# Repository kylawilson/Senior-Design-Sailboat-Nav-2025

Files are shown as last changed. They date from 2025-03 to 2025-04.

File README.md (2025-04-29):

# Senior-Design-Sailboat-Nav-2025

```
Senior-Design-Sailboat-Nav-2025
│   README.md  
│
└───Anemometer
│   │   AneTest.py
│   │   WindDirection1.py
│   │   WindSpeed.txt
│   
└───GPS
│   │   GPSDbusTest.py
│   │   gps_dbus_test
│
└───HARDWARE-REPORT
│   │   README_Hardware.md
│   └───DATASHEETS
│       │   Aluminum_pole.pdf
│       │   DS-15901-Weather_Meter.pdf
│       │   FlangeSpecs.pdf
│       │   GPS-Module-Datasheet.pdf
│       │   OAK-D-S2_Datasheet.pdf
│       │   PowerBank_Main.pdf
│       │   PowerBank_Secondary.pdf
│       │   RJ11_schematic.pdf
│       │   Rubber_ring_specs.pdf
│       │   StereoPiV2Schematic.jpg
│       │   StereoPi_07292021_STPI2_SLM_01-2499177.pdf
│       │   SwivelSafetyHaspSpecs.pdf
│       │   Tectite Electrical Plastic Adapter Connector Conduit Fittings.pdf
│       │   adafruit-4-channel-adc-breakouts.pdf
│       │   cm4-datasheet.pdf
│       │   coupler_datasheet.pdf
│
└───LAUNCHER-SCRIPTS
│   │   oakd_launcher.sh
│   │   ...
│
└───OAK-D
│   │   MRS_Video.py
│   │   Triton.py
│   │   Waterline.py
│   └───models
│       │  ... 
│  
└───PREVIOUS-REPORTS
│   │   Customer Installation Report.pdf
│   │   Final Testing Report.docx
│   │   Final Testing Slides.pptx
│   │   ...
│
└───RPI-BLUETOOTH
│   │   bluetooth.py
│   │   README_Bluetooth.md
│   │   BluetoothInterfaceChart.jpeg
│
└───SOFTWARE-REPORT
│   │   README_Software.md
│
└───STEREOPI-BLUETOOTH
│   │   bluetooth.py
│   │   README_StereopiBluetooth.md
│
└───Triton
│   │   README_Triton.md
│   └───Triton
│       │  All_camera_10_points.swift
│       │  BluetoothService.swift
│       │  ContentView.swift
│       │  DataStructs.swift
│       │  ImageConversion.swift
│       │  info_tabs.swift
│       │  Info.plist
│       │  ServiceDefinitions.swift
│       │  TritonApp.swift
│
└───stereopi
│   │   7_2d_mapPROTO.py
│   │   Triton.py
│   └───calibration_data
│   │   │  ...
│   └───pairs
│       │  ...
```

This repo contains all of the relevant information for the Triton: a portable, multi-sensor system that provides useful information to the sailor via a mobile iOS application, including object sensing and visualization, GPS data, wind speed and direction, and speed over ground. The Triton's primary function being to assist sailors when docking or maneuvering through crowded areas, such as a busy port. The Triton consists of three separate sensing modules attached to the bow, starboard, and port areas of the boat. Each of these modules communicates via Bluetooth Low Energy. The data from each of these modules is continuously offloaded to the connected iOS device in real time, giving the operator the most up-to-date information about the current conditions.

**STEREOPIS (PERIPHERAL MODULES)**\
OS: Raspberry Pi Debain Bullseye 32-Bit Full Legacy (Released 10/22/2024)\
StereoPi Version: StereoPi V2 Slim\
Raspberry Pi Device: Compute Module 4, 1GB, Wireless (SC0691)

**RASPBERRY PI (CENTRAL MODULES)**\
OS: Raspberry Pi Debian Bookworm 64-Bit (Released 11/19/2024)\
Raspberry Pi Device: Raspberry Pi 3B

**COMMANDS, TIPS & TRICKS THAT CAME IN HANDY**
To activate virtual environment:\
source ./bin/activate

To get bluetooth working on Raspberry Pis:\
sudo systemctl start bluetooth

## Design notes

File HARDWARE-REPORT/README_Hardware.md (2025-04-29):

insert readme contents here
" Also includes a document highlighting how to setup the project and connect to external systems, sensors, etc.

• Schematic / PCB / CAD diagrams of all components of your project: please include in PDF format
AND the actual CAD / CAM files (would you want to redraw them from scratch?)
• Vendor information and Bill of Materials (BOM).
• References to significant data sheets, application notes, design templates, etc.
• Power requirements (voltage, current, power supply model, etc.).
• Clear picture of system inside the enclosure – use multiple angles if necessary.
• Significant data sheets, application notes, design templates, web resources.
• Photographs documenting the assembled system 

"

**Hardware Installation and Setup:**

The Triton is composed of three individual sensor modules that contain stereo cameras and other sensors to relay data to the app. These modules are placed within semi-permanent mounts that the user must install at specific locations on their ship prior to first use. (see Figure 1)

*Initial Installation*
- Using a flathead screwdriver, attach and tighten the hose clamps of the central module to the railing at the bow of the boat, ensuring the camera is facing away from your ship.  (Position 1 in Figure 1)
- Wrap the velcro on the sides of the module around a portion of the railing so that it is taut and attach the remaining slack to the velcro attached to the module. For best security, wrap it around the pole at least two times.  
- Using the flathead screwdriver, attach and tighten the hose clamps of the side modules to lifelines(side railings) at or close to the widest part of your boat. (Left module Position 2 and Right module Position 3 in Figure 1)
- Make sure to push down on both side modules to ensure the suction cups on the bottom of the modules are attached.
- Tighten or loosen the attached velcro so that it is snug against the lifeline pole and attach the remaining slack to itself.

*Before Every Use* 
- Connect the battery pack to each of the modules to power on the devices.
- Place each module in their respective mounted frames, making sure the modules are fully sealed to the frames.
- Place the buckle on the module on the latch attached to the frame and turn the latch so that it is in a horizontal position.  
- For best readings, raise the telescoping pole attached to the anemometer, wind vane, and GPS antenna by twisting the metal adjuster to the left to loosen and raise the pole then twisting the adjuster to the right to tighten and lock the position of the pole in place.
- Launch the iOS application and connect to the modules

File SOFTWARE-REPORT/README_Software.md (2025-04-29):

insert readme contents here
"Source code and executables along with the
accompanying documentation on how to
setup/compile your project and transfer code to
a target platform.

An overview of each software module
• A flow chart indicating the dependencies between these functions. For instance, if you have a
main.py and LCD.py, you need to show that LCD.py is a module used by main.py.
• Dev/build tool information: Package name and version info. For example, OpenCV 4.0.3 with
Python 3.8.1, using CUDA Toolbox 10.0 and GCC 9.1 and CMake 3.14.2
• How to install the project software stack from scratch (a blank hard drive / cloud instance) Please
provide concise documentation on what installation software is needed, and how to build from
source to binary as applicable. 

"

```
Senior-Design-Sailboat-Nav-2025
│   README.md  
│
└───Anemometer
│   │   AneTest.py
│   │   WindDirection1.py
│   │   WindSpeed.txt
│   
└───GPS
│   │   GPSDbusTest.py
│   │   gps_dbus_test
│
└───HARDWARE-REPORT
│   │   README_Hardware.md
│   └───DATASHEETS
│       │   Aluminum_pole.pdf
│       │   DS-15901-Weather_Meter.pdf
│       │   FlangeSpecs.pdf
│       │   GPS-Module-Datasheet.pdf
│       │   OAK-D-S2_Datasheet.pdf
│       │   PowerBank_Main.pdf
│       │   PowerBank_Secondary.pdf
│       │   RJ11_schematic.pdf
│       │   Rubber_ring_specs.pdf
│       │   StereoPiV2Schematic.jpg
│       │   StereoPi_07292021_STPI2_SLM_01-2499177.pdf
│       │   SwivelSafetyHaspSpecs.pdf
│       │   Tectite Electrical Plastic Adapter Connector Conduit Fittings.pdf
│       │   adafruit-4-channel-adc-breakouts.pdf
│       │   cm4-datasheet.pdf
│       │   coupler_datasheet.pdf
│
└───LAUNCHER-SCRIPTS
│   │   oakd_launcher.sh
│   │   ...
│
└───OAK-D
│   │   MRS_Video.py
│   │   Triton.py
│   │   Waterline.py
│   └───models
│       │  ... 
│  
└───PREVIOUS-REPORTS
│   │   Customer Installation Report.pdf
│   │   Final Testing Report.docx
│   │   Final Testing Slides.pptx
│   │   ...
│
└───RPI-BLUETOOTH
│   │   bluetooth.py
│   │   README_Bluetooth.md
│   │   BluetoothInterfaceChart.jpeg
│
└───SOFTWARE-REPORT
│   │   README_Software.md
│
└───STEREOPI-BLUETOOTH
│   │   bluetooth.py
│   │   README_StereopiBluetooth.md
│
└───Triton
│   │   README_Triton.md
│   └───Triton
│       │  All_camera_10_points.swift
│       │  BluetoothService.swift
│       │  ContentView.swift
│       │  DataStructs.swift
│       │  ImageConversion.swift
│       │  info_tabs.swift
│       │  Info.plist
│       │  ServiceDefinitions.swift
│       │  TritonApp.swift
│
└───stereopi
│   │   7_2d_mapPROTO.py
│   │   Triton.py
│   └───calibration_data
│   │   │  ...
│   └───pairs
│       │  ...
```

**HOW TO SET UP SOFTWARE ON A NEW RASPBERRY PI**
1. Clone this repo (Senior-Design-Sailboat-Nav-2025) in the top level of your Raspberry Pi
2. Ensure that the paths used in LAUNCHER-SCRIPTS/oakd_launcher.sh match the layout of your device (it should as long as you clone the repo in the right place)
3. Edit the crontab (sudo crontab -e)
4. Add this line to the crontab: @reboot ~/Senior-Design-Sailboat-Nav-2025/LAUNCHER-SCRIPTS/oakd_launcher.sh
5. Reboot the pi (sudo reboot) 

**HOW TO SET UP SOFTWARE ON A STEREOPI/CM4**
1. Clone this repo (Senior-Design-Sailboat-Nav-2025) in the top level of your StereoPi/CM4
2. Ensure that the paths used in LAUNCHER-SCRIPTS/stereopi_launcher.sh match the layout of your device (it should as long as you clone the repo in the right place)
3. Edit the crontab (sudo crontab -e)
4. Add this line to the crontab: @reboot ~/Senior-Design-Sailboat-Nav-2025/LAUNCHER-SCRIPTS/launcher.sh
5. Reboot the pi (sudo reboot) 

**List of Dependencies**
- Python Version 3.11.2
- dbus-python Version 1.0
- PyGObject Version 3.0

**WHAT DOES EACH MODULE DO?**
Read the READMEs in each folder to find out!

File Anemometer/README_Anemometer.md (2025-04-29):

**DEPENDENCIES**
- dbus-python 1.3.2
- gobject 0.1.0
- adafruit_ads1x15
- adafruit_blinka 8.56.0
- RPi.GPIO 0.7.1

**DEVICE REQUIREMENTS**
- Raspberry Pi 3B with Raspberry Pi OS Debian Bookworm 64-Bit
    
**OVERVIEW OF EACH SOFTWARE MODULE**\
*AneTest.py* - This file reads wind speed data from a GPIO pin connected to the anemometer. It counts pulses from the anemometer to calculate the wind speed in meters per second, then converts it to knots. The result is written to a text file (WindSpeed.txt) once per second.\ 
*WindDirection1.py* - This file reads wind direction data using an ADC connected over I2C. It calculates resistance values from voltage readings to determine wind direction based on predefined resistance ranges. The result is made available over a DBus service, allowing other applications to query the current wind direction. The file initializes the ADC, sets up and runs a D-Bus service, and continuously samples and averages multiple readings from the anemometer to improve accuracy.

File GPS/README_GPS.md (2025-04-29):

**DEPENDENCIES**
- WiringPi (<wiringSerial.h>)
- <dbus/dbus.h>
- <sys/time.h>

**DEVICE REQUIREMENTS**
- Raspberry Pi 3B with Raspberry Pi OS Debian Bookworm 64-Bit
    
**OVERVIEW OF EACH SOFTWARE MODULE**\
*GPSDbusTest.cpp* - This file interfaces with the Adafruit Flora GPS module over a serial connection. It processes NMEA sentences (GGA, RMC, PGTOP) to extract GPS data such as latitude, longitude, speed, and course over ground. The data is then made available via DBus. The service listens for requests for GPS data and responds with the latest parsed information. The code  continuously reads from the GPS and updates the D-Bus service.\ 
*gps_dbus_test* - This is the executable version of GPSDbusTest.cpp

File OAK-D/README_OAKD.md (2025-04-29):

• An overview of each software module
• A flow chart indicating the dependencies between these functions. For instance, if you have a
main.py and LCD.py, you need to show that LCD.py is a module used by main.py.
• Dev/build tool information: Package name and version info. For example, OpenCV 4.0.3 with
Python 3.8.1, using CUDA Toolbox 10.0 and GCC 9.1 and CMake 3.14.2

Software Overview:
Triton.py: The OAK-D and Trition's object detection script that utilizes both the neural net object tracking as well as the grid system
to record and determine the relevant data of detected objects and prepare the data to be sent to the app. The detection system consists
of two parts, a 10x10 grid of region of interests which records the depth of each region through openCV. The minimum distance for each
ROI column is then recorded and stored in an array. The second system is a neural net that identifies and tracks boats and draws a dynamic
ROI around each object and records the distance of the object (if within range) and its position relative to the camera. The data from the
two systems in then stored and sent over DBUS and then sent via BLE to the app.

MRS_Video.py: Testing script for recording video of the multi ROI grid object dection system

OTV.py: Testing script for recording video of the neural network and object tracking system

Waterline.py: Testing script for unfinished feature to dynamically track the horizon so that the system can actively ignore depth readings
from the surface of the water. Based of the work done by Tim Huff to dynamically track the horizon for autonomous drones. Uses open CV to
track features on the horizon and draw an estimated horizon line.

**DEPENDENCIES**
- blobconverter             1.4.3
- depthai                   2.28.0.0
- opencv-python             4.10.0.84
- nbclient                  0.10.2
- nbconvert                 7.16.6
- nbformat                  5.10.4
- Python                    3.11
- dbus-python 1.3.2

**DEVICE REQUIREMENTS**
- OAK-D Stereo Camera
- Raspberry Pi 3B

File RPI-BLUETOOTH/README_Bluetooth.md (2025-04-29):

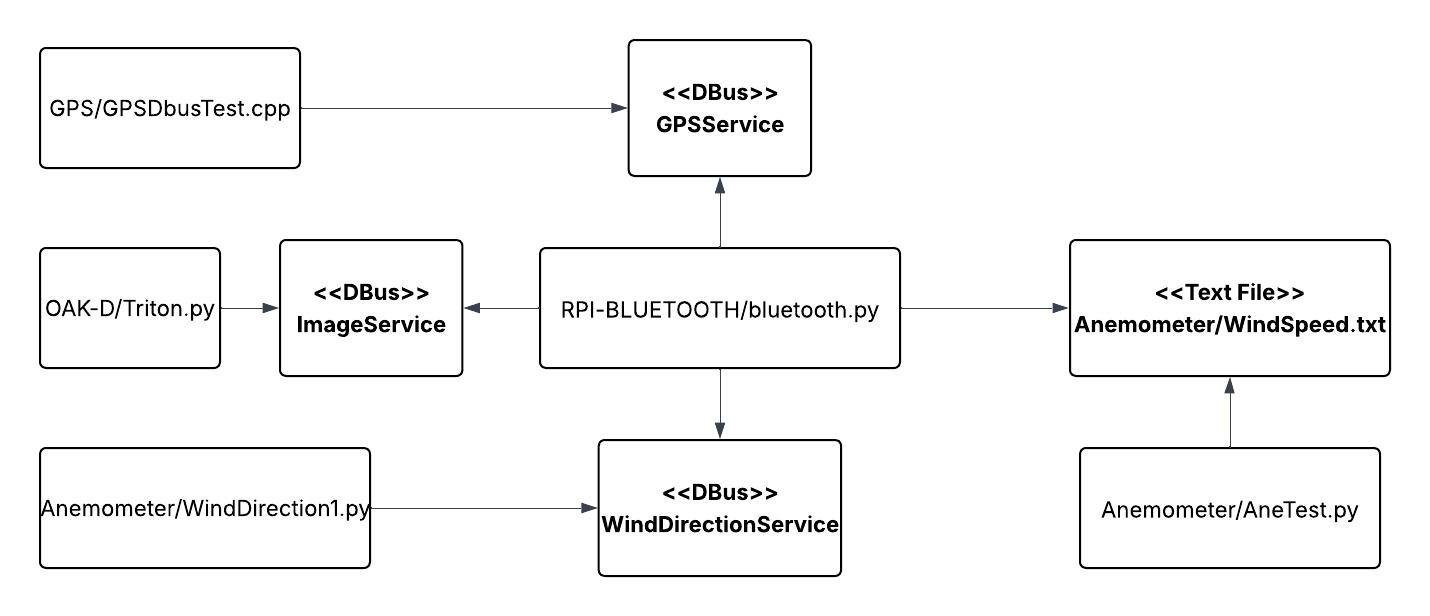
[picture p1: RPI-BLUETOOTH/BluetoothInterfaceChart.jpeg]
Flowchart Bluetooth Interface Chart


**DEPENDENCIES**
- dbus-python 1.3.2
- gobject 0.1.0
- pillow 11.10
- datetime 5.5
- Python 3.11
- ../OAK-D/Triton.py
- ../GPS/gps_dbus_test
- ../Anemometer/AneTest.py and ../Anemometer/WindDirection1.py

**DEVICE REQUIREMENTS**
- Raspberry Pi 3B with Raspberry Pi OS Debian Bookworm 64-Bit
- To Run Dependencies:
    - Oak-D Camera
    - Adafruit Flora GPS Module
    - Anemometer (Wind Direction and Speed)
    - 16-Bit ADC
    
**OVERVIEW OF EACH SOFTWARE MODULE**\
bluetooth.py - This file enables Bluetooth Low Energy communication with the iOS device (see the ../Triton folder). It registers the GATT server, advertisements, services, and characteristics. This file also collects information from the OAK-D camera via dbus, the GPS module via dbus, the Wind Direction module via dbus, and the Wind Speed module via a file.

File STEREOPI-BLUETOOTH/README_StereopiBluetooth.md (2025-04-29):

**DEPENDENCIES**
- dbus-python 1.3.2
- gobject 0.1.0
- ../stereopi/7_2d_map_PROTO.py

**DEVICE REQUIREMENTS**
- StereoPi V2 Slim with a Raspberry Pi Compute Module 4 running Raspberry Pi Debian Bookworm 64-Bit
- Two Raspberry Pi Cameras
    
**OVERVIEW OF EACH SOFTWARE MODULE**\
bluetooth.py - This file enables Bluetooth Low Energy communication with the iOS device (see the ../Triton folder). It registers the GATT server, advertisements, services, and characteristics. This file also collects information from the stereo cameras, reading from tempmax_log.txt in the ../stereopi folder to collect these values once every second.

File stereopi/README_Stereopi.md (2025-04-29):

**StereoPi Code**

Utilizied for StereoPi Sensors.

**Dependencies:**

Raspberry Pi Debain Bullseye 32-Bit Full Legacy

Python3.11

OpenCV 3.4.3

Picamera 1.13

These files enable functionality of the Stereopi cameras and allow them to track depth and to map distance.

**Overview of Modules:**

1_test_py - shows camera preview, ensures that cameras are functioning

2_chess_cycle.py - Takes a series of 50 pictures for stereo calibration. Pictures need to have a chessboard design.

3_pairs_cut.py -Takes the samples from 2_chess_cycle.py and arranges the left and right phots into pairs.

4_calibartion_fisheye.py - Takes the samples from 3_pair_cut.py to create the Calibration Data.

5_dm_tune.py - Adjuts the Disparity Map for precise needs.

6_dm_video.py - Builds the disparity map.

7_2d_map.py - Builds the depth map.

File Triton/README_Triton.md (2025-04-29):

<p align="center">
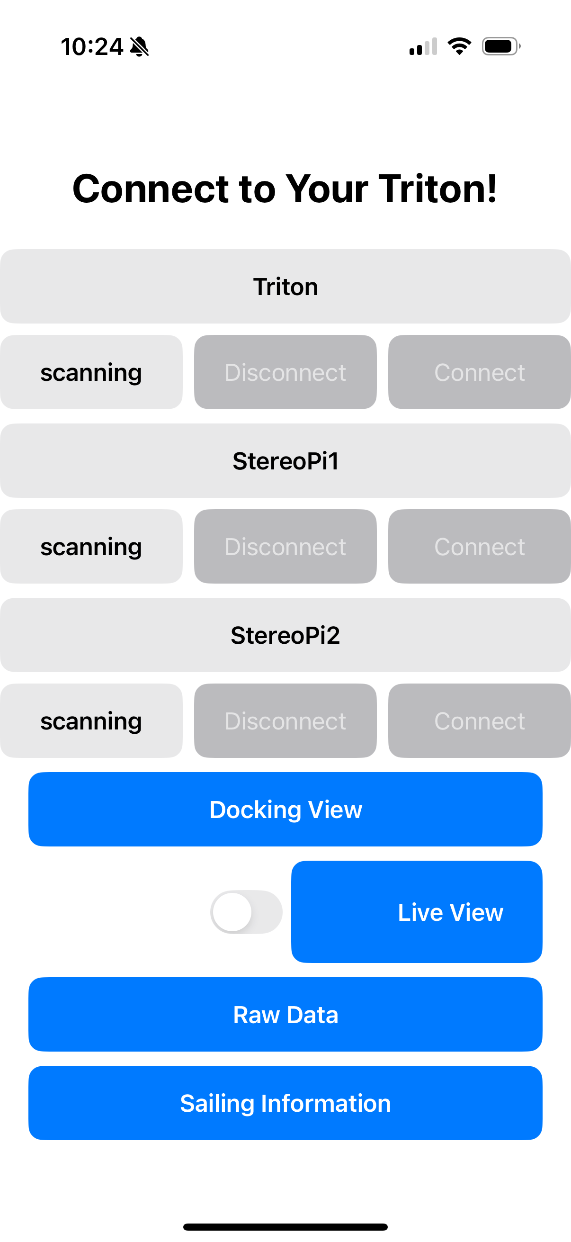
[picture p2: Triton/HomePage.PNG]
Home Page of App
  
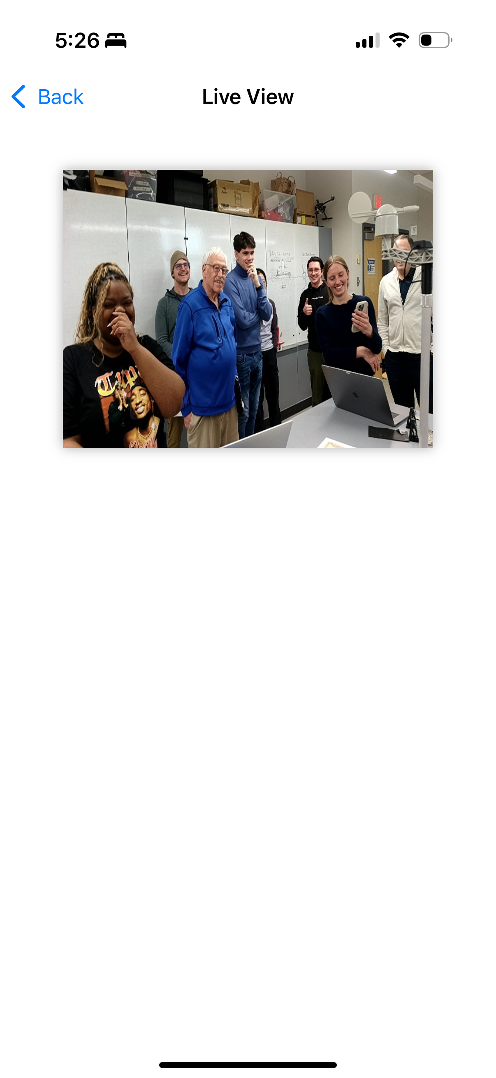
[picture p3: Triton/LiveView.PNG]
App's Live View
  
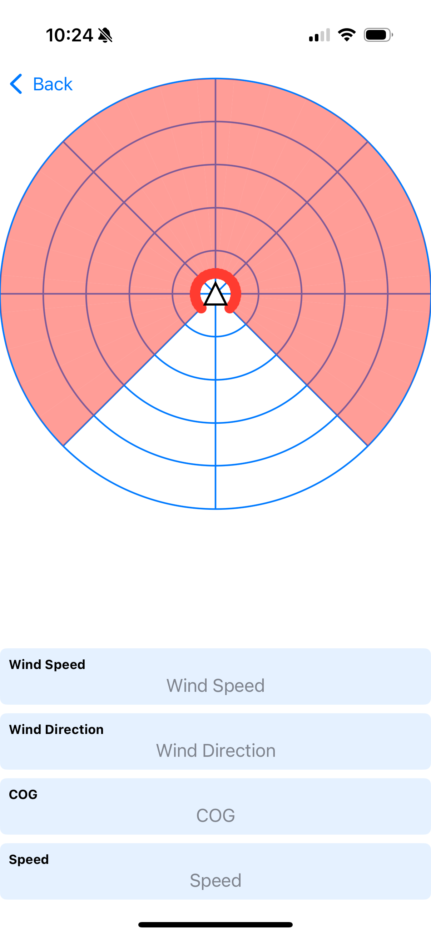
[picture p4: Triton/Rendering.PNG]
Rendering Default
  
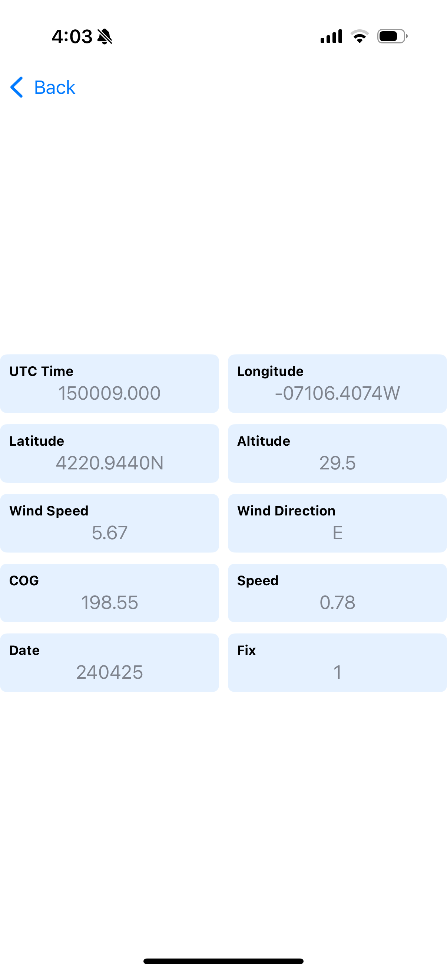
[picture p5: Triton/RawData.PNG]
Populated Raw Data Page
  
</p>

**DEPENDENCIES**
- CoreBluetooth
- SwiftUI
- XCode 16.3 or Higher

**DEVICE REQUIREMENTS**
- For Development: A Mac with XCode 16.3 or Higher
- For Running the App: An iPhone with iOS 18 or Higher

**DEVICES USED**
- For Development: MacBook Pro, 16-inch, 2019, macOS Sequoia 15.3.2
- For Testing: 
    - iPhone 11 Pro, iOS 18.1.1
    - iPhone 16 Pro, iOS 18.3.2
    
**OVERVIEW OF EACH SOFTWARE MODULE**\
*All_camera_10_points.swift* - This is the code that converts the depth and object recognition data provided by the OAK-D and StereoPi cameras. The cameras use a grid-like depth map and send the smallest distance for each column over Bluetooth. The rendering converts each distance value into a polar point on a map. As the depth values change, the polar points adjust their position accordingly. If the OAK-D detects a boat or person they will be represented as a colored triangle at their approximate location or on the edge of the map if they are farther than 15 meters away.\
*BluetoothService.swift* - This is the code that controls and manages the bluetooth connection between the iOS device and the Triton (main module) and StereoPis (peripheral modules). This includes connecting, disconnecting, discovering services, receiving and parsing data, and more.\
*ContentView.swift* - This is the top-level file that defines the application's UI and layout.\
*DataStructs.swift* - This file contains two of the data structs that we created to organize our data better: one for GPS data and one for Anemometer data. This allows us to have simpler data extraction for the UI once the data is parsed in BluetoothService.\
*ImageConversion.swift* - This file contains all of our functions related to converting the serial data of the OAK-D's live view to a viewable image within the application.\
*info_tabs.swift* - This is a section that delivers general information for how to safely approach and dock a ship as well as what the proper right of way rules are regarding open sailing.\
*Info.plist* - This is the information property list file, a file used by Apple that contains configuration information for the application. The most important use of this in our app is for Bluetooth permissions.\
*ServiceDefinitions.swift* - This file contains all of the Service Definitions for our app. It contains all of the UUIDs for the characteristics, services, and connection statuses.\
*TritonApp.swift* - This is the top level module that is our app. It instantiates ContentView to display our UI within Swift's app structure.\

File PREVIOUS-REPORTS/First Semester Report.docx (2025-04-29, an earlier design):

# Boston University

# Electrical & Computer Engineering

# EC463 Senior Design Project

# First Semester Report

Triton

Submitted to

Ryan Lagoy

1 Silber Way

Boston, MA 02215

(617)-877-2569

rlagoy@bu.edu

by

Team 25

Sail-Nav Technologies

Team Members

Leyandra Burke lburke@bu.edu

Kevin Connell kconn7@bu.edu

Diego D’Angelo-Cosme diegodc@bu.edu

Matthew Guacho mguacho@bu.edu

Kyla Wilson kylaw@bu.edu

Submitted: 12/08/2024

#### Table of Contents

Executive Summary (Diego D’Angelo-Cosme) 2

1.0 Introduction (Matthew Guacho) 1

2.0 Concept Development (Kyla Wilson) 2

3.0 System Description (Kevin Connell and Kyla Wilson and Leyandra Burke) 5

4.0 First Semester Progress (Diego D’Angelo-Cosme and Kevin Connell and Kyla Wilson and Leyandra Burke and Matthew Guacho) 7

5.0 Technical Plan (Leyandra Burke and Matthew Guacho) 11

6.0 Budget Estimate (Diego D’Angelo-Cosme) 14

7.0 Attachments (Diego D’Angelo-Cosme) 15

7.1 Appendix 1 – Engineering Requirements 15

7.2 Appendix 2 – Gantt Chart (Leyandra Burke) 16

7.3 Appendix 3 – Prototype Circuit Diagram (Diego D’Angelo-Cosme) and Pinout (Kyla Wilson) 18

7.4 Appendix 4 – Other Appendices 20

(right click on Table of Contents to update fields and page numbers automatically)

# Executive Summary (Diego D’Angelo-Cosme)

Sailboat Navigation and Docking Assist: The Triton

Team 25 – Sail-Nav Technologies

Maritime navigation and docking can be incredibly challenging, especially on a sailboat; there are many environmental factors and visual limitations that can prove challenging for both new and experienced sailors. Team 25 has proposed ‘The Triton’ to solve this issue. The Triton is a portable, multi-sensor system that will provide useful information to the sailor including object sensing and detection, GPS data, wind speed and direction, speed through water, and speed over ground. This will be done using an anemometer, a paddle wheel, a GPS module, and multiple stereo cameras mounted around the vessel. Many sailboats do not have sensors and rely on a sailor’s general knowledge and expertise, so this device will allow newer sailors to gain experience docking and navigating while also providing a reliable information system for those with more experience.

# 1.0 Introduction (Matthew Guacho)

Nautical voyages can be extremely dangerous: the margin of error is wide and the price to pay is massive. In fact, in 2023 alone, 564 people perished and 63 million dollars in damages were attributed to boating-related accidents. One of the most challenging parts of nautical activities is docking the vessel, with crowded ports and outside factors, such as wind or currents, potentially leading to accidents. Our client wishes to make a system that solves this problem: a system that aids the sailor, regardless if they are a novice or a master, in docking their vessel, as well as offering some assistance with marine voyages.

Team 25 aims to solve this problem with The Triton, a multi-sensor system designed for docking and nautical navigation. The Triton will implement multiple sensors that sense vital information during the boating experience, and send all relevant information to an iOS phone application via Bluetooth low energy (BLE). Using this information, the app will make recommendations to the user during the docking process. The system will be able to detect nearby objects, sense wind speed and direction, utilize GPS information to obtain speed over ground (the speed of a vessel over the Earth's surface), and to be able to measure the speed through water (speed of vessel in relation to the water). All of these attributes will give the sailor an in-depth understanding of the current sailing conditions, giving the sailor information that they would otherwise not have access to. Utilizing this information, the sailor can know how to react to certain situations given the current conditions, and even get recommendations as to what actions should be taken.

Team 25’s approach to creating the Triton is to make a system that is reliable, yet cost effective. There are other nautical assistance systems on the market, but they lack any real aid when it comes to docking by sail, and they can be exceedingly expensive, with some systems costing as much as 10 thousand dollars. Additionally, few systems are compatible with sailboats. The Triton will use essential sensors that can solve the docking problem in the most cost efficient way possible, as well as lasting as long as 12 hours, being able to withstand harsh weather conditions, and be used on a wide gamut of nautical vessels. Using the iOS app, the product can also expound what would be the wisest decision when it comes to docking, answering our client’s request to give sailors more knowledge to tackle marine situations. This will give the sailor a full understanding of their environment, thus giving them the information needed to effectively respond to any situation. With the ability to recommend actions as well, The Triton can help sailors of any skill level, whether they are just beginning or master voyagers.

Special features of The Triton include a full suite of sensors that read essential information, an app that can show such information and make recommendations to the user, and weigh at most 25 pounds. This ensures that anyone can use the system and that it can be easily installed, removed, and transported.

# 2.0 Concept Development (Kyla Wilson)

Understanding the Problem

To properly address our client’s problem, we first needed to understand the challenges faced by sailors out on the water. While no one in our group is a sailor, we all chose the project because of its unique challenges and the opportunity it gave each of us to develop our engineering skills. At the beginning of the semester, we met with our client Ryan Lagoy to understand more closely what he was hoping the result would be when he proposed this project. We walked away from that initial meeting with a handful of imperative items, and lots of information on potential creative ways to solve our problem. The most important points for us to hit after our initial meeting were:

- Wind speed and direction
- Collision avoidance and warning
- Dock vs boat detection
- Distance from dock
- Speed through water and speed over ground
- Waterproof, functional housing

From there, we were able to begin scouting parts for our prototype. We initially pulled a GPS module that would provide the date, UTC time, longitude and latitude, longitude and latitude indicators, altitude, course over ground, and speed; an anemometer that measures wind speed; a wind vane that measures wind direction; a stereo camera with object detection abilities; supplemental Bluetooth modules; and the microcontroller that would control our system. At this point, our group met and decided on our initial plan for developing our prototype. We wanted to choose a prototype concept that was feasible for our time frame but also allowed our client and professors to see the pipeline of data we were creating. We decided to focus on creating the base of our system for our prototype and to build upon the base modularly thereafter. Our “base,” we decided, would be the iPhone app communicating with the Raspberry Pi via Bluetooth low energy, and the first modules we would add for our prototype would be the Oak-D camera and the GPS module. From here, we decided to order the parts that we would use in our prototype. We ordered the GPS module, borrowed the Raspberry Pi 3b from our teammate Leyandra, and our client Ryan Lagoy kindly donated the Oak-D to us until our project is completed in the spring.

Our group was given the opportunity to go sailing on the Boston Harbor on October 30. Up until this point our group wanted to focus on sailing in open water, exiting and entering ports/harbors, and providing support for docking. However, after we went sailing, our team realized that in order to accomplish all of these tasks, we would need much more time and manpower. Because of this, we decided to rescope our project to focus on docking. To enable this change, we had to change our priorities and consequently our system design. We restructured our priorities to focus our time on these aspects, in this order:

1. Bluetooth/App
2. Housing
3. Battery
4. OAK-D camera
5. Side camera sensors
6. GPS
7. Speed through water
8. Wind speed/direction

Our first priority for our project was getting our Bluetooth communication working. This is an integral piece of our product, and without it, our sensors cannot communicate with the user. From there, our next highest priority is housing. Because this system will be mounted on a sailboat, we need to absolutely ensure that the system is secure and waterproof. Our client requested durability of IP 68 from our system, which we intend to meet. Without secure and waterproof housing, our system is at risk of failure in critical scenarios like docking. To tackle this challenge, we are using a clamp system to mount the Triton to a sailboat. The clamps will be easily adjustable and removable to allow for the portability of the system, which was another request from our client. After housing, we prioritized battery. Our client has requested 12 hours of use on a full battery charge, so we will consistently monitor our power consumption throughout our development process and add to it modularly as needed to be able to support that metric. Next, we have placed the Oak-D camera. The Oak-D camera is incredibly important for our application, allowing us to enable a live view of the front of the boat, which is often blocked during sailing by the front and main sails. It is also a stereo camera, giving us depth measurements to help avoid collisions, and supports object detection capabilities. Next, we have the side camera sensors. These will allow us to sense objects on the sides of the boat during docking and are incredibly important to support potential collision warnings and drive our main use case of docking assist. After those five, we have our additional sensors: GPS, Speed through water, and wind speed/direction. While these sensors are each very important in our context of sailing, because we rescoped our project to focus on docking we are prioritizing the components of our system that will be able to add value early on for our client, and we believe that the Oak-D stereo cameras will be the greatest sensor value-adds to our system. We also believe that these sensors can be easily added down the road.

System Design

Once we properly understood the problem we were trying to solve and identified our priorities, we moved forward with designing our solution. In our solution, we prioritized having as many components consolidated as possible. This was due to the request for easy mount and easy removal, as well as portability by our client. Similarly, our team liked the idea of having as many sensors wired as possible for lower latency, more straightforward communication protocols, and less power consumption. We built our system around the Raspberry Pi 3b, the computer we selected for the Triton. We chose this single-board computer because it has onboard memory, built-in Bluetooth, and can support the Oak-D camera. We considered an Arduino Uno microcontroller but thought that the flexibility to run different operating systems and multiple programs at once on the Raspberry Pi was worth it. From there, we will attach the GPS module, the Oak-D camera, the anemometer, and the wind vane directly to the Raspberry Pi with wires. This “central module” or “central processing unit” as we call it, will house the bulk of our system and sensors. In addition to the central module, we will have two stereo cameras mounted on the port and starboard sides of the boat. We intend to have the user mount the stereo cameras on the widest point of the vessel on either side and mount the cameras facing outward. These stereo cameras will each be made from two Raspberry Pi cameras, a Stereo Pi board, and a Raspberry Pi CM4. We considered using a Raspberry Pi 3/3B with an Arducam stereo vision hat and two Raspberry Pi cameras, but our team had trouble sourcing the hat alone, and the sets were too expensive for our budget. This will enable the Triton to perceive depth on either side of the boat in docking scenarios. it is intended to only use these cameras when the user has indicated that they are beginning to dock to conserve power. These stereo cameras will send depth data to the central module via Bluetooth low energy, which the Raspberry Pi CM4 module supports. Our system will also include a speed through water module. While sourcing a sensor that provides speed through water has proven difficult, our team is currently favoring the idea of having a paddlewheel sensor which will be mounted at the stern of the boat with a small microcontroller and Bluetooth module to offload the information to the central module. We considered using a speed transducer or a pitot tube, but the speed transducer would have been too costly to the budget, and the pitot tube would entail a substantial engineering feat and would be incredibly challenging to calibrate.

# 3.0 System Description (Kevin Connell and Kyla Wilson and Leyandra Burke)

The product that the team is developing is a three stage system consisting of individual sensors, a CPU, and an iOS application. The Triton will be using a variety of sensors including, the Oak-D S2 stereo camera, two StereoPis, an anemometer, a GPS module, and a paddle wheel speed through water sensor. The stereo cameras will be responsible for tracking object distances using depth perception (Figure 1).

The Oak-D camera is able to alert the user of objects detected up to 12 meters away and their approximate location relative to the ship. This is accomplished by comparing the pixel values of two different images from each of the side cameras on the Oak-D creating a depth heat map (refer to figures 2 and 3). This heat map is then further broken down into a 10x10 grid of Region of Interests (ROI). The individual ROI’s then detect the distance of objects within their view and warn the user if the object is within a certain range. Additionally, the Oak-D will be trained with an image recognition model for nautical vessels as well as common obstacles found at sea. The system will be capable of recognizing these obstacles and alerting the user to what obstacles may be in the path of their vessel. The Oak-D has a horizontal FOV of 88 degrees when calculating depth and a visual FOV of 66 degrees. In order to combat this, the system will be mounted onto a motor to allow for a greater scanning field of view as well as the ability for the camera to follow a given obstacle giving the sailor a constant view of the object which may not be visible at the helm due to the sails blocking their view.

In addition to the Oak-D camera, two Stereo Pis will be mounted on the starboard and port sides of the vessel. The Stereo Pi’s are stereo cameras like the Oak-D used to calculate the distance to objects within its view. These camera’s primary use will be during docking, giving the sailor an unobstructed view of the docking side of the vessel. In addition to this, the cameras will work in a similar manner to that of the Oak-D, providing the distance of any obstacles within their field of view and sending alerts if an object appears to be within a dangerous range. These cameras will only be operating during the docking procedure reducing the power consumption of the system as a whole.

The iOS application is an application that connects via Bluetooth low energy to the Triton, the data acquisition system. The application is written in Swift and uses Apple’s Core Bluetooth framework to enable Bluetooth capabilities. When the user opens the application, it will immediately start scanning for the Triton, and will automatically connect to the device once it is discovered. Once connected to the Triton, the iOS application displays the data sent from the Triton in a tile format (see Figure 4), updating every time new data is received. If the connection between the iOS application and the Raspberry Pi (Triton) is lost, the iOS application will automatically re-establish the connection if the Triton is powered on and in range. The UI will also update every time the connection state changes, enabling and disabling certain buttons to ensure proper use, in addition to a tile that explicitly lists the connection state.

The Raspberry Pi/Triton Bluetooth will advertise a 16-bit UUID for the iOS application to discover when scanning. The Triton will host a GATT Server that holds an array of services, one service for each sensor (i.e. the GPS Service). Each service will have an array of characteristics belonging to it (i.e. longitude, latitude, altitude characteristics belong to GPS service). The advertisement from the Raspberry Pi’s Bluetooth module should be able to be discovered from at least 30 meters away, and not disconnect from the central unless it exceeds 40 meters in distance.

The GPS module used is an Adafruit wearable global positioning system, containing a MTK3339 chipset. The GPS uses satellite signals to determine the precise location of the sailboat. The module provides a multitude of different types of data. However, the most valuable data includes the longitude, latitude, universal time, date, altitude, speed over ground, and course over ground. This is the data from the sensor that will be integrated with the iOS application and displayed for the user. The module is designed for and being used with low power consumption operating with 3.3 volts with an average consumption of 25mA when actively being used. As well as having an accuracy and refresh rate updating every second, or 1Hz, based on the outputting NMEA data, when there is a good signal. To improve the performance of the GPS it will also have an antenna attached to it to increase the signal strength by 20 to 40 dB.

The anemometer will be used to detect wind speeds of at least 40 miles per hour and obtain the wind direction. This will be attached to a pole and placed at the highest point of the housing, with a direct wired connection to the CPU. Wiring of the anemometer consists of power, ground and signal. The data will then be sent to the iOS application through the CPU’s Bluetooth communication. Similarly, the paddlewheel will collect data of the vessel’s speed through water, and will be placed at the bottom of a pole submerged in the water at the back of the boat. The signal that will output from the paddlewheel is based on the rotation speed of the paddlewheel which is proportional to the boat's speed in the water. This will utilize a Bluetooth connection to the CPU to transmit its data. Both modules will be connected throughout the ship’s voyage.

Each of the modules will be connected to a Raspberry Pi, either via a wired connection or wirelessly. The wireless modules will communicate through integrated Bluetooth modules. The Raspberry Pis will handle a majority of the computation and handling of the sensor data.

# 4.0 First Semester Progress (Diego D’Angelo-Cosme and Kevin Connell and Kyla Wilson and Leyandra Burke and Matthew Guacho)

The team’s progress can be well defined by two periods of work. Phase 1 can be seen as the preliminary research and scoping phase, while phase 2 can be seen as the prototype building phase.

Phase 1:

After meeting with their client, Professor Lagoy, the team began brainstorming methods and implementations based on the requirements and feedback given. The team was focused on creating a device that would be equally helpful for sailing on open water as well as docking. An initial design was created with a telescoping pole acting as the primary housing for various modules and the CPU. The team believed that the pole would allow the system to be easily portable due to its retractable nature, and would serve to allow a speed through water sensor to easily be placed in the water while also having the anemometer for wind speed and direction placed high in the air using the other end of the pole. The other modules such as a LiDAR sensor would be placed and powered separately.

There was a hesitation with this design due to the fact that the CPU would be attached to the side of the boat rather than secured on the boat. Additionally, it was discovered when the team was looking to purchase an anemometer that they need to be placed roughly 30 meters in the air to obtain accurate data. This would be impractical for a lightweight and portable pole to sustain the weight of the anemometer at that height and to be that tall. Additionally, after much research, the team was unsure what technology to use in order to detect marine objects since many of the prevailing technologies were too complex, too expensive, or too unreliable for the product that was being built. The team then met with Professor Lagoy to address these concerns, and he explained that the accuracy of the anemometer may not be critically important; the data from the anemometer will be used mostly to help the sailor dock, where general knowledge of the speed and direction of the wind are valuable and do not need to be precise. Professor Lagoy also introduced a new alternative for detecting marine objects through a stereo camera with built-in AI capabilities, the OAK-D S2.

This meeting enabled the team to continue planning with a new focus on researching the OAK-D camera as the new primary method of object detection. A new design idea was also introduced to mount the system on the metal railing on the front of the boat with the speed through water module being placed on a pole in the back of the boat. This design would enable a safer location for the CPU and would allow most of the modules to be directly connected to it. This would become the new housing design going forward.

Later, the team would go sailing with Professor Lagoy and one of his associates Kay VanValkenburgh, a trainer for blind sailors. The team would get hands-on experience seeing how a sailboat maneuvers, how the sailor’s vision may be blocked or impaired, and how little information is readily available on a standard sailboat. The team would ask Professor Lagoy and Kay various questions about important sensors and boat functions for beginners. This experience would cause the team to want to rescope their project from a dual navigation and docking system to a docking assistance system with some navigation utilities. The team decided to purchase the OAK-D S2 camera as a means of using object detection and reassessed the priority of their hardware modules and came to the following list:

9. Bluetooth
10. Housing
11. Battery
12. OAK-D camera
13. Side camera sensors
14. GPS
15. Speed through water
16. Wind speed/direction

They also made a list of the following software implementation priorities after the initial application was developed:

1. Live view of the camera
2. GPS/Compass/Speed Through Water information
3. Warnings
  a. Audio
  b. Visual
4. Calibration

Phase 2:

After re-scoping the project with Professor Lagoy and finalizing the materials needed the team began work creating the prototype. The prototype consisted of three parts, the mobile app, GPS module, and the Oak-D camera. Each team member began work on each aspect of the project. Leyandra worked on the GPS implementation, and Kyla completed the Bluetooth implementation with Matthew’s assistance, Kyla worked on the app and getting a connection through Bluetooth, and Kevin and Diego worked on the Oak-D distance sensing and calibration.

The GPS portion began with wiring the GPS module to the Raspberry Pi. The GPS module uses UART protocols for its data transmission. The device was wired connecting the module to the transmitter (TX) and receiver (RX) pins, as well as the ground and 3.3 volts pins on the Raspberry Pi (see Appendix 7.3 for circuit schematic and hardware pinout). Once fully wired the Raspberry Pi configuration was modified in order to access the serial console where the GPS data would be outputted in NMEA format, a standard GPS manufacturing format (see Appendix 4 figure 6 for outputted example data). After enabling the serial port to receive data, a program was written to create a serial connection to allow for the NMEA data to be outputted to the terminal rather than the serial console.

Afterwards, NMEA data was analyzed and it was decided how such information was displayed on the iOS application. The data was parsed into two different NMEA taglines, GGA and RMC. With those identifiers specific lines could be sent to their respective function and isolate the relevant data by using a stringstream to split the line into fields based on the commas. Then storing the fields in a vector made it possible to correspond the indices to the data being used such as, latitude, the third field in the GGA tagline or date, the tenth field in the RMC tagline. With this data found it is then continuously stored and deleted from a .txt file ensuring only the latest data is in the file as it repeatedly updates. This file is then used for continuous updates when transferring data via Bluetooth.

For the app, we started by referencing a Bluetooth low energy example provided by Apple. To enable the iOS application to act as a Central/GATT Client and connect to a Peripheral/GATT Server, we chose to use Apple’s Core Bluetooth Framework in Swift. We chose Swift because it is the most straightforward and capable language for iOS application development, which the client specifically requested. The first feature we added was scanning or advertising peripheral devices. We started by enabling the app to scan for all Bluetooth devices and print each identified UUID or local name to the terminal in Xcode. This ensured that the scanning was working properly. From here, the supplementary functions were added which are called when the application connects to a peripheral, disconnects from a peripheral, discovers a service, discovers a characteristic, subscribes to notifications on a characteristic, etc. At this point, we had enabled advertising and had dummy characteristics added to the GATT Server on the Raspberry Pi side, so that testing could begin. A filter was added on the scanner to search only for the Raspberry Pi (Triton). Features such as a “Connect” button, discoverability, and server characteristics were added afterward. The dummy characteristic added two to the initial value every second from the Raspberry Pi side, and the iOS app received the updated value every second when subscribed and printed the value to the iOS terminal. After this was working, small changes were made in the code such as only subscribing to the characteristics that Matthew helped implement on the Triton’s side. Finally, the UI was overhauled, adding a connection status indicator, a connect button, and a tile for each of the GPS characteristics. Once all of the GPS characteristics were implemented on the Triton’s end, a full test of the application’s UI was conducted ensuring the GPS values were properly being updated on the Triton’s end.

For the Bluetooth implementation on the Raspberry Pi (Triton) end, we decided to use BlueZ and D-Bus to enable BLE. While not ideal, Python was chosen for Bluetooth functionality since the other sensors have more thorough, capable, and straightforward APIs in Python, but we hope to transition to C in the future for lower latency and less stress on the Triton during use. We started off by finding an example that created a GATT Server and initialized an advertisement. Next, we tested the advertising, connecting, and subscribing to characteristics from the custom iOS application. From here, the 16-bit advertising UUID was changed from one that indicates a heart rate service to A3A3. Then, the services and characteristics included in the example were removed and replaced with unique 128-bit UUIDs for each item. From here, subscribing to each of the characteristics was tested by porting the old “dummy” code into each of them, so that every GPS characteristic would update once per second and send its value to the phone. Once that was working, the dummy code was replaced with real code that parses the true GPS values from a .txt file that the GPS script writes to and reads them into the corresponding characteristic (this is a temporary solution that is planned to be updated next semester).

With the Oak-D, a provided base example code was used which highlighted a specific region of interest or ROI and gave a visual heat map of the distance record within the ROI. This base code was then taken and modified to create a 10x10 grid of ROI’s which relayed the depth of any object detected within its area up to a distance of 15 meters. Furthermore the code was changed to give the user a visual feedback as to the distance of certain objects by changing the color of the individual ROIs from green to yellow to red depending on the recorded distance within the ROI. Any ROIs distances within the red range (less than 1.5 meters) are then reported to the users and the distance and time is logged to a .txt file (see Figure 5). Afterwards the visual feed was then changed to give a live feed with ROI overlay in addition to the heat map.

Getting the Oak-D to run on the raspberry pi initially proved challenging as the program required a lot of processing time to update the 100 ROI’s every frame at 30 frames a second. To counteract this a few methods were used to try and reduce the load of the Oak-D on the system. First thing that was done was reducing the frame rate to 15 and the resolution of the feed was cut down as the live video feed of the ROIs was meant only for demonstration purposes. Additionally the ROI distance processing was smoothed to better reduce unnecessary calculations due to noise. Lastly some of the image processing and calculations were off loaded to the Oak-D itself reducing the overall computational strain on the Pi.

# 5.0 Technical Plan (Leyandra Burke and Matthew Guacho)

December 11, 2024 - December 31, 2024

Completion and Refinement of Preliminary Design and Preliminary Product

Task 1: Final Housing Design
Housing will be fully designed and integrated with all sensor types. The housing

and sensor choices have continuously changed throughout the semester and there is now full consensus on what is being used. This includes a CAD model of the mounting and housing components with defined materials and specifications based on theoretical calculations of, weight restriction of 25 lbs, and material cost and usage.

Lead: Leyandra Burke

Task 2: Power Budget

A power budget will be created with all current sensors and devices in order to

track what batteries need to be purchased and how much consumption of power is happening in the system. The power budget will be tested by including calculations of power usage of at least 12 hours.

Lead: Diego D’Angelo-Cosme

Assisted by: Kevin Connell

Task 3: GPS Data Retrieval Refinement

The current process of data retrieval from the GPS will be converted to a more efficient and processable form. The current system retrieves data in a storage intensive and non-ideal way making the updating to the Bluetooth file slower that will be changed. The system is currently updating the GPS IPC file every second. When transitioning to a new, more efficient process, this will be tested by ensuring the update rate can consistently be more frequent to allow for lower latency. The update rate should be at least once every ½ second.

Lead: Kyla Wilson

Assisted by: Matthew Guacho

January 1, 2025 - January 31, 2025

Intermediate Design and Subsystem Development

Task 4: Acquire All Housing Materials and Sensors

All materials and sensors will be purchased and delivered, ensuring all parts of the

project have every piece needed to complete the task. All materials, sensors, and miscellaneous things must not exceed the budget of $1000.

Lead: Kevin Connell

Assisted by: Diego D’Angelo-Cosme, Matthew Guacho

Task 5: iOS Application Skeleton Development

The iOS app will have a layout of the full user interface developed for each of the

components of data expected to be received from the Raspberry Pis. This will be

tested by usability testing received by potential customers feedback with an

approval rating of at least 85%.

Lead: Kyla Wilson

Task 6: Completion of Mounting Clamps

The mounting clamps will be completed and have detachable hinges for

connection to the housing structures. The mounting clamps will be tested by their

range of adjustability with diameter between 1” and 5” and can uphold a weight

of 10 lbs per clamp.

Lead: Leyandra Burke

February 1, 2025 - February 28, 2025

Finalization of Component Implementation

Task 7: Motorized Camera Stand

The Oak-D will be placed on a motorized stand to increase the field of view

(FOV). This will be tested by comparing the current FOV of 88 degrees for horizontal depth and 66 degrees visual with the projected FOV increased by a full range of 180 degrees and a 50% increase of FOV on both sides of the camera.

Lead: Leyandra Burke

Assisted by: Kevin Connell

Task 8: Media Transfer with Bluetooth

The live video feed from the Oak-D camera will be able to transfer through Bluetooth on the Raspberry Pi to the iOS application with a latency of 100 ms.

Lead: Kyla Wilson

Task 9: Sensor Circuit Implementation

Design and implementation of each sensor module’s circuit with secure and reliable connections. Include three different circuit schematics for each of the different modules.

Lead: Diego D’Angelo-Cosme

Assisted by: Kevin Connell

Task 10: Sensor Modules Completed with Parsed Data

All sensor modules will be wired and output their respective data in an easily readable format for transferring through Bluetooth. All modules will be optimized for working with each other, being tested at an updating rate of 1 second.

Lead: Matthew Guacho

Assisted by: Leyandra Burke, Diego D’Angelo-Cosme

Task 11: Train Oak-D Camera

The Oak-D will be trained with the relevant datasets to recognize common obstacles encountered during sailing. The Oak-D will be able to recognize objects within 15 meters with an accuracy of 80% and an accuracy of 65% for objects detected at a distance of 25 meters.

Lead: Diego D’Angelo-Cosme

Assisted by: Kevin Connell

March 1, 2025 - April 1, 2025

Integrating Components and Initialization

Task 12: Integration of Sensor Data with iOS Application and Bluetooth

The iOS app and the Bluetooth connectivity of the Raspberry Pi with all the sensor module data will have a consistent and reliable connection for distances of at least 35 feet. Data transfer and processing speeds will be tested to maintain a range between 1.6 GHz to 2.5 Ghz.

Lead: Kyla Wilson

Assisted by: Leyandra Burke, Diego D’Angelo-Cosme, Kevin Connell, Matthew

Guacho

Task 13: Integration of All Components with Housing

All components will be integrated and placed within the housing and have the capability to be mounted on different types of sailboats. The fully integrated system should have an IP68 waterproof rating and be able, weigh less than 25 lbs and be able to fit in an average sized backpack.

Lead: Leyandra Burke

Assisted by: Kyla Wilson, Diego D’Angelo-Cosme, Kevin Connell, Matthew

Guacho

# 6.0 Budget Estimate (Diego D’Angelo-Cosme)

Item | Description | Donated | Cost
1 | OAK-D Camera (1) | Y | $250
2 | GPS Module (1) | N | $25
3 | StereoPi (2) | N | $120
4 | Anemometer (1) | N | $150
5 | Speed Transducer (1) | N | $110
6 | Battery Packs (3) | N | $200
7 | Raspberry Pi 3B (1) | Y | $30
| Total Cost | | $885

The OAK-D camera was donated to the team by their client, due to its high cost. This camera is vital, though, because of its AI capabilities with object detection. A major challenge that was encountered when attempting to create a viable implementation of object detection was that other technologies, such as radar and LiDAR, were either more expensive or more complex with little functionality. This camera detects objects in an easy-to-implement manner and for a price that is still cheaper than other technologies. The other cost amounts listed take into account if multiple of the same module are necessary. For example, the battery packs are listed as $100, but this budget estimate is for all three batteries, not a single one.

# 7.0 Attachments (Diego D’Angelo-Cosme)

# 7.1 Appendix 1 – Engineering Requirements

Team #25 Team Name: Sail-Nav Technologies

Project Name: The Triton

Requirement | Value, range, tolerance, units
Data Collected | speed through water, speed over ground, wind speed, wind direction, object detection, GPS
Battery Life | 12 hours
GPS Accuracy | <20 meters
Total Weight | <25 lbs
Object Detection Range | 1 ≤ x ≤ 12 meters
Data Refresh Rate | 1 second
Weatherproof Rating | IP68

# 7.2 Appendix 2 – Gantt Chart (Leyandra Burke)

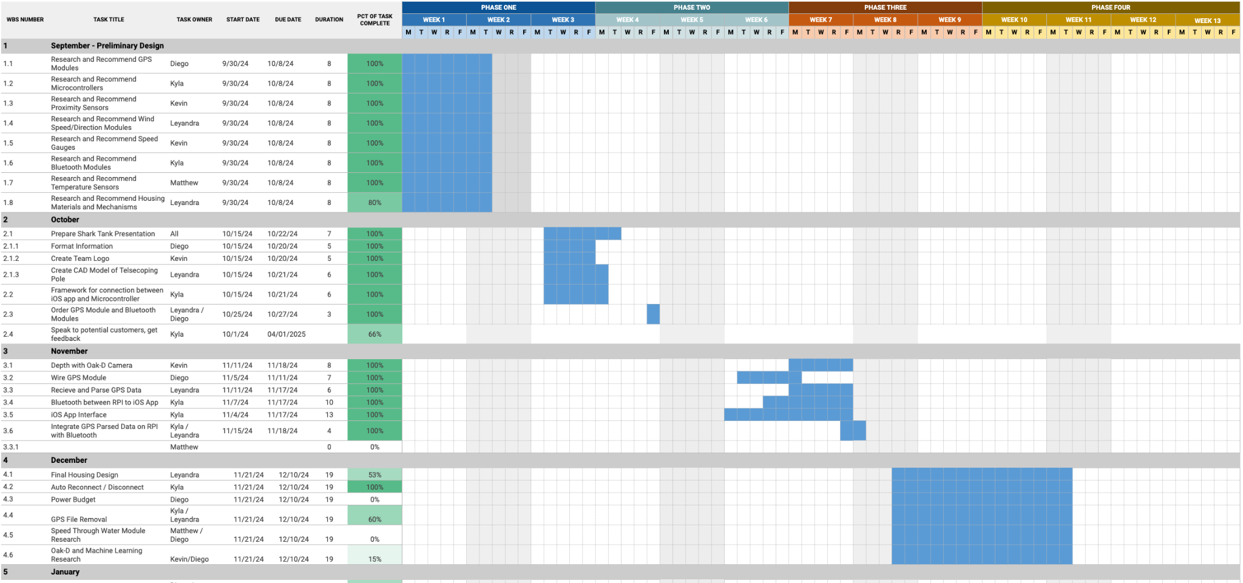
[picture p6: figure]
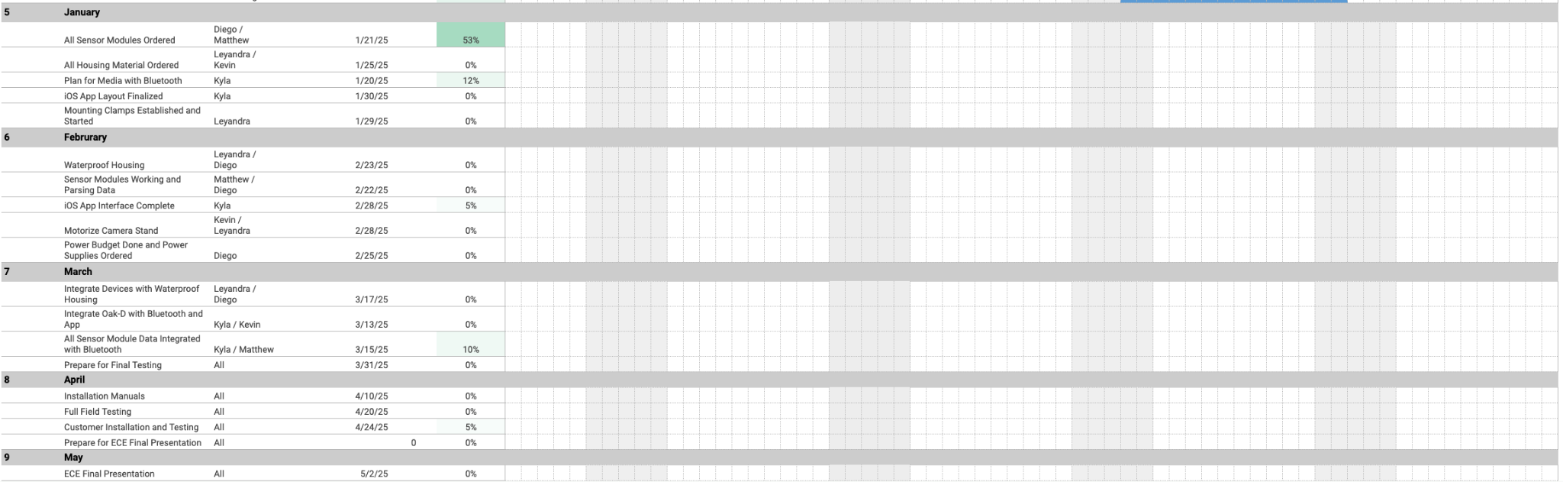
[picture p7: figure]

# 7.3 Appendix 3 – Prototype Circuit Diagram (Diego D’Angelo-Cosme) and Pinout (Kyla Wilson)

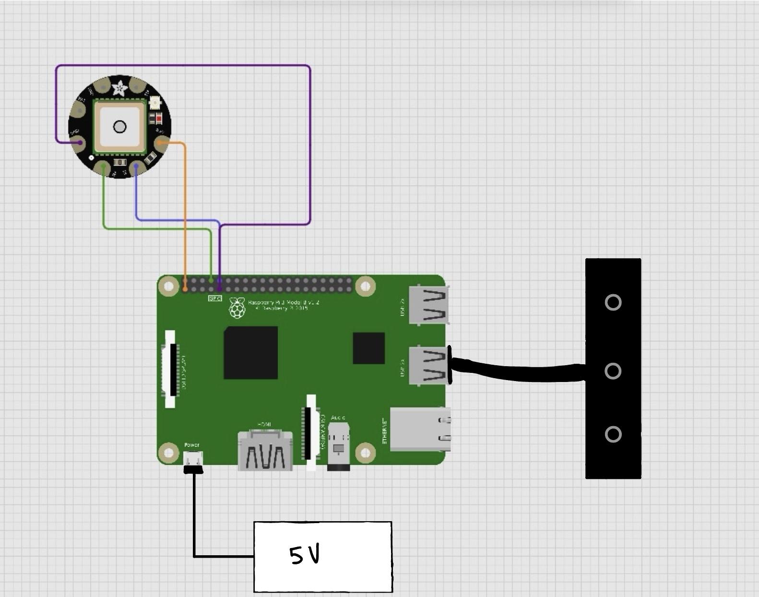
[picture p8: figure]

Hardware Pinout

Raspberry Pi | Peripheral
Pin 1, 3.3V | GPS 3.3V
Pin 9, GND | GPS GND
Pin 8, TX | GPS RX
Pin 10, RX | GPS TX
USB Port | OAK-D

# 7.4 Appendix 4 – Other Appendices

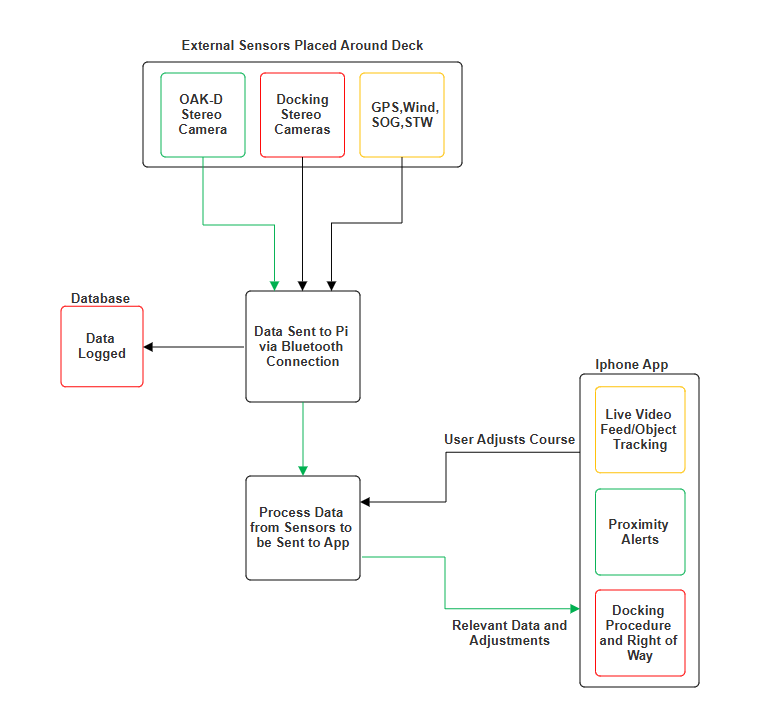
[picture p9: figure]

Figure 1. Block Diagram of the Triton. Blocks highlighted in green, yellow, and red indicate systems currently operational, currently being worked on and systems to be worked on in the future respectively

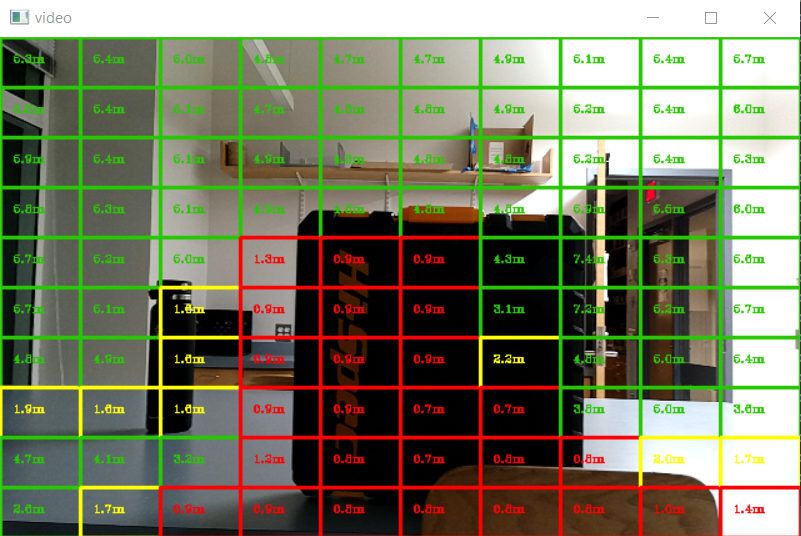
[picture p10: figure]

Figure 2. Live video from the Oak-D central camera with ROI overlay

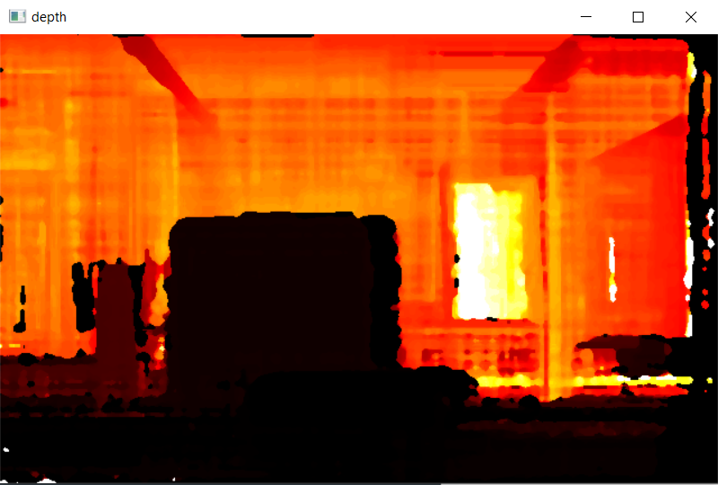
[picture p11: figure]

Figure 3. Heat map constructed from the stereo cameras of the Oak-D with darker and lighter sections representing a greater and lesser pixel disparity respectively

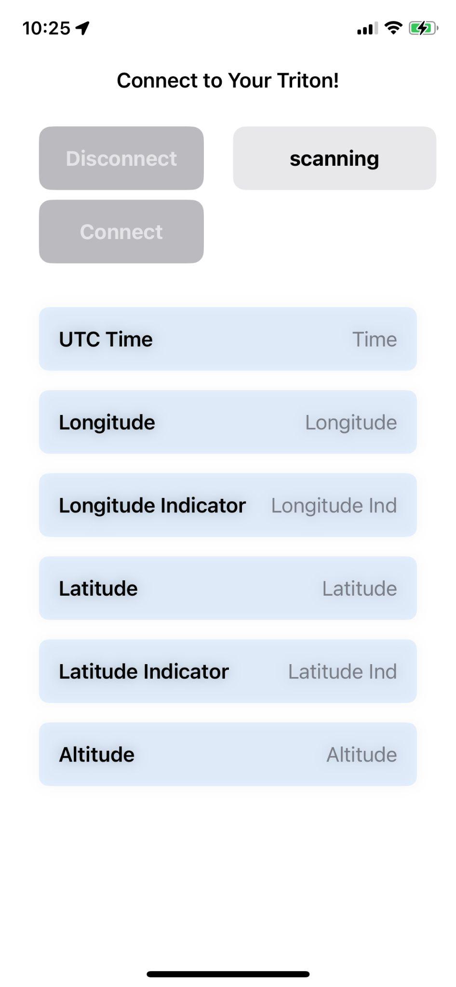
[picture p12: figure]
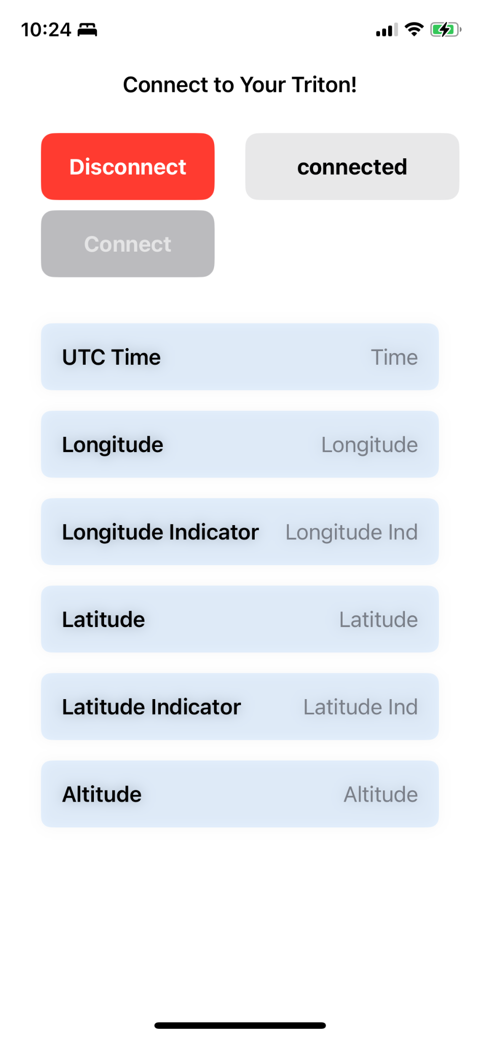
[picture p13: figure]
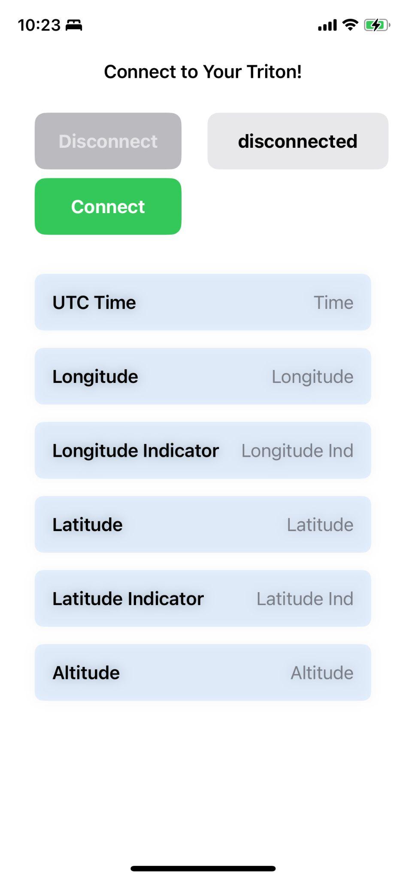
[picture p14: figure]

Figure 4. Representations of the iOS application’s user interface during different connection states

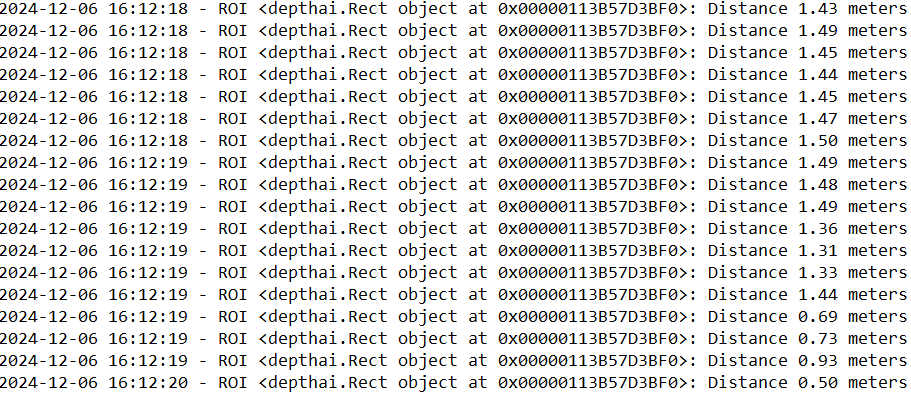
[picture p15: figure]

Figure 5. Text file output of objects detected within a 1.5 meter range and their respective ROI position and time recorded

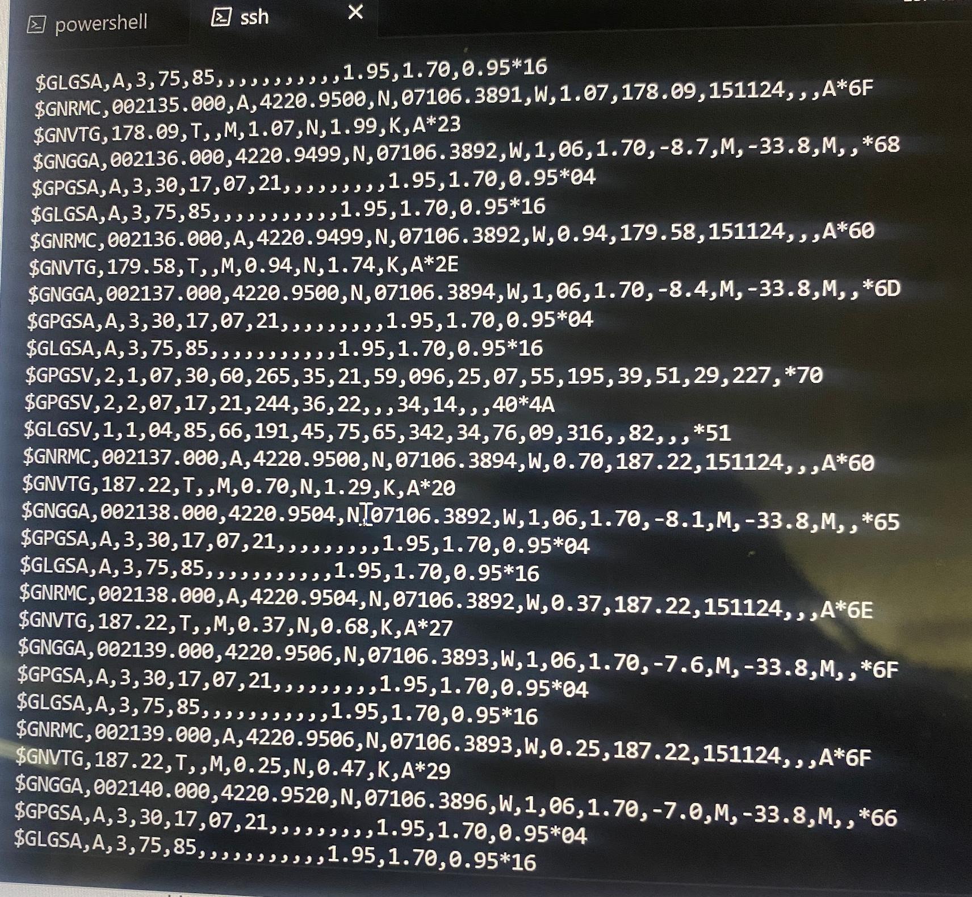
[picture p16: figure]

Figure 6. NMEA Data Outputted by GPS Module

Team 25 Sail-Nav Technologies 11/15/16

Team 25 Sail-Nav Technologies

Project Proposal page

Project Proposal

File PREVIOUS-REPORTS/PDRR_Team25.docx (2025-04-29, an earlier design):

# Boston University

# Electrical & Computer Engineering

# EC463 Capstone Senior Design Project

# Problem Definition and Requirements Review

Sailboat Navigation and Docking Assist

‘The Triton’

Submitted to

Ryan Lagoy

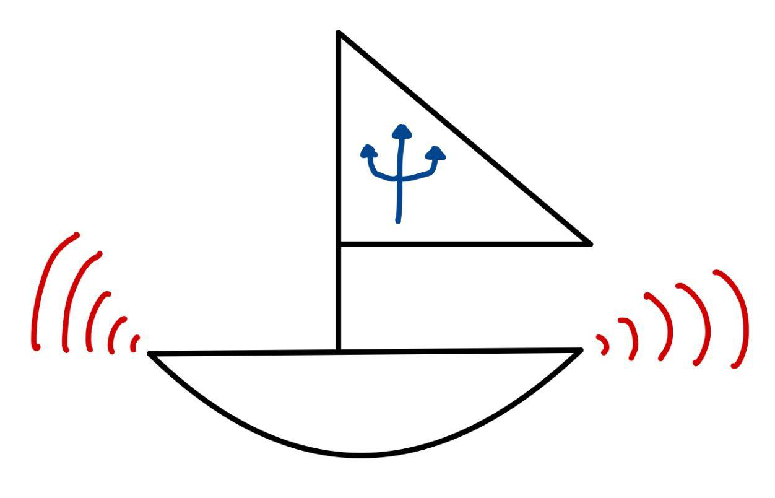
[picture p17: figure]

1 Silber Way

Boston, MA 02215

(617)-877-2569

rlagoy@bu.edu

by

Team 25#

Sail-Nav Technologies

Team Members

Leyandra Burke lburke@bu.edu

Kevin Connell kconn7@bu.edu

Diego D’Angelo-Cosme diegodc@bu.edu

Matthew Guacho mguacho@bu.edu

Kyla Wilson kylaw@bu.edu

Submitted: October 18, 2024

Client Sign-Off _______________________________________

#### 1. Sailboat Navigation and Docking Assist

#### 2. Table of Contents

Project Summary 2

1 Need for this Project 3

2 Problem Statement and Deliverables 4

3 Visualization 5

4 Competing Technologies 7

5 Engineering Requirements 9

6 Appendix A References. 10

# 1. Project Summary

The Sailboat Navigation and Docking Assistant, titled The Triton, is a tool that will be easily installed and removed on any sailboat. Its chief function is to assist sailors when docking or maneuvering through crowded areas, such as a busy pier, by providing external sensors and alerts via a mobile phone application. The Triton consists of a series of sensors that are attached to accessible parts of the boat, relaying information to a central processing unit through a Bluetooth connection. The processor will then upload the data to a connected phone, providing information such as nearby or oncoming objects, speed through water, speed above land, wind speed, GPS, and recommendations for how to proceed in certain scenarios.

# 1 Need for this Project

When sailing alongside other boats in busy and crowded waters, sailors often have to make split second decisions, where any mistake could result in thousands of dollars in damages and potentially death. In 2023 the United States Coast Guard reported that the top three causes for recreational boating accidents were operator inattention, improper lookout, and operator inexperience. Overall in 2023 alone there were 564 deaths and 63 million dollars in damages due to boating related accidents.[5] Sailing often has an incredibly high learning curve for new and experienced sailors alike and leaves little margin for error.

In order to mitigate boating related deaths and accidents, there needs to be

systems to help assist sailors in the event of operator oversight. Sailboats often lack any technology to assist sailors or give feedback to the user regarding navigation, speed, or safety, instead relying solely on the sailors' experience. Additionally, experienced sailors looking to sail different vessels may be unfamiliar with vessel specific equipment and this lack of familiarity can result in accidents, damage to the vessel, and hefty fines.

On a different note, some sailors may have visual or physical disabilities that prevent them noticing potential obstacles in advance. Typically these sailors are forced to rely on expensive equipment or others to assist them. This lack of accessibility for sailboats can reduce a sailor’s personal sense of independence and freedom.

Triton aims to solve some of these issues and help lower the learning curve for sailing by providing sailors with an additional layer of safety and accessibility not often afforded to boats of this kind. The system is designed to be easily integrated into any sailboat, taking only a few minutes to install. Triton aims to assist sailors with docking procedures, sailing protocol, detecting obstacles, accessibility, and recommending course adjustments to the user through a mobile app. Through various sensors, Triton will be able to collect the necessary data to best predict sailing conditions and with the oversight of the sailor, act as a second set of eyes in the event of an operator oversight.

# 2 Problem Statement and Deliverables

The Triton is designed so that both new and experienced sailors can more easily navigate heavy traffic areas and perform optimal maneuvers. It will be easily installed and removed and will be usable on any sailboat independent of size. The assistance will come from the sensors that are installed on the boat at the stern, bow, and sides of the boat. These sensors will include proximity sensors, anemometers, temperature sensors, and GPS. In addition, each mount point will use Bluetooth or radio modules to communicate with the central processor. The data collected by the sensors will be organized and processed to a mobile phone application. The application will provide data, alerts, recommendations for maneuvering, and GPS capabilities. This product consists of three primary deliverables:

- A system of sensors with a central processing unit to be installed
- A fully functional code that gathers, organizes, and sends this data to the application
- A working mobile application for smartphones

The sensor system will need to be easily installed and removed, have a long battery life, and be weatherproof. The ease of installation is essential because it enables new sailors to utilize its assistance on any boat that they are able to use. Additionally, a person may sail for a long period of time and it is important that the system can work beyond the longest expected travel time since the data provided is utilized throughout the sailing process from leaving the pier to eventually re-docking. Finally, the system must be entirely weatherproof due to the nature of the environment it will be used in.

The developed code must collect and compute relevant data for the user with quick upload times. It will operate using a state machine architecture consistently transitioning from collecting data to uploading data. The application will have streamlined information for the user with various alerts and notifications for even when they are not actively using it.

It should be noted that this product will not teach a user how to operate a sailboat. Rather it will streamline the relevant information for sailing and provide assistance for scenarios such as avoiding collisions in order to make the activity of sailing easier, safer, and more accessible.

# 3 Visualization

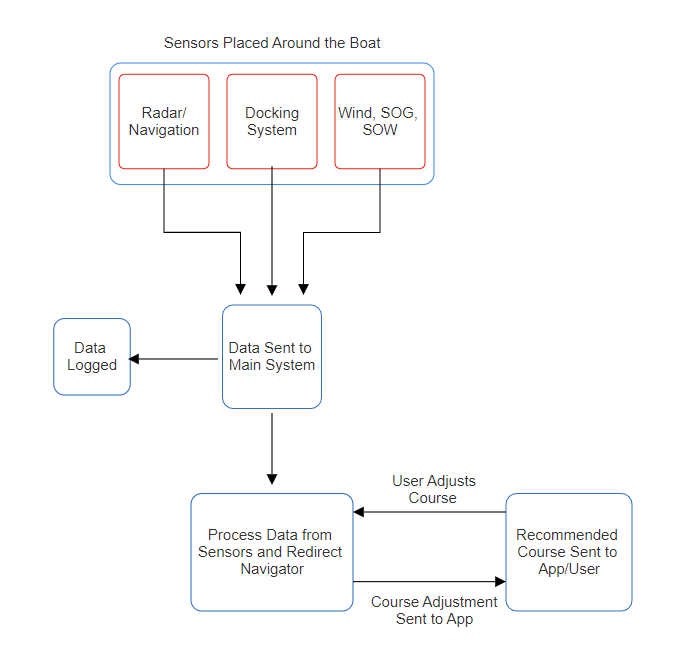
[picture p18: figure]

Figure 1.1 FlowChart of System Components working Synchronously. Where the sensors will be mounted and the main system will log the data and process it to then be sent to the mobile application.

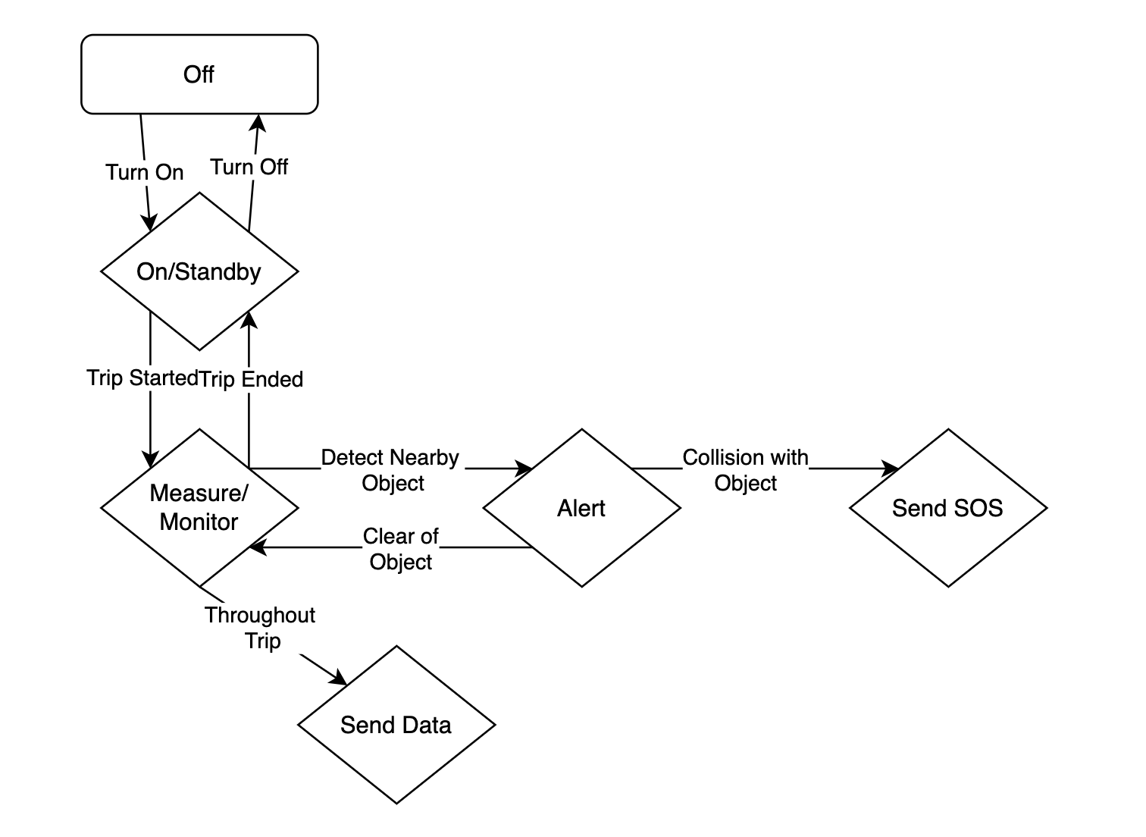
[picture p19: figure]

Figure 1.2 State machine defining the general behavior of the system, from start-up to shut-down.

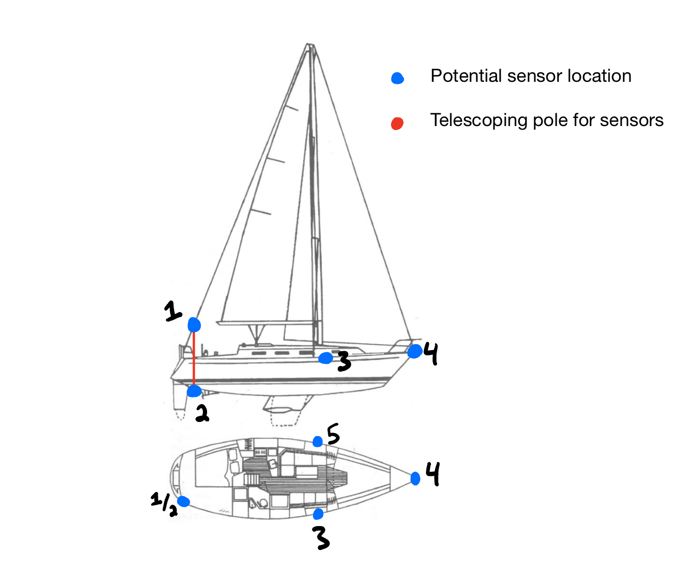
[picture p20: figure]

Figure 1.3 This figure shows an example of how we would mount our sensors and organize our system. The sensors in positions 3, 4, and 5 are all proximity sensors (LiDAR, Radar, Cameras, etc.). The sensor system mounted at position 1/2 will be a collection of sensors, including the central processing unit. This system mounted at position 1/2 will include a telescoping pole that expands bi-directionally, so we can easily put sensors into the water and into the air for accurate measurements. Position 2 will include sensors that need to be submerged in water, and position 1 will include sensors that need to be raised in the air, like an anemometer.

# 4 Competing Technologies

Raymarine

An electronic company that focuses on creating products that assist nautical activities. The most noteworthy product is the Docksense Control, which uses cameras and movement analysis in order to assist the driver in docking their boat. Raymarine’s technology allows Docksense to take over steering and throttle commands when an object enters the vessel’s “virtual bumper” region. The Triton should be able to use similar methods in order to achieve similar objectives. Raymarine’s docksense system is comprised of seven separate parts, their Axion XL Multifunction Display and Joystick, the Docsense control processor, a rear-facing camera, a port-facing camera, a starboard-facing camera, a front-facing camera, and finally an Attitude and Heading Reference System (AHRS) GPS module. Raymarine’s DS Cameras have a waterproof rating of IPx6 [4]. We would like for our entire system to be able to at least match this rating, if not exceed it. Raymarine’s GPS module can track up to 28 channels simultaneously, with a time to first fix being < 45 seconds or < 120 seconds depending on whether coming from a hot start or cold start [4]. The position accuracy from their GPS module is within 15m or within 5m with Satellite Based Augmentation System (SBAS)[4]. We would like for our GPS system to have position accuracy within 20 meters, as we will likely not have the budget to match Docksense’s accuracy. The speed accuracy from their GPS module is within 0.3 kts [4]. We would like for our speed accuracy to be accurate within 1.0 kt, remaining conscious of our budget and time constraints.

Expedition Sailing Software

The Expedition Sailing Software is a program that monitors both weather forecasts and wave data to show the user the best possible route when sailing. This program can be downloaded to your desktop, laptop, or handheld computer, and can connect to multiple peripherals for data acquisition including GPS [1]. Expedition Sailing Software has prominent features including downloadable maps through C-Map, something that is out of the scope for our project at the moment but may be worth exploring in the future [2]. Being clear with such information would be ideal for the Triton.

AutoDesk Sailing Technology

A program that helps sailors monitor wind speed and direction while sailing, so the sailor can plan their route accordingly. AutoDesk is currently working on upgrading the system to handle harsher climates. The sensors for this system include internet of things (IOT), inertial measurement unit (IMU), load cell, and lidar modules. The Triton will act similarly, collecting information through physical sensors [6]. The Triton will also take it one step further and provide limited recommendations to the user in the first release of our mobile application.

Proximity sensing system and method for a marine vessel
The patent outlines a system where proximity sensors would mark incoming objects into an XY graph, and decide boat navigation and propulsion based on the dataset made. While a propulsion system is not needed due to the fact that The Triton is purely for navigation assistance, having an example of how to list nearby objects would be very helpful in both the navigation and the docking assist. Being able to note multiple objects at the same time as well as denote the priority of which object should get the most attention is also something The Triton should be capable of doing for a sailboat.

# 5 Engineering Requirements

The engineering requirements for the Triton are as follows:

2. The system will collect wind speed, speed over ground, and speed through water.
3. The sensors will send updates to the central processor at least every one (1) second while a trip is in progress.
4. The system will have at least three (3) proximity sensors to be mounted on the sailboat.
5. The proximity sensors will detect obstacles between one (1) meter and five (5) meters, and one that can detect obstacles from five (5) to one hundred (100) meters away.
6. The system will have Bluetooth Low Energy and GPS capabilities.
7. The Triton will have a mobile app (iOS) that communicates with the physical sensor system.
8. The mobile app will provide an auditory alert when the sailboat is approaching an object.
9. All physical components of the system, including housing, will weigh less than twenty-five (25) pounds in total.
10. The battery for the system will last at least three (3) days on a full charge.
11. The system will be easily mounted to any sailboat. It will have adjustable clamps to fit onto different parts of the boat.
12. Weatherproof rating of at least IP68.
13. The product cost will not exceed one thousand (1000) dollars.
14. The system will be resistant to harsh weather conditions.
15. GPS accurate within twenty (20) meters.

# 6 Appendix A References.

1. Expedition. (https://www.expeditionmarine.com/)https://www.expeditionmarine.com/. Accessed 17 Oct. 2024.
2. Introduction to Expedition. Directed by Campbell Field, 2020. YouTube, (https://www.youtube.com/watch?v=yhNeXkuJI28)https://www.youtube.com/watch?v=yhNeXkuJI28.
3. Malouf, Travis C., et al. Proximity Sensing Systema and Method for a Marine Vessel. 12046144, (https://patents.justia.com/patent/12046144)https://patents.justia.com/patent/12046144.
4. Raymarine. “DockSense Control Systems | Smart Boating.” Raymarine, (https://www.raymarine.com/en-us/our-products/assisted-docking/docksense-control/docksense-control-systems)https://www.raymarine.com/en-us/our-products/assisted-docking/docksense-control/docksense-control-systems. Accessed 18 Oct. 2024.
5. U.S. Department of Homeland Security and United States Coast Guard. “2023 Recreational Boating Statistics.” Commandant Publication P16754.37, May 2024. Zotero, (https://www.uscgboating.org/library/accident-statistics/Recreational-Boating-Statistics-2023-Ch1.pdf)https://www.uscgboating.org/library/accident-statistics/Recreational-Boating-Statistics-2023-Ch1.pdf.
6. US Sailing | Technology Centers | Autodesk. (https://www.autodesk.com/technology-centers/projects/us-sailing)https://www.autodesk.com/technology-centers/projects/us-sailing. Accessed 17 Oct. 2024.

Team 25 The Triton October 18, 2024

Technical Progress Report page

EC463 2024 PDRR Report

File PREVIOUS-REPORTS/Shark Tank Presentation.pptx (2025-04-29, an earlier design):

## riton

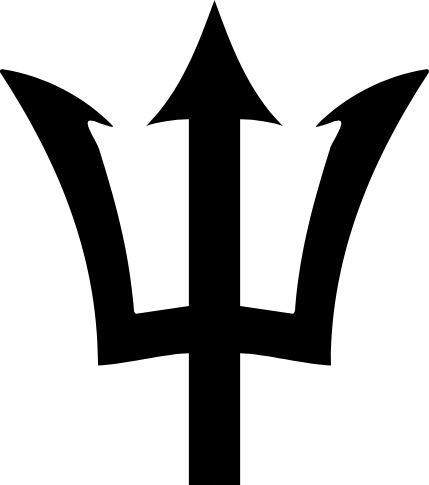
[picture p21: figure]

The

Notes: Triton = messenger of the sea
Maybe smth about navigation

## What is The Triton? Who is it for?

- The Triton is a sailboat navigation and docking assistant
- For experienced and inexperienced sailors alike who want a more reliable sailing experience
- That provides easier, safer trips
- Unlike Competitors
- Our product is integrated and multi-functional, cost-efficient, not specific to any vessel

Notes: Note that sometimes you need more than one value proposition. For example if the beneficiary does not pay you, then you need one value proposition for your beneficiary and one for your paying customer.

Raymarine differences:
Expense
Not integrated, not multi-functional
Intended for larger, motorized vessels

## Why This Matters

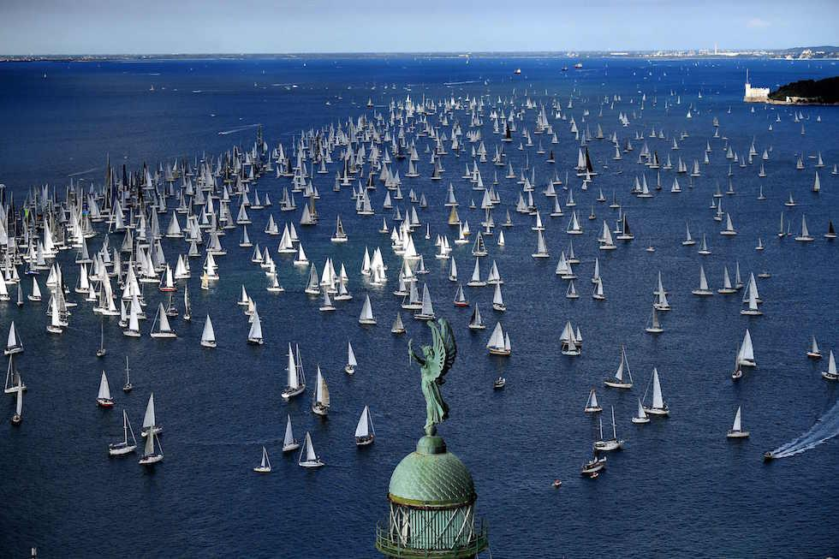
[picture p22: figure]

- Sailing in a crowded harbor or racing alongside other boats in close proximity is challenging,
- Skipper's field of view is blocked by the main and front sails,
- Docking can be difficult and dangerous to the skipper, under many conditions, such as unfavorable wind direction, current, or limited visibility.
- In 2023 the United States Coast Guard reported that the top three causes for recreational boating accidents were operator inattention, improper lookout, and operator inexperience.
- In 2023 alone, there were 564 deaths and 63 million dollars in damages due to boating related accidents.
We want to fix this problem!

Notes:
Lagoy’s story
Sailing in a crowded harbor or racing alongside other boats in close proximity is challenging, especially when sailing singlehandedly. Oftentimes, the skipper's field of view is blocked by the main and front sails, so it is difficult to maintain a visual on obstructions or other boats. Additionally, docking under sail or even under power can present difficulties to the skipper, under many conditions, such as unfavorable wind direction, current, or limited visibility. This project aims to develop a robust and portable sensor system that will aid sailors while underway and docking, and present the status to the user via a BLE connected iOS app. The sensor system can potentially be used in the future to optimize skipper sailing performance.
Research sailboat incidents
Inexperienced sailors causing accidents
Pull from PDRR (Why this is a problem, how we solve it)
When sailing alongside other boats in busy and crowded waters, sailors often have to make split second decisions, where any mistake could result in thousands of dollars in damages and potentially death. In 2023 the United States Coast Guard reported that the top three causes for recreational boating accidents were operator inattention, improper lookout, and operator inexperience. Overall in 2023 alone there were 564 deaths and 63 million dollars in damages due to boating related accidents.[5] Sailing often has an incredibly high learning curve for new and experienced sailors alike and leaves little margin for error. Triton aims to solve some of these issues and help lower the learning curve for sailing by providing sailors with an additional layer of safety and accessibility not often afforded to boats of this kind. The system is designed to be easily integrated into any sailboat, taking only a few minutes to install. Triton aims to assist sailors with docking procedures, sailing protocol, detecting obstacles, accessibility, and recommending course adjustments to the user through a mobile app. Through various sensors, Triton will be able to collect the necessary data to best predict sailing conditions and with the oversight of the sailor, act as a second set of eyes in the event of an operator oversight.

## The Triton A multi-sensor system that assists the nautical navigation and docking for sailboats. Aiming to make sailboating a more beginner friendly activity, as well as help experienced boaters in their travels.

Key Aspects
- Lightweight, easy to install and easy to uninstall
- Adaptable to a wide gamut of vessels
- Recommends how to react in different situations

Technological Solutions
- BLE: For communication between main object
- GPS: For routing and forecasting
- Anemometer: For monitoring wind speed
- Radar/LiDAR: For object detection

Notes: Special sauce
Lightweight
Easy to install, easy to uninstall
Adaptable to different vessels
Recommendations on how do react to approaching vehicles/objects/etc
Technology solution
BLE
GPS
Anemometer

## System (HW and SW)

- Software
  - iOS Application (Swift)
  - Embedded Software (C)
- Hardware
  - Bluetooth Low Energy
  - Temperature sensors
  - Anemometer
  - Radar
  - Telescoping pole

General Metrics:
- The system will collect wind speed, speed over ground, and speed through water.
- The proximity sensors will detect obstacles between one (1) meter and five (5) meters, or five (5) to one hundred (100) meters away.
- All physical components of the system, including housing, will weigh less than twenty-five (25) pounds in total.
- The battery for the system will last at least three (3) days on a full charge.
- Weatherproof rating of at least IP68.
- GPS accurate within twenty (20) meters.

## Hardware Implementation

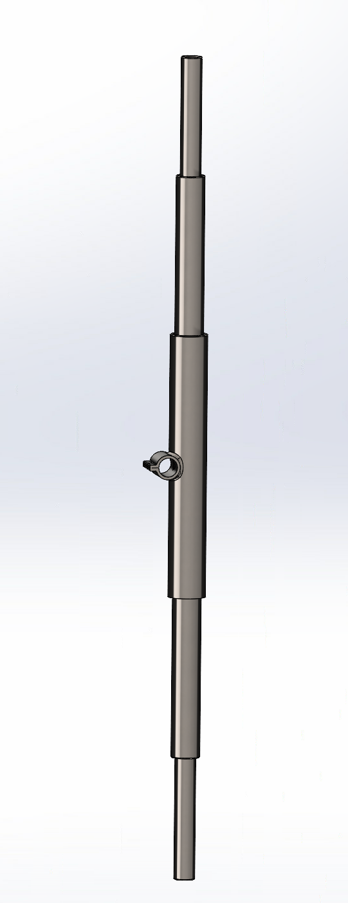
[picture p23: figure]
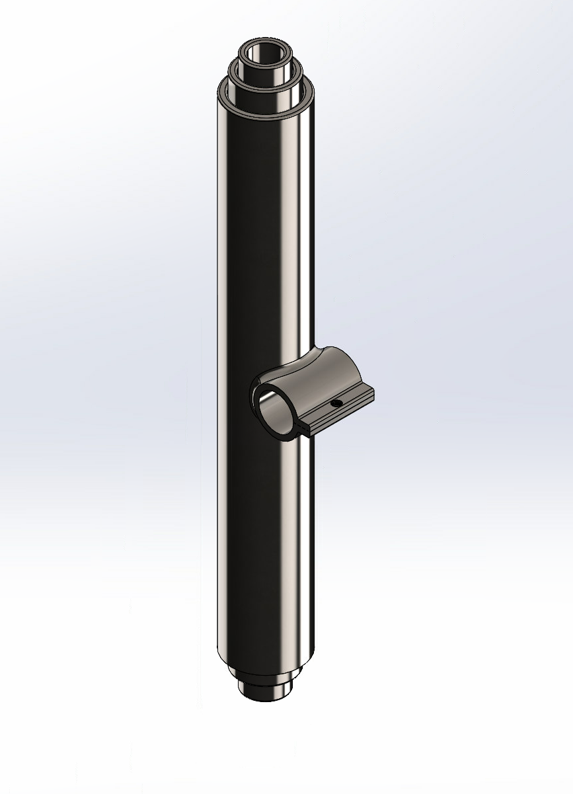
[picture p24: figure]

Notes: Hardware implementation slide

Maybe bring up here the two different CPU placements we’ve discussed

Kevin’s sketches of clamp → CAD model?
Ley monday night
Diego to modify the current design

## System Implementation


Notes: Software implementation slide

Keep two code flow diagrams

## The User Story

How would you be able to use your Triton?


1. Anemometer (Wind Speed)
2. Pitot Tube (STW)
3,4,5. LIDAR (Docking)

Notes: Describe your essential user stories (without them, the product won’t be useful)
Either with your own purchased model or from your local boating club, you can carry your Triton on board. With our clamping system you can mount the 3 object sensors on the front and sides of your boat wherever it is most convenient. You can then mount the telescoping pole near the back of your boat, raising and lowering the two ends, once securely attached to the vessel. And now you’re done! The sensors will work to process the data they receive and use your phone to alert you of any nearby objects and provide recommendations for avoiding collisions

## Reach Goals

- Make the app platform agnostic
- Create a custom PCB for the product
- Offload data to the cloud for users to keep past trips accessible
- Have our system integrated with autonomous sailing group

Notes: Cloud
Keep track of past trips
Keep track of timing
Custom PCB
Android companion app

## Thank you! Any comments or questions?

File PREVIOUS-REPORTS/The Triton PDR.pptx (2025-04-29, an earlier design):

## The Triton Final Design Review

Team 25

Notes: Speaker: Diego

## Introduction

- The Triton is a docking assistant which can also help with nautical navigation
- Helps sailors of all skill levels to safely navigate and dock boats
- Designed to last long trips, and to withstand even the roughest conditions.
- Our product is integrated and multi-functional, cost-efficient, not specific to any vessel

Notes:
Speaker: Matthew
Refine
From Matthew: Made it more concise and more relevant to the current iteration of product.

## Problem Statement

- Sailing in a crowded harbor or racing alongside other boats in close proximity is challenging,
- Skipper's field of view is blocked by the main and front sails,
- Docking can be difficult and dangerous to the skipper, under many conditions, such as unfavorable wind direction, current, or limited visibility.
- In 2023 the United States Coast Guard reported that the top three causes for recreational boating accidents were operator inattention, improper lookout, and operator inexperience.
- Also in 2023, there were 564 deaths and 63 million dollars in damages due to boating related accidents.
- We want to fix this problem!

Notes: Speaker: Diego
Refine
Matthew: Looks good?

## Requirements

- The system will collect wind speed, speed over ground, and speed through water.
- The sensors will send updates to the central processor at least every one (1) second while a trip is in progress.
- The proximity cameras will detect obstacles between one (1) meter and twelve (12) meters away
- All physical components of the system, including housing, will weigh less than twenty-five (25) pounds in total.

- The battery for the system will last at least twelve (12) hours on a full charge.
- The system will be easily mounted to any sailboat. It will have adjustable clamps to fit onto different parts of the boat.
- Weatherproof rating of at least IP68.
- The system will be resistant to harsh weather conditions.
- GPS accurate within twenty (20) meters.

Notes: Speaker: Diego
Refine and update

## System Block Diagram


- External sensors will relay data via Bluetooth to the Pi
- The Pi will then process the relevant data and send warnings and adjustments
- The user will then be able to make adjustments or pull up a live feed to assess the situation and make the appropriate response in turn

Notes: Speaker:Kevin
Needs to be Updated
Change Radar/Nav to GPS/SOG
Take SOG out of Wind, SOG, SOW block
What does docking system mean? Cameras?
Change Data sent to main system to Data sent to Raspberry Pi

## Technology/Design

## Bluetooth Connection Overview: iOS


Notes: Speaker: Kyla

This is our iOS app connection
Used CoreBluetooth to build out the Bluetooth functionality of the App (Framework provided by Apple)
When you open the app, it will automatically start scanning for the Triton
Scans for a custom 16-bit advertising UUID
Once triton is discovered, it will auto-connect to the device
Once connected, the app will discover the services hosted on the Triton’s GATT server
Once the services are discovered, it will go through each service and discover the service’s characteristics
While it is discovering characteristics, it will compare the UUIDs of the characteristics to a predetermined list of characteristics we’re looking for. If the UUID matches one of the characteristics we’re looking for, then we’ll subscribe to notifications on thar characteristic
From here, if the value of the characteristic updates on the Triton, then the iOS app will be notified and will update the UI with the corresponding values as soon as the notification is received

iOS app is the GAP (generic access profile) central and the GATT (generic attribute profile) client

## Bluetooth Connection Overview: Triton/Raspberry Pi


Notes: Speaker: Kyla

This is our Triton connection
Used Bluez (Linux BT Protocol Stack) to build out the bluetooth functionality of the Triton
When the Triton is on and running the python script, it will initialize and register the gatt services and characteristics that the iOS app will discover
The triton then begins advertising the UUID designated for advertising
Once triton is discovered, it will auto-connect to the device and stop advertising
When the app initiates the connection, the Triton will connect to the iOS app
The iOS app will then discover the Triton’s services and characteristics (this can only happen after the two are connected)
The iOS app will then subscribe to notifications on each of the characteristics
If new data is received for the characteristic values, then the value of the characteristic will be updated and the iOS app will be notified

Triton/RPi app is the GAP (generic access profile) peripheral and the GATT (generic attribute profile) server

## iOS App User Interface

- SwiftUI
- Button
- HStack
- VStack


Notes: Speaker: Kyla

App interface once the Triton has connected to the iOS app and is sending GPS data

Created using SwiftUI
Buttons
Tiles

## GPS Module

- Transmits signals and receives data from multiple satellites
- Output of NMEA Data
- Data includes:
  - Date
  - UTC Time
  - Latitude
  - Longitude
  - Altitude
  - Speed Over Ground
  - Course Over Ground


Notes: Speaker: Leyandra

GPS Module: Sends data to the Raspberry Pi through wired connections then Raspberry Pi sends the data from the module to the app. The data sent includes the UTC time, current date, latitude, longitude, altitude, speed over ground, and course over ground.

## Oak-D Camera

- Currently our prototype is able to detect and measure the distance of objects reliably up to 12 meters away and can alert of nearby objects and their relative position to the camera
- We plan to train the camera through machine learning to recognize other ships and common obstacles found while sailing
- Upon recognizing an obstacle the user will be alerted and given the option to view the object and to have the Oak-D camera then physically track the object
- The Oak-D will be mounted onto a motor that will allow it to follow detected objects, as well as scan and increase the FOV of our system


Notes: Speaker: Kevin

OAK-D Camera: The camera is directly connected to the Raspberry Pi, which will send object detection data to the phone as well as a live photo on an interval

## Oak-D Camera (Cont)



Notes: Speaker Kevin

## Housing

- Devices placed on three main points of the boat
  - Front
    - Oak-D camera
    - Anemometer
    - GPS Module
  - Left and Right
    - Stereo Pi Cameras
- Mounting systems with clamps
- Oak-D motorized swivel as an attachment to the Oak-D housing
  - Stepper Motor
  - Servo Motor
  - Brushless Motor


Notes: Speaker: Ley

## Stereo Cameras


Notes: Speaker: Kyla

In order to enable depth perception on either side of the sailboat, we will mount a stereo camera on the widest part of the sailboat on starboard and port. We will use 4 raspberry pi cameras, 2 stereopis, and 2 raspberry pi compute module 4s to enable 2 stereo cameras that will alert the user if there are objects too close to the boat. We’ll use OpenCV to create the depth map

The CM4 supports Bluetooth 5.0, so we will utilize the CM4 to offload information gathered from the stereo cameras to the central module (RPi 3b) which will then be offloaded to the phone. We’ve also considered offloading directly to the iPhone

Essentially should function like the Oak-D, but without object detection
Why offload to central module before the iPhone?

Stereo Cameras: These side cameras will send object detection data to the phone through their respective Pis over bluetooth

## Speed Through Water


- The speed of an object floating on water, affected by currents hitting the object.
- Important for measuring trajectory of nautical navigation, as speed through water and speed on ground shows how the currents are affecting the boat.
- Possible ideas to take information:
  - Pitot tube: Convenient in terms of measurements, but would require wiring to go underwater, raising the risk of failure.
  - Speed Transducer: Not as risky, however requires work to make it function properly, and is notably pricer.


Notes: Speaker: Matt

Include:
Why speed through water is important
Current ideas we have for measuring speed through water
Pros and cons of each?

## Prototype


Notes: Speaker: Kyla (left), Kevin (right)
Insert Video, Photos, Drawings
MattG: Best photo/video would be a demonstration of the OAK-D camera. Maybe also the app but it only shows the GPS so not exactly the flashiest thing.

## Anemometer

- Sensor connected to a Raspberry Pi, sending wind speed and direction information constantly to the application.
- Integral to the project due to the affect wind has on most boats. Gusts can derail a boat from projected route, thus using the information to make proper instructions to react to the wind is required.
- Wind information will be recorded continuously and sent to the main Pi, and, alongside camera sensor information, suggestions will be made as to how to change course, if necessary.


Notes: Speaker: Matt
Anemometer: Sends data to the Raspberry Pi through wired connections, which is then sent to the application. The data sent includes wind speed and direction

Include:
Why anemometer(wind speed/wind direction) is important for our project
Which anemometer module(s) we’re using and why

## Fall Schedule


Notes: Speaker:

## Spring Schedule


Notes: Speaker:
We have a Gantt Chart But it needs to be detailed for next semester - Needs to be discussed

## Thank You!

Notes: Add in pictures from sailing

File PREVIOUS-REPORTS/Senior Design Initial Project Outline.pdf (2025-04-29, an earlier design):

# SAILBOAT NAVIGATION AND DOCKING ASSIST

TECHNICAL AREAS

Sensors, Control Systems PCB Design, Solar Power, Power Management System, Data Visualization, iOS, BLE, 3D Printing/Mechanical Design, Sailing Physics

CUSTOMER’S PROJECT DESCRIPTION

Sailing in a crowded harbor or racing alongside other boats in close proximity is challenging, especially when sailing single handedly. Oftentimes, the skipper's field of view is blocked by the main and front sails, so it is difficult to maintain a visual on obstructions or other boats. Additionally, docking under sail or even under power can present difficulties to the skipper, under many conditions, such as unfavorable wind direction, current, or limited visibility. This project aims to develop a robust and portable sensor system that will aid sailors while underway and docking, and present the status to the user via a BLE connected iOS app. The sensor system can potentially be used in the future to optimize skipper sailing performance.

HIGH-LEVEL REQUIREMENTS

1) The sensor system shall report proximity to nearby objects and boats via an audio and visual alert.
2) The sensor system shall report speed over ground, speed through water, wind speed/direction.
3) The system shall include real-time collision avoidance alerts, and as a bonus, follow right-of-way (COLREGs) rules.
4) The sensor system shall be easily installed/removed from all types of boats without causing damage.
5) The sensor system shall have reliable BLE communication with an iPhone.
6) The system shall contain multiple sensor types:
a. Distance sensors (with Object Detection)
b. GPS, compass, speed-over-ground
c. Wind speed (Anemometer)
7) The system shall be powered via a rechargeable battery, as most small sailboats don’t have accessible power.
8) The status shall be reported in a visually pleasing iOS app.
9) The app shall report to the user recommended changes in course based on sensor readings.
10) The system shall be designed to be dust/waterproof rated to IP68 (by design, but bonus points for test report) and able to withstand harsh marine environments.

DELIVERABLES

The deliverable shall be:

1. A sensor hardware system as defined above, with custom housing
2. An iOS application
3. System software, version-controlled in GitHub
4. Test results from an actual field test on a sailboat

CUSTOMER’S CONTACT INFORMATION

Ryan Lagoy / rlagoy@gmail.com / (617) 877-2569

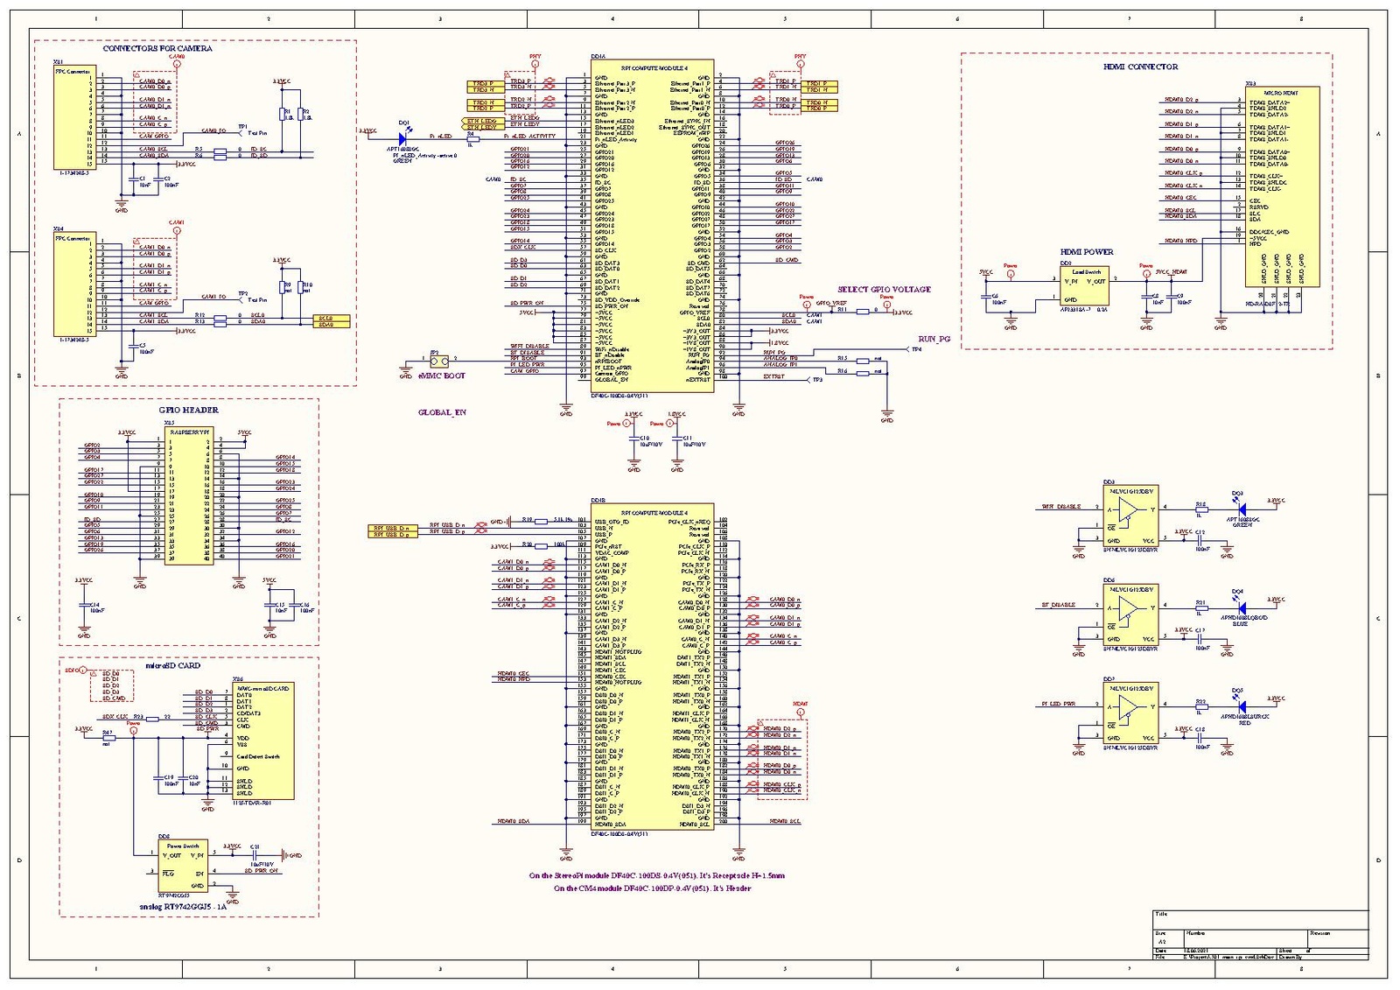
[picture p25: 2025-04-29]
HARDWARE-REPORT/DATASHEETS/StereoPiV2Schematic.jpg

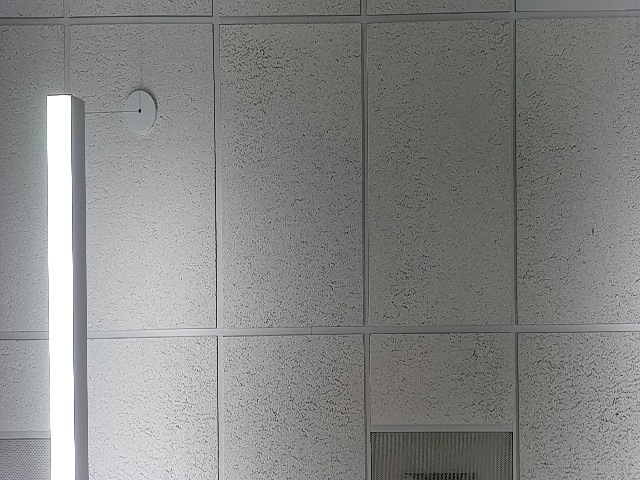
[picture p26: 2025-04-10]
received_image.jpg

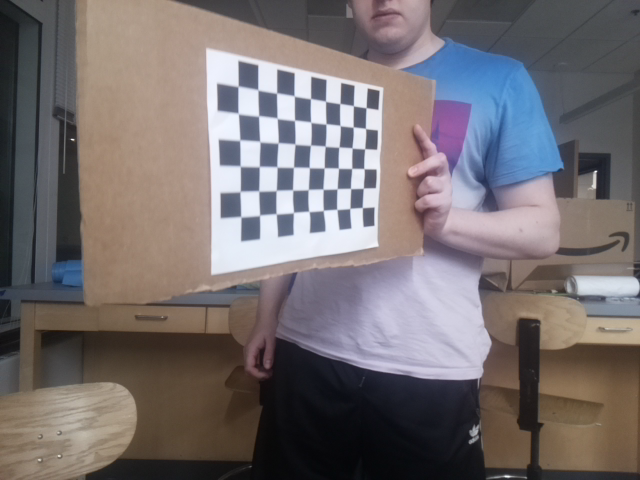
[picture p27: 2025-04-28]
stereopi/pairs/left_10.png

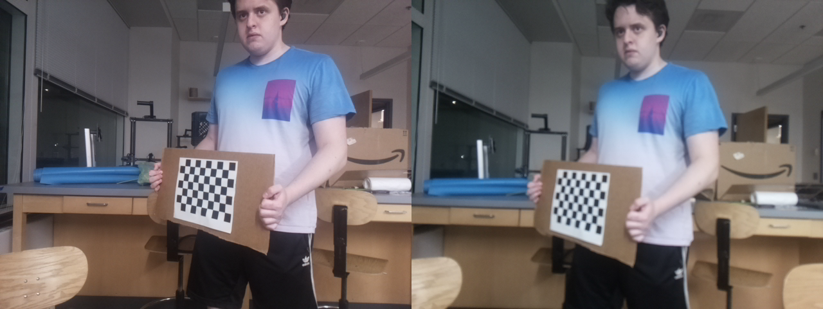
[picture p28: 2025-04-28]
stereopi/scenes/scene_1280x480_24.png

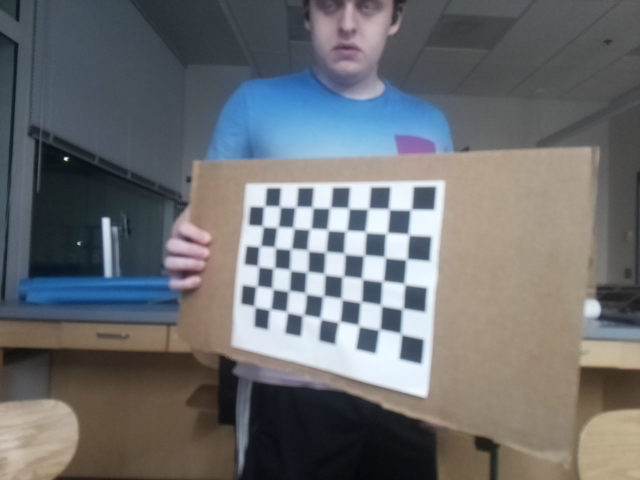
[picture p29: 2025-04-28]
stereopi/pairs/right_17.png

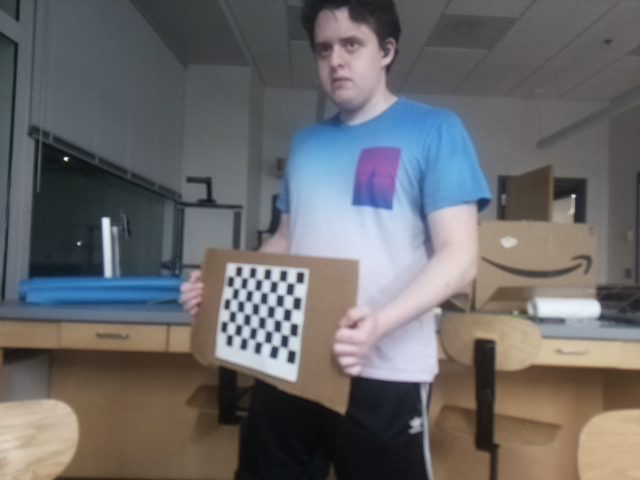
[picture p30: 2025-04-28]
stereopi/pairs/right_24.png

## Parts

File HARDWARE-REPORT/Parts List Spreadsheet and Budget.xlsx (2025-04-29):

Parts | Link | Vendor | Who Payed | Price | Quantity | Receipt in Receipt Folder? | Amazon Total | Total Payed | Total Spent | Budget Left | Budget Left w/o Paying Out of Pocket
NRF52840-DONGLE (Bluetooth) | Bluetooth (https://www.digikey.com/en/products/detail/nordic-semiconductor-asa/NRF52840-DONGLE/9491124?gad_source=1) | DigiKey | Leyandra | 10 | 2 | Yes |  | 28.24 | 762.86 | 237.14 | -12.86
GPS Module | GPS (https://learn.adafruit.com/flora-wearable-gps/program-flora) | Adafruit | Diego | 24.99 | 1 | Yes |  | 35.89
StereoPi Slim V2 | StereoPi v2 Slim - PiShop.us (https://www.pishop.us/product/stereopi-v2-slim/) | PiShop | Kyla | 59.95 | 2 | Yes |  | 138.03
RPi CM4 | RPiCM4 (https://www.digikey.com/en/products/detail/raspberry-pi/SC0679B/13530945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) | DigiKey | Kyla | 35 | 2 | Yes |  | 81.37
OAK-D S2 | Camera (https://shop.luxonis.com/products/oak-d-s2) | Luxonis | Ryan | 250 | 1 | No |  | N/A
Sparkfun Weather Meter Kit | Anemometer (https://www.sparkfun.com/weather-meter-kit.html) | Sparkfun | Kyla | 79.95 | 1 | Yes |  | 91.94
Coupler | Coupler (https://www.digikey.com/en/products/detail/eaton-tripp-lite/P420-001/1533450) | DigiKey | Leyandra | 1.84 | 1 | Yes |  | 28.43
16Bit ADC | ADC (https://www.digikey.com/en/products/detail/adafruit-industries-llc/1085/5761229) | DigiKey | Leyandra | 14.95 | 1
RJ11 Cable | RJ11 Cable (https://www.digikey.com/en/products/detail/amphenol-cables-on-demand/MP-5FRJ11STWS-001/13877699) | DigiKey | Leyandra | 1.46 | 2
RPi CM4 w/ Bluetooth | CM4 w/ Bluetooth (https://www.digikey.com/en/products/detail/raspberry-pi/SC0691/13530946?so=91671580&content=productdetail_US) | Digikey | Kyla | 35 | 2 | Yes |  | 81.37
Batteries |  | Amazon | School | 102.26 | 1 |  | 102.26 |  | 608.42
Anemometer Pole | Pole (https://www.testritealuminum.com/products/tbasb1) | Testrite Aluminum | Leyandra | 27 | 1 | Yes |  | 40.63
Liquid Tight Plastic Adapter | Plastic Adapter (https://www.lowes.com/pd/Tectite-Electrical-1-2-in-Adapter-Connector-Conduit-Fittings/5001381513) | Lowes | Leyandra | 3.98 | 2 | Yes
Assorted Rubber Washers | Rubber Washers (https://www.lowes.com/pd/Danco-Assorted-Washer-ProPack-116-Pack/1000228407) | Lowes | Leyandra | 12.98 | 1
Flex Seal | Flex Seal (https://www.lowes.com/pd/Flex-Seal-Max-17-oz-Clear-Spray/5001781307) | Lowes | Leyandra | 16.98 | 2 |  |  | 58.73
Flange Mount | Flanges (https://www.lowes.com/pd/Blue-Hawk-1-5-16-in-Black-Closet-Rod-Flange-Set/1001378408) | Lowes | Leyandra | 8.98 | 1 | Yes |  | 24.54
Latches | Latches (https://www.walmart.com/ip/Hyper-Tough-New-4-5-in-Swivel-Safety-Hasp-Zinc-Plated/2084697644) | Walmart | Leyandra | 4.84 | 10 | Yes |  | 51.43
PETG FIlament |  |  | Diego, Kyla(team) | 33.98 ($6.80 per person) | 2 (total) | group pay back

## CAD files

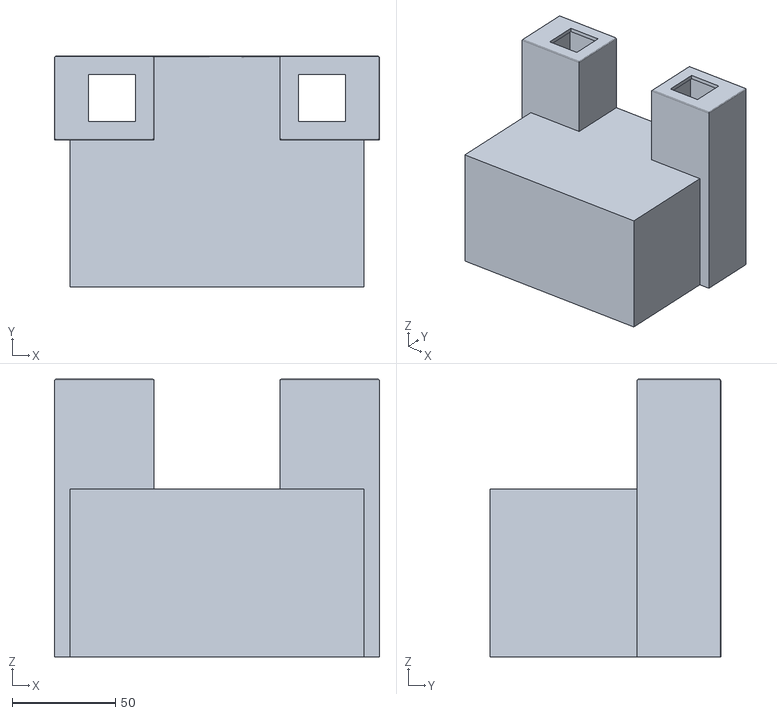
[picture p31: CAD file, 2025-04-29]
HOUSING/StereoPiLid.STL
157.5 x 111.8 x 134.6

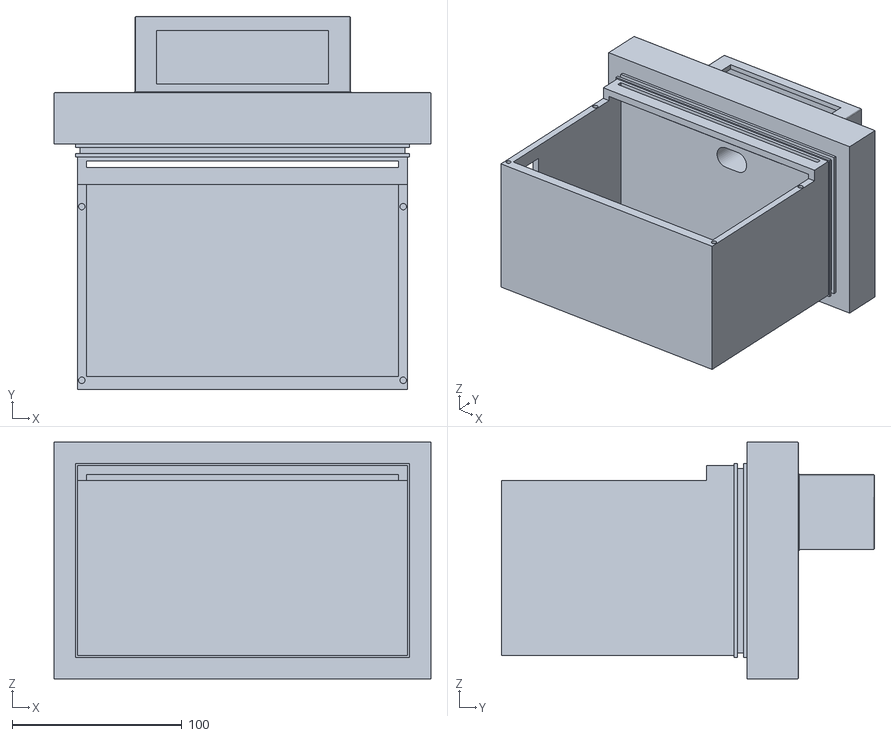
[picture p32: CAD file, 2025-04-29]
HOUSING/SizedLid2.STL
222.2 x 220.0 x 139.7

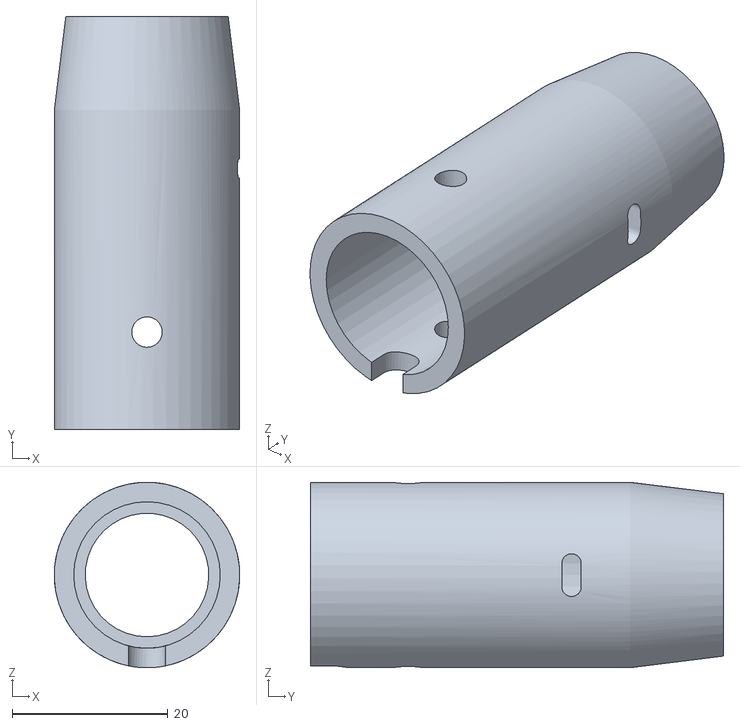
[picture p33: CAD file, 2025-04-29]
HOUSING/AneAttachment1.STL
23.8 x 53.0 x 23.8

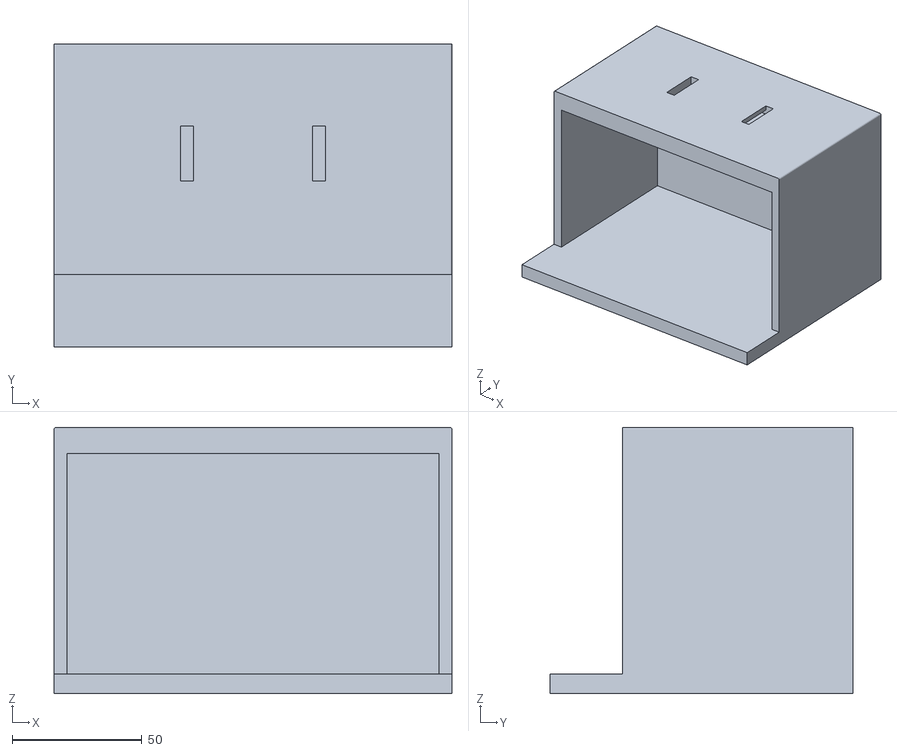
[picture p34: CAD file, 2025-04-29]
HOUSING/StereoPiEnclosure1.STL
153.7 x 116.8 x 102.9

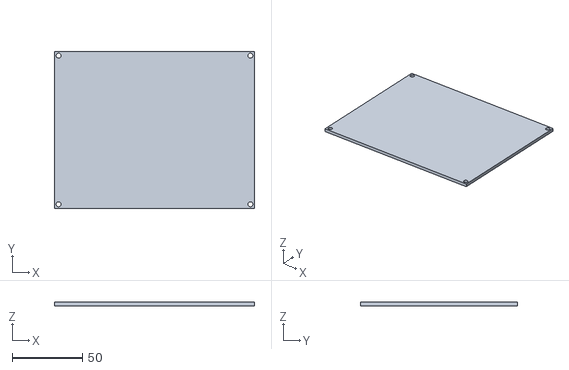
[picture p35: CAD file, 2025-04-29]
HOUSING/StereoPi_LidWall1.STL
142.2 x 111.8 x 2.54

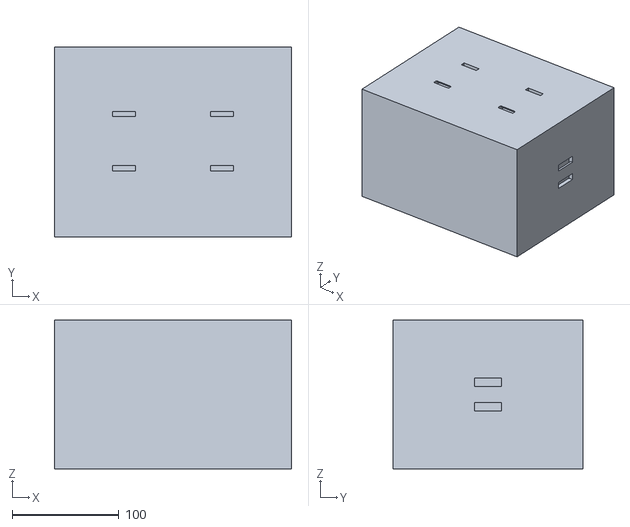
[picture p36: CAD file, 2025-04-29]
HOUSING/SizedEnc1.STL
222.2 x 177.8 x 139.7

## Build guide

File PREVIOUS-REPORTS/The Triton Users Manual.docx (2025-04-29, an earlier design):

# Boston University

# Electrical & Computer Engineering

# EC464 Capstone Senior Design Project

# User's Manual

The Triton

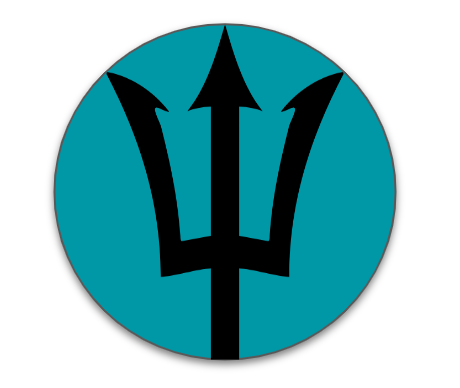
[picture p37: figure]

Submitted to:

Ryan Lagoy

(617) 877-2569

rlagoy@gmail.com

by

Team 25

SailNav

Leyandra Burke lburke@bu.edu

Kyla Wilson kylaw@bu.edu

Kevin Connell kconn7@bu.edu

Diego D’Angelo-Cosme diegodc@bu.edu

Matthew Guacho mguacho@bu.edu

Submitted: April 18, 2025

#### Your Title

#### Table of Contents

Executive Summary 3

1 Introduction 4

2 System Overview and Installation 6

2.1 Overview block diagram 6

2.2 User interface. 7

2.3 Physical description. 9

2.4 Installation, setup, and support 10

3 Operation of the Project 13

3.1 Operating Mode 1: Normal Operation 13

3.2 Operating Mode 2: Abnormal Operations 13

3.3 Safety Issues 14

4 Technical Background 16

4.1 Bluetooth Low Energy (BLE) 16

4.2 Stereo Vision (Oak D and StereoPis) 16

4.3 Swift and SwiftUI 17

4.4 D-Bus 17

4.5 Anemometer and Wind Vane 18

4.6 GPS 18

5 Relevant Engineering Standards 20

6 Cost Breakdown 21

7 Appendices 23

7.1 Appendix A - Specifications 23

7.2 Appendix B – Team Information 23

# Executive Summary

The Triton is a portable, multi-sensor system that provides useful information to the sailor via a mobile iOS application, including object sensing and visualization, GPS data, wind speed and direction, and speed over ground. The Triton is easily installed and removed on any sailboat, with its primary function being to assist sailors when docking or maneuvering through crowded areas, such as a busy port. The Triton consists of three separate sensing modules attached to the bow, starboard, and port areas of the boat. Each of these modules communicates via Bluetooth Low Energy. The data from each of these modules is continuously offloaded to the connected iOS device in real time, giving the operator the most up-to-date information about the current conditions.

# 1 Introduction

The Triton is a portable, multi-sensor system that assists any sailor, whether they are novices or experts, in docking their ship safely, navigate the waters harmlessly, and overall obtain environmental information that is otherwise unavailable to most vessels, such as sailboats.

The main aim is to ensure nautical safety, as maritime or docking accidents can happen to anyone, can cost a fortune, and can leave a sailor severely injured. Many such cases are due to the fact that the sailor was either inexperienced, or they lacked knowledge in the conditions they are in. Regardless of the skill level, problems like these are possible.

The Triton seeks to aid in all of these plights, as with the multi-sensor system, which includes an anemometer and wind vane for wind speed and direction, stereo cameras for distance mapping, an Oak-D camera for precise information, and a GPS to provide geographical and positioning information, the sailor can keep up-to-date about the current sailing conditions, and even get advice if needed for docking and sailing around other vessels. Utilizing the iOS app, information can swiftly be read, and cautionary notifications can keep any sailor on alert. Designed to be easily installable, water resistant with an IP-66 rating, and with a 12 hour battery life, and able to withstand even the most precarious conditions, the Triton aims to aid a sailor in any adventure they embark on.

The Triton’s sensors work simultaneously throughout the whole voyage, and each complex detail comes together to give any sailor a safe voyage. Through the use of Bluetooth Low Energy, all of the collected information is presented on an iPhone application in a neat and readable manner. The data collected through the various sensors is compiled and sent to the user with updates occurring every second, and every tenth of a second for the Oak-D depth information, to ensure reliable and consistent information. In addition to this, the OAK-D will have the ability to send a live view image every thirty seconds.

Overall, this product will be cost effective, reliable, and easily installable so that sailors of any skill level can enjoy the activity safely. The system is lightweight and requires minimal setup or maintenance for day-to-day use. In the following sections you will learn how the system works and should be installed.

# 2 System Overview and Installation

## 2.1 Overview block diagram

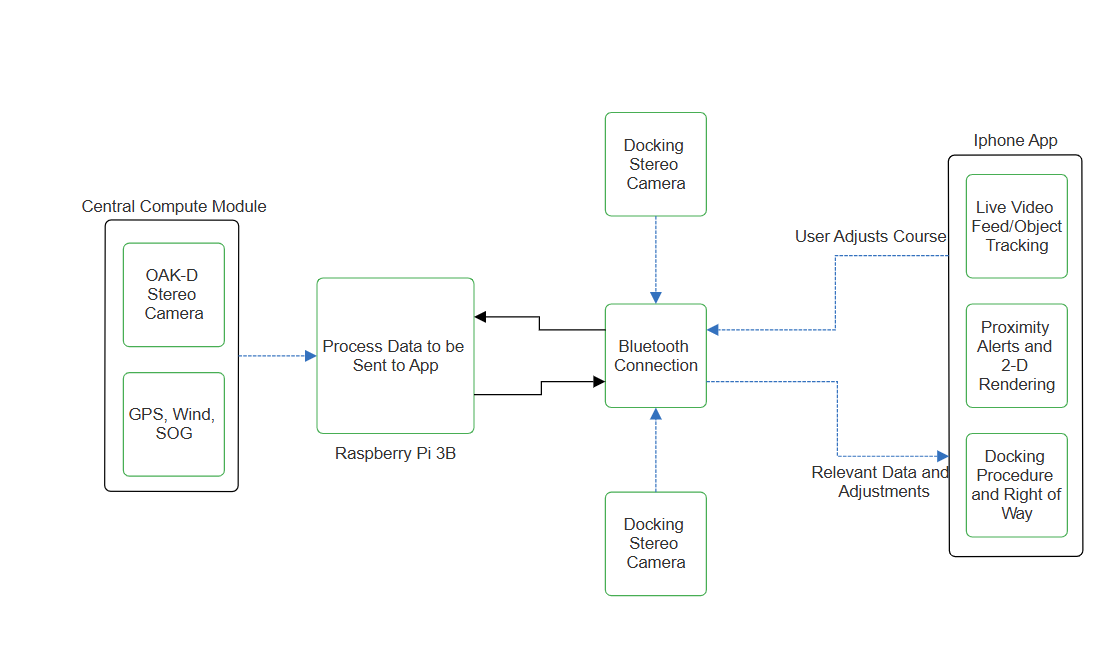
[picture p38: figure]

Figure 2.1 The Triton will collect data from the various external sensors and will have their data compiled on a Raspberry Pi 3B. This data will then be sent to the iOS application on the user’s iPhone via Bluetooth Low Energy.

## 2.2 User interface.

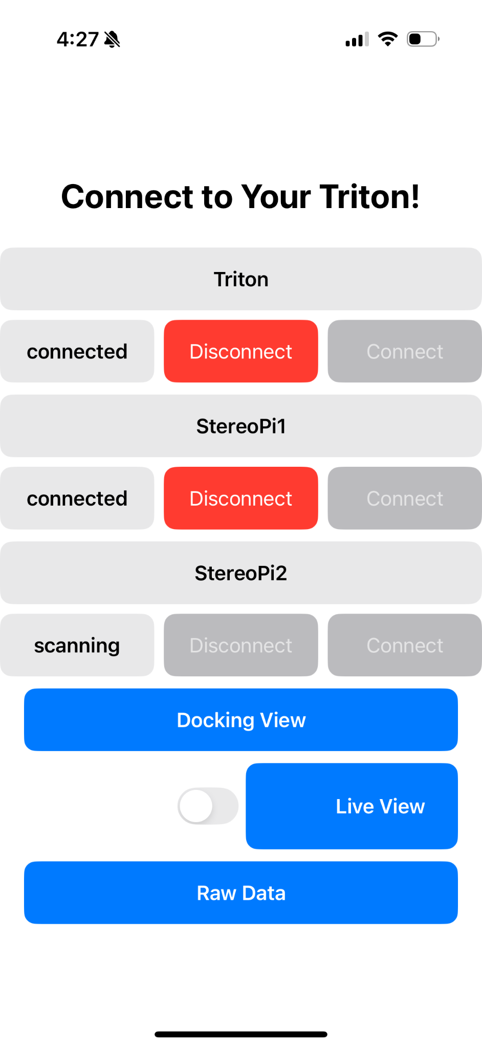
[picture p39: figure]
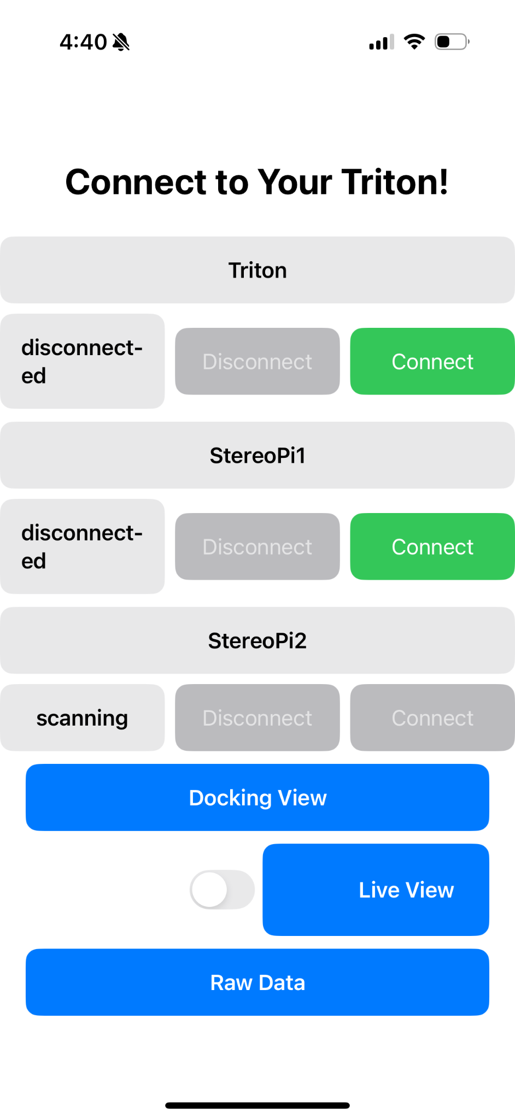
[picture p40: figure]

Figure 2.2 The iOS application will feature different tabs with the data collected and will have dedicated pages for specific features. The Docking View will show the polar map rendering of the distance data collected by the stereo cameras on the front and sides of the ship. The live view will display an image taken by the camera on the front of the ship, and this feature will be toggleable via the switch to the left of the ‘Live View’ button. The Raw Data is a page that will display all of the data collected by the GPS and anemometer sensors in one location. Additionally, the user will be able to control when the application connects with the system, as seen on the top of the screen.

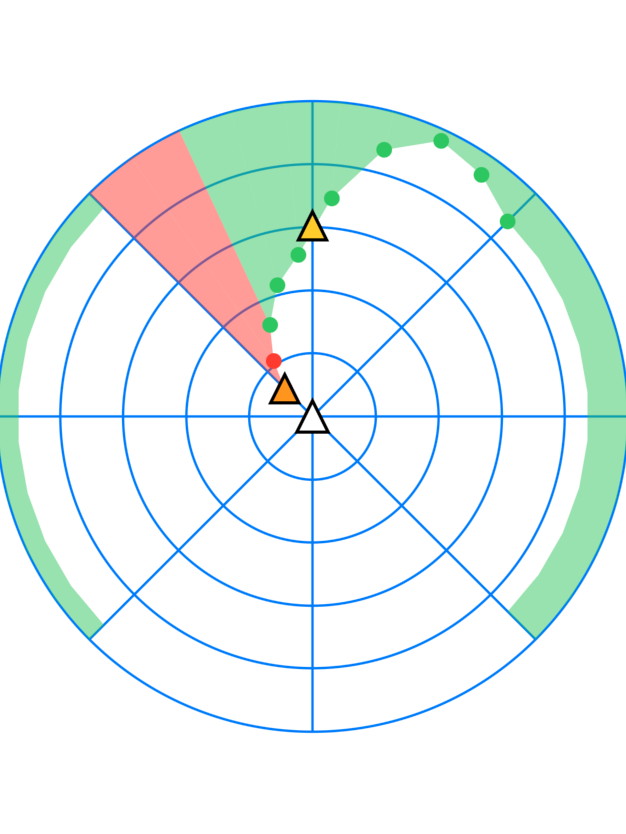
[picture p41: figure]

Figure 2.3 The rendering of the depth data will be translated into a polar map. The OAK-D camera at the front of the ship will have a detailed view of the depths as a result of its more advanced capabilities. The side cameras will be represented through a solid bar registering the depths. If an object is too close the region becomes shaded red as a warning. Finally, when the OAK-D recognizes boats, they appear as colored triangles on the mapping.

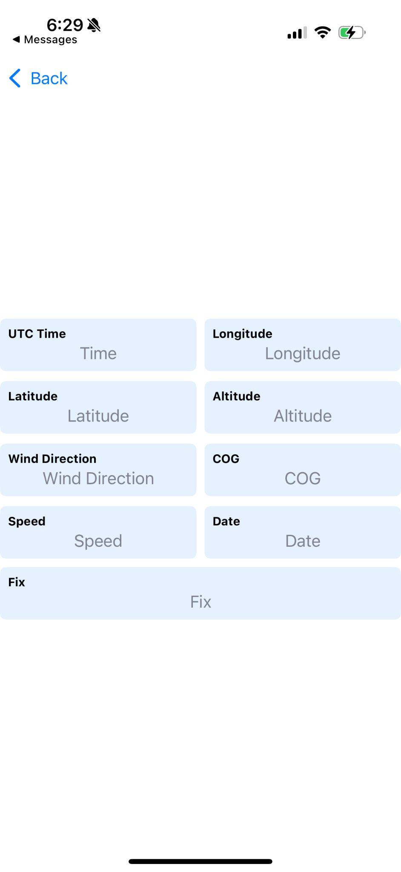
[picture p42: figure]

Figure 2.4 The Raw Data page displays the data collected from the anemometer and GPS modules on its own dedicated page.

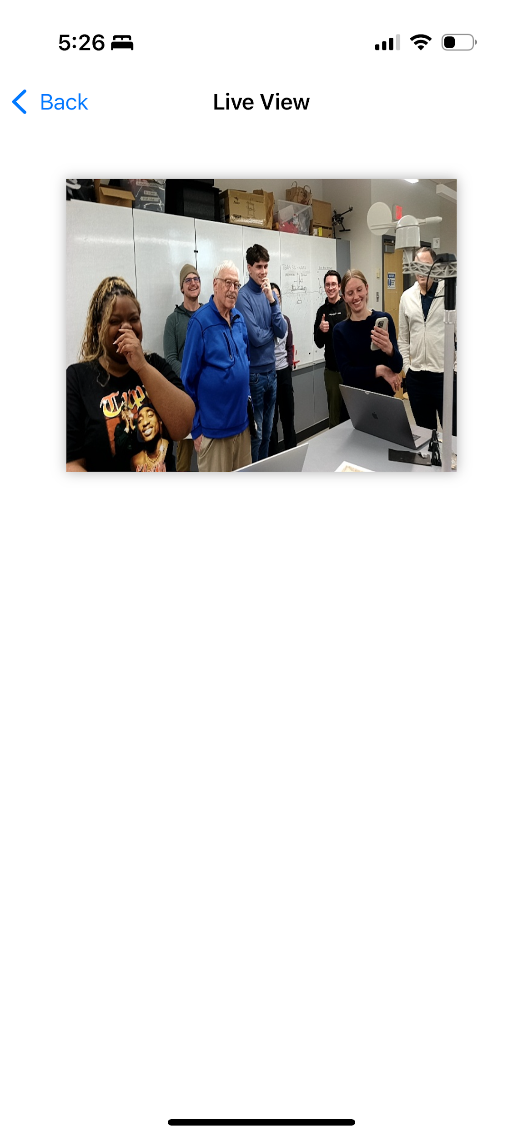
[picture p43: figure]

Figure 2.5 Live view page displays the most recent image taken and uploaded from the OAK-D Camera

## 2.3 Physical description.

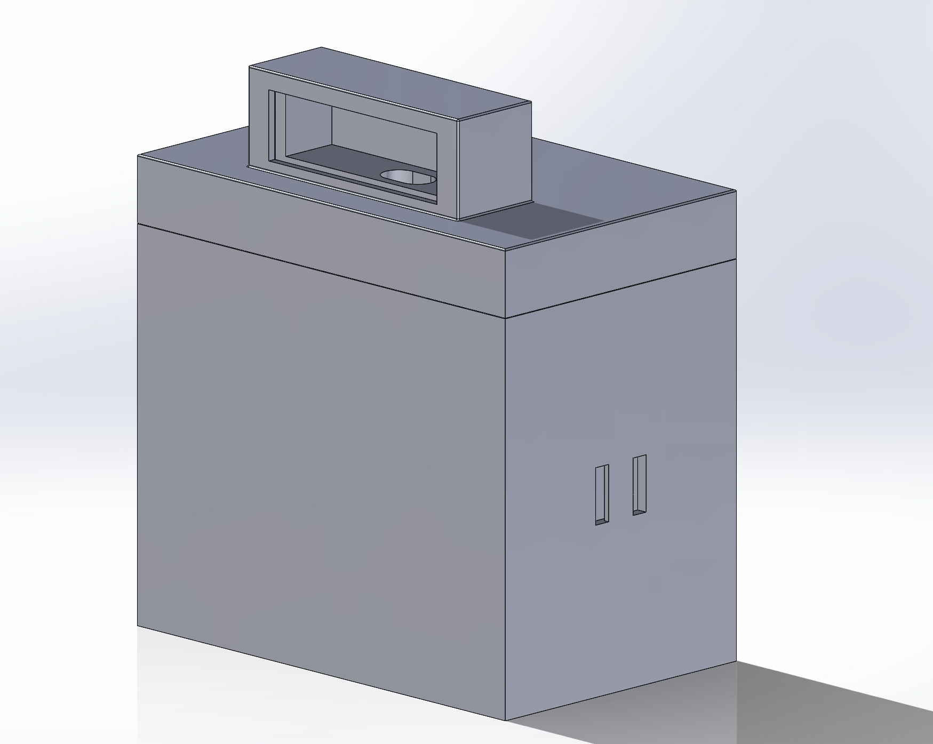
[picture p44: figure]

Figure 2.6 Housing for the OAK-D, Raspberry Pi 3B, Anemometer, and GPS on the front of the vessel

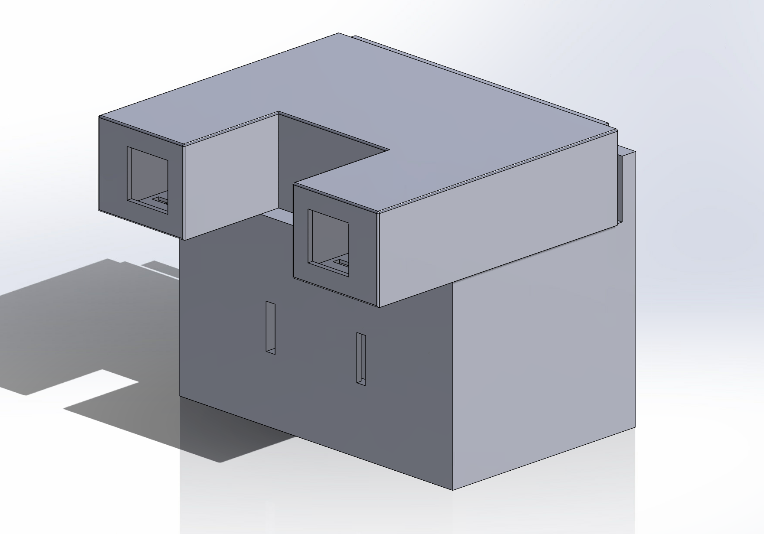
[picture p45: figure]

Figure 2.7 Housing for the Raspberry Pi cameras on the side of the vessel

## 2.4 Installation, setup, and support

Software Installation and Setup:

1. Download XCode onto a Mac
2. Pull from the Senior-Design-Sailboat-Nav-2025 github repository onto the mac
3. Open the Triton .xcodeproj found in the Senior-Design-Sailboat-Nav-2025 in XCode
4. Connect your iOS device to the Mac via a serial cable (USB-C to USB-C or USB-C to lightning), and make sure to trust the Mac when prompted on the iOS device
5. Enable developer mode on your iOS device (https://developer.apple.com/documentation/xcode/enabling-developer-mode-on-a-device)
6. Attempt to Launch the app by pressing the arrow button in the top left corner of the XCode window, it will take some time to copy the cache, and then it will fail
7. When it fails, go to Settings → General → VPN & Device Management and you will see under the developer app the signature of the app, in this case ‘kylawilson5@icloud.com.’ Click the signature and trust the developer
8. Now that you’ve trusted the developer, go back into XCode on your Mac and press the arrow in the upper left corner again, and the app should launch!
9. You may disconnect the cable connecting the iOS device to the Mac, and the app will remain on your device until it is deleted

The Triton is composed of three individual sensor modules that contain stereo cameras and other sensors to relay data to the user. These modules will be placed within mounts that the user will need installed at designated locations on their ship the first time they use this product.

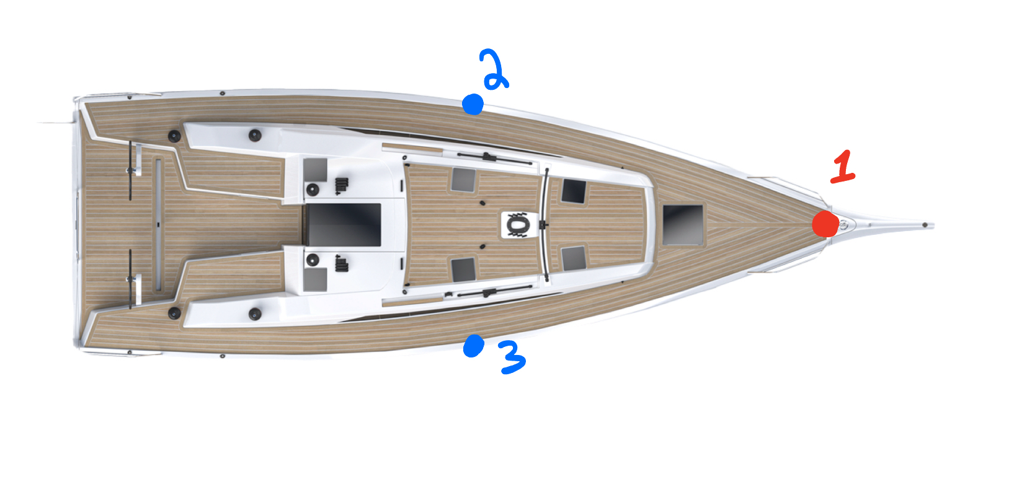
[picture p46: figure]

Figure 2.8 Mounting points for the sensor modules around the ship. The main system is to be installed on the front of the ship (1) with the smaller systems on the side (2 & 3)

The mounts will be installed by attaching and tightening the hose clamps and velcro straps on the front railing and lifelines (side railings), with the main system being mounted on the front railing. Once the mounts are installed, the user will turn on the device and place the sensor modules within the mounts. When the modules are securely placed within their mounts, the user will then lock the latches to ensure the stability and security of the devices. They will then open the iOS application and connect to the devices to begin receiving data. Before use, the user will need to have the Triton application installed and their Bluetooth connection actively enabled so that the signal from the sensor modules may be discovered and connected to. With Bluetooth enabled, the user should see the ability to connect to the various devices as seen in Figure 2.2 and begin receiving the modules’ data. When the user is finished sailing, they can close the application and unlock the sensor modules from the latches and take them off the ship or below deck to be recharged.

Hardware Installation and Setup:

The Triton is composed of three individual sensor modules that contain stereo cameras and other sensors to relay data to the app. These modules are placed within semi-permanent mounts that the user must install at specific locations on their ship prior to first use. (see Figure 2.8)

Initial Installation

1. Using a flathead screwdriver, attach and tighten the hose clamps of the central module to the railing at the bow of the boat, ensuring the camera is facing away from your ship. (Position 1 in Figure 2.8)
2. Wrap the velcro on the sides of the module around a portion of the railing so that it is taut and attach the remaining slack to the velcro attached to the module. For best security, wrap it around the pole at least two times.
3. Using the flathead screwdriver, attach and tighten the hose clamps of the side modules to lifelines(side railings) at or close to the widest part of your boat. (Left module Position 2 and Right module Position 3 in Figure 2.8)
4. Make sure to push down on both side modules to ensure the suction cups on the bottom of the modules are attached.
5. Tighten or loosen the attached velcro so that it is snug against the lifeline pole and attach the remaining slack to itself.

Before Every Use

6. Connect the battery pack to each of the modules to power on the devices.
7. Place each module in their respective mounted frames, making sure the modules are fully sealed to the frames.
8. Place the buckle on the module on the latch attached to the frame and turn the latch so that it is in a horizontal position.
9. For best readings, raise the telescoping pole attached to the anemometer, wind vane, and GPS antenna by twisting the metal adjuster to the left to loosen and raise the pole then twisting the adjuster to the right to tighten and lock the position of the pole in place.
10. Launch the iOS application and connect to the modules

# 3 Operation of the Project

## 3.1 Operating Mode 1: Normal Operation

When in normal operation mode, all software and hardware should already be installed and set up. The user opens the Triton app, and once the services from the devices are discovered, the user will be prompted to connect to each of the individual modules. Each module can be connected or disconnected independently using the corresponding connect and disconnect buttons. Once all modules are connected, the data will begin sending and updating continuously. As seen in Figure 2.2, the user has three options for navigating through the application. If the user selects “Docking View,” the app will display a polar map of the distance data collected by the stereo cameras (see Figure 2.3). If “Raw Data” is selected, the user will be taken to a page that shows the time, longitude, latitude, altitude, wind direction, wind speed, course over ground, speed over ground, date, and whether the GPS has a fix (see Figure 2.4). On the main page of the application, the user can toggle the live view on or off using a switch to the left of the “Live View” button. When toggled on, the app will show updated images from the Oak-D camera mounted on the front of the boat every thirty seconds. Each of these pages includes a back arrow in the top left corner of the screen that will return the user to the main page.

There are some expected behaviors based on specific user actions. If the devices are not powered on, or if the user opens the app while out of range, the app will continue scanning for the devices. In this case, the Docking View page will display a full red ring around the vessel on the polar map. If a device was previously connected but has since disconnected, the Live View page will show the last image received. If there has never been a connection, the page will display “No Image Found.” The Raw Data page will still appear as shown in Figure 2.4, though the displayed values may be blank or outdated until reconnection occurs.

## 3.2 Operating Mode 2: Abnormal Operations

For the rendering, the graph is generated using data received from the OAK-D and StereoPi cameras. Each camera has a maximum range of detecting distances consistently. The rendering anticipates a maximum distance of fifteen meters away and has internal logic to correct if a distance value is greater than fifteen but less than an arbitrary near-infinite distance (when there is nothing present). If an error occurs and a distance of eighteen is read, for example, the point representing that distance may appear above the furthest radial circle on the map, and the shading of the region will be inverted. If this occurs, it will still be an accurate representation of detected distances and will most likely be fixed as the next update of data points is received.

In a similar manner, the StereoPi cameras placed on the sides of the ship are sometimes prone to generating random noise which can potentially cause some inconsistencies in the depth readings. However, this noise is very brief and will not last after the data is updated, like the rendering.

The wind vane may randomly have a spike in voltage due to noise that gives the wrong resistance correspondence and therefore an incorrect angle and direction. However, in software filtering is used to prevent this from happening most of the time.

The OAK-D’s object recognition model may occasionally detect an additional “ghost” object if two or more objects rapidly overlap with one another. The OAK-D will then give the user false readings on the third ghost object. Similarly if an object quickly leaves the frame, the model may also display a ghost object of where the object was last detected. The OAK-’s software is capable of detecting these ghost objects and removing them after only a few frames.

## 3.3 Safety Issues

With this project being heavily reliant on electronic equipment in a marine environment there is an inherent safety concern for the product with water damage. The system is waterproof, however if the integrity of the housing is compromised, then there is a chance of water damage to occur. One mitigation technique would be to cover, dry, or drain out the mounting pieces if they are left out in the rain before installing the module frames.

For user safety, it is vital to use this product as a secondary assistance and not a primary method of docking. A sailor’s view may be impaired or their “boat sense” of how far they are may be weak and that is when this product is most necessary. A sailor should not rely only on the rendering and data collected to approach a dock or navigate through a harbor. Additionally, the system can be used if the sailor needs to go below deck for any reason, but with the short range of the cameras and the slower upload time of the live view images, it is not recommended to be away from the helm for too long. This system may not be able to warn a sailor in time of an oncoming obstacle.

# 4 Technical Background

The Triton uses several technologies to give sailors insights into the conditions around them at their fingertips.

## 4.1 Bluetooth Low Energy (BLE)

The Triton uses Bluetooth Low Energy as the main form of communication between modules placed around different parts of the boat. These modules include:

- Main Module
  - Raspberry Pi, Oak-D, Anemometer, Wind Vane, GPS
- Peripheral Module (x2)
  - Raspberry Pi CM4, StereoPi v2, Raspberry Pi Camera (x2)
- iOS Device

The Raspberry Pi, the Raspberry Pi CM4, and the iOS devices all have RF transponders, which allow the devices to send and receive data wirelessly, enabling Bluetooth functionality. Bluetooth Low Energy is specifically designed for low-power systems. Bluetooth Low Energy (BLE) is a wireless communication protocol designed for low-power, short-range data exchange between devices. It operates in the 2.4 GHz ISM band and uses a simplified protocol stack compared to classic Bluetooth to reduce energy consumption. BLE communication is based on a client-server model, where a central device (iOS device) connects to a peripheral device (main housing, peripheral housing) to read or write data. Data is organized into attributes and grouped into services, which are accessed using the Generic Attribute Profile (GATT). BLE uses advertising packets to allow peripherals to broadcast their presence, enabling quick and efficient connection setup.

## 4.2 Stereo Vision (Oak D and StereoPis)

The Triton has three independent stereo cameras providing the user 270 degrees of coverage. Stereo cameras consist of two cameras placed a set distance apart which each capture slightly different images. The pixel value differences between these two images can be used to create a disparity map. The inverse of these disparities can then be used to calculate the distance of an object from the camera, allowing for fast and accurate distance readings. These distance readings are used to keep track of how close an object is to the boat, and allows for accurate advice to be sent to the user regarding what would be the wisest action given their current environment.

Although the Oak-D’s cameras come already pre-calibrated, the StereoPis were designed to work with any type of boat, as well as maximize its measuring distance such that warnings can be made for more situations.

The OAK-D’s object detection system consists of two parts: a general depth map and a YOLOv4 object recognition model. The general depth system uses the depth map created by the camera and then overlays a 10x10 grid of regions of interest or ROI’s. The depth is then recorded and the ROI cell with the closest recorded distance in each column is then sent and displayed to the app. The object recognition system can detect and recognize most maritime vessels and draws an ROI around each vessel. The ROI relays the vessel's relative position to the boat and its distance when within 15 meters. The model is capable of identifying vessels within 30 - 50 meters depending on their size.

## 4.3 Swift and SwiftUI

Swift is a powerful programming language developed by Apple for building applications across iOS, macOS, etc. SwiftUI is a framework that allows developers to design user interfaces using declarative syntax. With SwiftUI, the UI is automatically updated when the underlying data changes using Observed Objects, simplifying state management. The team used SwiftUI to create the entirety of the UI, including the application, polar rendering, raw data page, and live view. Similarly, the underlying Bluetooth management and data transfer are managed in Swift using Apple’s CoreBluetooth framework. Swift and SwiftUI communicate seamlessly with each other.

## 4.4 D-Bus

D-Bus is an inter-process communication (IPC) system in Linux that allows applications and system components to communicate with one another. In the context of the BlueZ stack, D-Bus serves as the primary interface for interacting with low-level Bluetooth devices and services in Linux. BlueZ exposes the device’s Bluetooth functionalities, such as device discovery, pairing, and GATT operations through a set of well-defined D-Bus APIs. The Bluetooth applications running on the Raspberry Pi in the main housing and the Raspberry Pi CM4s in the peripheral housing use these APIs to monitor Bluetooth events and control Bluetooth behavior without directly interacting with low-level kernel modules.

D-Bus was also used to enable cross-application/cross-script IPC, where unique D-Bus services were created. These services register custom objects and interfaces on D-Bus, which the Bluetooth scripts invoke using method calls. We implemented these custom D-Bus services in Python and C++ and registered it with the D-Bus daemon. This IPC mechanism provides a flexible and standardized way to communicate between the scripts that collect useful data like GPS data, anemometer data, and Oak-D data and the script that makes this data available to the iOS application, the Bluetooth script.

## 4.5 Anemometer and Wind Vane

The anemometer measures wind speed using a cup-type sensor that closes a magnetic reed switch each time a magnet rotates past it. A wind speed of 2.4 km/h causes the switch to close once per second, allowing wind speed to be calculated by counting pulses over time using a microcontroller or digital counter. Wind direction is determined by a wind vane containing eight switches, each connected to a distinct resistor. Depending on the vane’s orientation, one or two switches are closed, producing up to 16 unique resistance values corresponding to specific directions in 22.5° increments. These resistors form a voltage divider, and the resulting analog voltage is read by a 16-bit analog to digital converter where the corresponding resistance is determined to get the wind direction.

## 4.6 GPS

The Global Positioning System (GPS) is a satellite-based navigation system that provides location, speed over ground, and time information to receivers anywhere on Earth. It operates by using a network of satellites that continuously transmit signals containing their position and time. A GPS receiver calculates its position by triangulating signals from at least four satellites, three that determine the GPS’s precise location, and one that adjusts for the error in the GPS’s clock. This allows the receiver to compute its three-dimensional position (latitude, longitude, and altitude) and synchronize its clock to Coordinated Universal Time (UTC).

The GPS receiver outputs data in the form of NMEA (National Marine Electronics Association) sentences, which are standardized ASCII text strings. These sentences allow us to get important navigation information such as position (GGA), time and date (RMC). Each NMEA sentence begins with a “$” and includes a checksum for validation, which makes it easy for us to parse and extract data from.

# 5 Relevant Engineering Standards

The Triton is a maritime device, thus it is made to be waterproof with a rating of IP-66 utilizing PETG filament and flex seal. It utilizes expert advice in order to guide the user on how to properly dock their boat as well as warn if the sailor may be docking incorrectly. Additionally, the device will provide advice on right of way rules for open sailing that fall under the Convention on the International Regulations for Preventing Collisions at Sea (COLREGs) standards. The app was created utilizing SwiftUI, and thus follows the protocol for Apple applications, while the sensors were programmed in Python for ease of interaction when it comes to Bluetooth. The images that come from the Oak-D are screenshots that are taken after twenty-five seconds, to maximize efficiency while giving the sailor an up to date view of the front. Data from each sensor is transferred to the central system as well as the app via Bluetooth. The app then processes and presents the user with the relevant data and warnings. The type of Bluetooth used is Bluetooth Low Energy and Bluetooth 5 for high efficiency data transfer.

The total system is powered by three lithium battery packs and a simple circuit board. The battery packs were tested for their safety under the IEC 62133 standards, which ensures the safety and performance of portable batteries. In addition to this, the use of GPS maintains best practices based on the GPS Standard Positioning Service (SPS) Performance Standard.

# 6 Cost Breakdown

Project Costs for Production of Beta Version (Next Unit after Prototype)
Item | Quantity | Description | Unit Cost | Extended Cost
1 | 1 | GPS module | 24.99 | 24.99
2 | 2 | StereoPi Slim V2 | 59.95 | 119.90
3 | 2 | RPiCM4 with Bluetooth | 35 | 70
4 | 1 | OAK-D S2 | 250 | 250
5 | 1 | Anemometer and Wind Vane | 79.95 | 79.95
6 | 1 | 60,000 mAH Battery Pack | 39.88 | 39.88
7 | 2 | 30,000 mAH Battery Pack | 31.19 | 62.38
8 | 1 | Coupler | 1.84 | 1.84
9 | 1 | 16 Bit ADC | 14.95 | 14.95
10 | 1 | RJ11 connector cable | 1.46 | 1.46
11 | 1 | Telescoping Pole for Anemometer | 27.00 | 27.00
12 | 2 | Liquid Tight Plastic Adapter | 3.98 | 7.96
13 | 1 | Rubber Washers | 12.98 | 12.98
14 | 2 | Flex Seal | 16.98 | 33.96
15 | 1 | Flange Mount | 8.98 | 8.98
16 | 10 | Latches | 4.84 | 48.40
17 | 2 | PETG Filament | 16.99 | 33.98
Beta Version-Total Cost | | | | 838.61

The budget can be separated into two key portions: the hardware for the modules and the materials necessary for the assembly of the product. The devices make up a large portion of the budget despite there being more total materials for the assembly of the product. Despite this, though, the price of the beta version of the product is still very reasonable, considering most maritime sensor systems tend to be upwards of $1000 with less functionality and incompatible with certain boat types. Our product will work on boats with railings and provide multiple different data types.

# 7 Appendices

## 7.1 Appendix A - Specifications

Requirement | Value, Range, Unit
Dimensions | Main: 8.75” x 5.5” x 9.96” * Peripheral: 5.75” x 6.2” x 5.1”
Weight | < 25lbs
Weatherproofing | IP66
Update Speed | Every second**
Depth Detection Range | 15 meters
Object Detection Range | 30-50 meters
Battery Life | 12 hours
GPS Accuracy | within 5 meters

*: without anemometer

**: for anemometer and GPS Data

## 7.2 Appendix B – Team Information

Team 25, SailNav, was composed of four computer engineers and one dual major computer and mechanical engineer. The idea of a product that could be mounted onto a sailboat to assist with docking was proposed by Ryan Lagoy, who served as the team’s client, and the Triton was the team’s interpretation, design, and implementation of this idea.

Kyla Wilson is a computer engineer who will be moving to Chicago and working as a Firmware Engineer for Bayer, Crop Science upon graduation. Kyla was responsible for all of the integration and IPC for the Triton, enabling and managing Bluetooth Low Energy for each of the modules, and creating and managing the iOS application’s UI.

Leyandra Burke is a graduating computer and mechanical engineer with an interest in product development and manufacturing. Leyandra was responsible for the implementation of the GPS and anemometer and wind vane sensor modules. She was also responsible for the housing design, production, machining, and waterproofing.

Diego D’Angelo-Cosme is a graduating computer engineer who is aspiring to enter the tech industry after graduating. He has a passion for rapid prototyping, code design and review, and networking and cybersecurity topics. For the Triton, Diego was chiefly responsible for developing the rendering of cameras’ data and creating the power budget for the system.

Kevin Connell is a computer engineer graduating with a strong interest in computer hardware and architecture. Hoping to continue designing and optimizing on the hardware level. Kevin was responsible for the Triton’s primary stereo camera the OAK-D and developing the system of detecting vessels and recording their distance and position.

Matthew Guacho is a computer engineer who has an expertise and interest in software engineering. With a particular expertise in algorithms, he strives in making projects efficient. Matthew was responsible for coding and calibrating the side StereoPi cameras, as well as maximizing the distance the cameras can read.

Team 25 SailNav April 18, 2025

User Manual page

User's Manual page

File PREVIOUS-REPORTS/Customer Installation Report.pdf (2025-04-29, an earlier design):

# Boston University Electrical & Computer Engineering

# Customer Installation Report


# Team 25

### 1.0 Customer Installation Details:

For the preliminary installation, all team members were present on Friday April 25, where they met with Professor Lagoy and an associate of his named Noah Bagazinksi, a graduate student at MIT. Noah provided a sailboat for the team to do a preliminary installation and testing with a more formal and final installation planned to happen on April 29 with Kay VanValkenburgh on a larger vessel. The ship that was used with Noah was much smaller with no railings or lifelines for our system to be properly mounted.

### 2.0 Requirements:

Requirement | Type | Modification (if applicable) | Completion (if applicable) (Y/N)
The sensor system shall report proximity to nearby objects and boats via an audio and visual alert. | Modified | Only visual alerts | Y
The sensor system shall report speed over ground, speed through water, wind speed/direction. | Original | N/A | Y
The system shall include real-time collision avoidance alerts, and as a bonus, follow right-of-way (COLREGs) rules. | Original | N/A | Y
The sensor system shall be easily installed/removed from all types of boats without causing damage. | Original | N/A | Y
The sensor system shall have reliable BLE communication with an iPhone. | Original | N/A | Y
The system shall contain multiple sensor types: a. Distance sensors (with Object Detection) | Original | N/A | Y

b. GPS, compass, speed-over-ground c. Wind speed (Anemometer)
The system shall be powered via a rechargeable battery, as most small sailboats don’t have accessible power. | Original | N/A | Y
The status shall be reported in a visually pleasing iOS app. | Original | N/A | Y
The app shall report to the user recommended changes in course based on sensor readings. | Skipped/Eliminated | N/A | N
The system shall be designed to be dust/waterproof rated to IP68 and able to withstand harsh marine environments. | Modified | IP66 rating | Y

### 3.0 Assessment:

In our testing and installation the team showcased a live demo of the Triton being used on a sailboat in real testing conditions. There was a last-minute complication with the StereoPi side cameras that did not allow them to be deployed on the ship, however for the second installation period with Kay on April 29th they will be fixed and properly deployed on the sailboat.

Overall, the product worked as intended. The housing was secure and sturdy, with a method to quickly insert the sensors in a manner that does not alter or damage the ship and ensure the security of the devices. Additionally, the housing was printed using a special filament with waterproof properties and coated in a sealant. The iOS application was able to seamlessly connect to the device and receive the data from the sensors and OAK-D camera in a clean and readable manner. The UI had various pages for different information based on what the user was most interested in seeing at the time. In addition to this, the rendering was able to accurately depict the distances detected by the OAK-D camera as well as the objects the camera could recognize (boats and other people). Finally, the OAK-D was able to successfully record the distances of different objects and produce accurate depth readings, although sometimes the waterline would be detected. This was fixed when a different script was run that had been pushed to the project GitHub after the most recent pull before the testing ensued.

The second session of testing and installation aims to be a final test for the product. The goals for this followup session will be to fully ensure the functionality of the mounts for the housing on the front and side of the ship. Additionally, the OAK-D’s waterline recognition and avoidance will be fully implemented and completed, as well as the implementation for the StereoPi cameras on the side. The product has exhibited the necessary qualities and features as desired by the client, and this final session aims to showcase the full extent of the Triton.

### 4.0 Customer Letter:

After the testing had concluded, Professor Lagoy emailed the team with his thoughts on the testing and hopes for our second round of final implementation:

“I wanted to give you some initial feedback for your automatic docking assist and sailboat detection system.

Specifically, the app layout and docking screen is exactly as I imagined. Additionally, the Oak D stereo cam and RGB cam inputs were effectively combined to provide both distance alerts and sailboat detection. The wind speed sensors worked perfectly on our demo. I'm looking forward to seeing the side stereo camera sensors!

Overall, I'm very impressed with how you integrated all the subsystems into a thoughtfully designed enclosure with focus on safety, ease of use and aesthetic. Great work team!”

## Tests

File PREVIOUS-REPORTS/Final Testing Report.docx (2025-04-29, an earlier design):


Senior Design

ENG EC 464

Boston University Electrical & Computer Engineering

The Triton Final Testing Report


Team 25

Required Materials

Hardware:

- Raspberry Pi 3B
- USB-A to Micro cable
- 3x 5V Rechargeable Battery
- OAK-D S2
- iPhone
- Lightning to USB-C cable
- Mac
- StereoPi Slim V2
- PETG Filament
- Flex Seal
- Anemometer
- Adafruit Flora GPS Module

Software:

- Bluetooth Python Script
  - Connect the Triton (Raspberry Pi) to the iOS application
  - Read from:
    - The OAK-D and send a photo, distance data, and object detection data
    - GPS data such as speed over ground, longitude and latitude, and course over ground
    - Distance values from the StereoPi cameras
    - Wind speed and direction from the anemometer
- Camera Distance Recognition and Object Tracking Python Script
  - Determine if an object is present and present its distance and angle
  - Visualizes if an object is within a certain distance relative to the camera
  - Track a given target to give more detailed distance information
  - Provide a detailed heat mapping to find the closest object within a set distance
- iOS Application
  - Showcase the data collected from the various modules connected via Bluetooth
  - Present polar mapping display of detected objects and depths near the boat
  - Demonstrate an improved UI with partitioned information on different pages
- StereoPi Software
  - Use depth mapping to determine the distance of an object from the cameras
  - Convert the camera-based distance values to meters for an accurate representation
- Anemometer Software
  - Collect wind speed and wind direction data and send it over Bluetooth via DBus
- GPS Software
  - Record, parse, and pass to Bluetooth via DBus

Setup

This demonstration will show the complete architecture of our product’s design with each module individually completed and integrated into the iOS application through its Bluetooth connection. These modules include the OAK-D camera, StereoPi cameras, anemometer, GPS, and iPhone application.

Pre-Testing Setup:

Raspberry Pi

1. Flash the Raspberry Pi 3b’s SD card with the Raspberry Pi OS 64-bit image
2. Clone our git repository onto the pi
3. Activate our virtual environment
4. Open the /Senior-Design-Sailboat-Nav-2025/RPI-BLUETOOTH/ folder
5. Run the bluetooth.py script (python3 bluetooth.py)

OAK-D

1. Install depthai and the necessary dependencies
2. Plug into Raspberry Pi/Laptop
3. Activate our virtual environment
4. Open the /Senior-Design-Sailboat-Nav-2025/OAK-D/ folder
5. Run the script (Triton.py)

StereoPi

1. Install picamera v.2s into ports
2. Install Rasbian Debian 32-bit Legacy Edition onto an SD card
3. Move PiCamera open source file folder onto the SD card
4. Boot up PiCamera and install StereoVision and OpenCV via PiP
5. Move the stereopi directory into a local directory in the Pi
6. Run the 2_chess_cycle to calibrate cameras
7. Run the 3_pairs_cut to pair up the calibration photos
8. Run the 4_calibration.py file to properly calibrate cameras.
9. Run the 5_dm_tune file to calibrate the cameras
10. Run the 6_dm_video file to ensure correct disparity mapping
11. Run the 7_2d_map file to measure distance.

iPhone/Mac

1. Download XCode
2. Clone git repository
3. Open the /Senior-Design-Sailboat-Nav-2025/Triton/ folder in XCode
4. Connect iPhone to Mac via USB-C cable
5. Put iPhone in Developer Mode
6. Make sure that the app signature is a trusted developer in the iPhone running the app
7. Press the play button in the top left corner of XCode

Housing/Prints

1. Create the housing design
2. Print the STL files using PETG filament
3. Spray and cure prints with flex seal

GPS

1. Enter the Raspberry Pi configuration
2. Select “Interface Options”
3. Select “I6 Serial Port”
4. Disable the login shell
5. Enable the serial interface

Anemometer

1. Enter the Raspberry Pi configuration
2. Select “Interface Options”
3. Select “I2C”
4. Enable I2C
5. Connect the anemometer to the Raspberry Pi and ADC via the RJ-11 coupler and cable
6. Calibrate the wind direction

Testing Procedure

Circuit Diagram

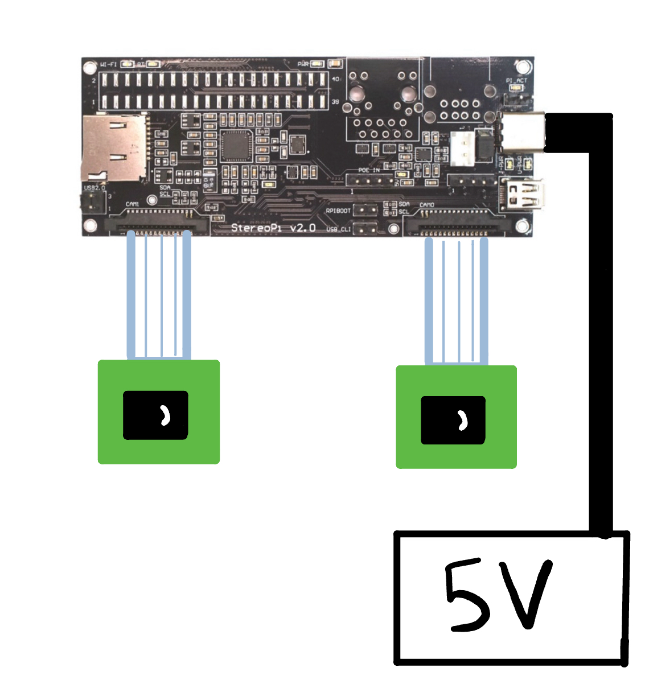
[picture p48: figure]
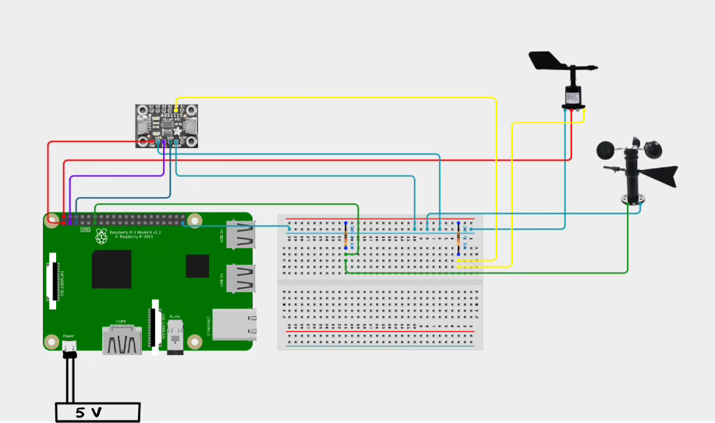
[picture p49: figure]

Hardware Pinout

Raspberry Pi | Peripheral
Pin 1, 3.3V | GPS 3.3V
Pin 9, GND | GPS GND
Pin 8, TX | GPS RX
Pin 10, RX | GPS TX
USB Port | OAK-D
Anemometer Data | Anemometer A0
GND Rail, Breadboard | Anemometer ADDR
Pin 3, SDA1 | Anemometer SDA
Pin 11 | Anemometer SCL
GND Rail, Breadboard | Anemometer GND
Power Rail, Breadboard | Anemometer VIN

OAK-D Camera:

1. Run the Python script for object tracking (python Triton.py)
2. Place the camera on a moveable object (desk chair)
3. Place someone in front of the camera from a set distance to simulate a boat’s presence
4. Have them slowly approach the camera
5. Have them step back and then slowly move to the left or right
6. The live feed on the monitor will place an outline around the person and show their distance and angle from the camera while also showing a depth reading for their distance
7. Have the person slowly walk away from the camera and observe as the warnings on the monitor go away
8. Move the camera around the room to show the changing depths of the environment
9. Play the video showcasing actual boat recognition capabilities of the camera

StereoPi:

1. Run script for depth mapping (7_)
2. Hold the cameras in such a position where they are pointing at the same direction
3. Place an object at a fixed distance
4. Move the object slowly towards the camera
5. Showcase the adjusting colors of the depth map to indicate an object approaching

iOS Application:

1. Plug in Triton and StereoPi
  a. Run the Oak-D python script, Anemometer python script, GPS C++ script, and Triton Bluetooth script (all will initiate on boot)
  b. Run the StereoPi depth mapping script and StereoPi Bluetooth script
2. Establish the Bluetooth connection to the Triton and StereoPi1
3. Showcase the organized tabs of the application with data from each module
4. Show the images from the OAK-D appearing on the application
5. Show the polar rendering of the depth data collected from the OAK-D and StereoPis
6. Show a representation of boats on the rendering while in the frame of the OAK-D (a person will substitute a boat for this testing)

Anemometer:

1. Take the anemometer outside to get wind data
2. Observe the direction of the wind being recorded within the iOS application

GPS:

1. Take the GPS outside to get a fix, and wait until the GPS module stops blinking every second
2. The iOS application will auto-connect to the Triton (Raspberry Pi)
3. Observe the data collected as it is displayed in the iOS application

Housing/Prints:

1. Showcase the design and print style of the main housing
2. Explain the choices made in the printing design
3. Demonstrate the properly sized and fitted holes for the modules that will be placed within our connected to the housing
4. Describe waterproofing techniques used and and considered (printing style, filament type, etc.)
5. Show the OAK-D mount with a perfect-fit slot
6. Showcase the design and housing for the StereoPi cameras
7. Repeat steps 2 - 4
8. Show the properly spaced and aligned holes for the cameras to produce accurate readings based on their calibration

Measurable Criteria

1. The OAK-D camera will show a live view with an ROI (region of interest) around a detected object to showcase the distance of detected objects on the Raspberry Pi through a monitor
2. The OAK-D camera will print the relevant ROI and object detected, and if the object is too close and location relative to the camera on the Raspberry Pi
3. The StereoPi cameras will be able to detect objects coming close to the camera
4. The iOS app will connect to the Raspberry Pi
5. The iOS app will showcase a polar map rendering of the depths and boats detected by the cameras with live updates
6. The application will receive the transmitted image taken from the OAK-D
7. The application will connect to the Anemometer, OAK-D, and StereoPi and display their relevant data
8. The main housing will be printed with properly sized holes for battery packs, clamps, and the OAK-D
9. The StereoPi housing will be printed with properly sized holes for the battery packs and properly spaced holes for the camera alignment
10. The GPS should receive a signal (fix) outside and record relevant information
11. The GPS will get data and transmit via DBus
  a. This includes: UTC Time, Longitude, Longitude Indicator, Latitude, Latitude Indicator, and Altitude
12. The anemometer will register wind-based data as the modules move and prepare the relevant data to be sent to the iPhone via Bluetooth

Score Sheet

Task | Completion (Y/N)
OAK-D displays a live feed | Y
OAK-D has a box outline around the tracked object/person | Y
OAK-D prints out a message that an object is too close with its distance accurate within 0.5m | Y
OAK-D shows a heat map of depth-based distances | Y
OAK-D image is uploaded and visible on the iOS app | Y
StereoPi showcases a depth mapping | Y
iPhone is able to detect and connect to the pi | Y
Polar rendering is loaded on the app with live updates of points as depth values change | Y
Application displays other module information | Y
Enclosure is printed with fitted holes | Y
Clamps fit in the enclosure | Y
Anemometer should send wind direction from outside | Y

Conclusions

This final testing aims to show the near end-to-end development of our project over the course of the year. We have been building off of each prototype and redefining our goals while also refining our modules to perform their tasks as efficiently as possible in order to ensure a smooth and helpful docking experience. OAK-D added new logic to better represent distance data while the StereoPi cameras refined their calibrations to be more accurate. We completed the implementation of the anemometer and were able to transmit the relevant data, thus completing our final module to be developed. The housing design was finalized with final prints being completed for open field testing. The iOS application was adjusted to handle all communication and data while also redesigning the rendering from the last prototype to be as visually clear and accurate as possible. Some software updates may still occur as feedback is given and more testing is done, however a major achievement was the completion of our hardware development. In this final month we aim to perfect the system as best we can with the modules and architecture we have designed for a complete docking assistant system to be used on open water.

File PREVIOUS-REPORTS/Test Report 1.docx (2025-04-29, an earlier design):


Senior Design

ENG EC 463

Boston University Electrical & Computer Engineering

The Triton Test Report


Team 25

Required Materials

Hardware:

- Raspberry Pi 3B
- USB-A to Micro cable
- Wall Block supplying 5V and 2.4 Amps DC OR 5V Rechargeable Battery
- Flora Wearable Ultimate GPS Module
- OAK-D S2
- iPhone
- Lightning to USB-C cable
- Mac

Software:

- GPS C++ Script
  - Record, parse, and place GPS data into a file
- Bluetooth Python Script
  - Connect the Triton (Raspberry Pi) to the iOS app
  - Read from the GPS file and send data via Bluetooth to the iOS application
- Camera Distance Recognition Python Script
  - Determine object distance
  - Alert if an object is within a certain distance relative to the camera
- iOS Application
  - Receive GPS data via Bluetooth from the Triton (Raspberry Pi)
  - Present the GPS data on the phone screen

Setup

There are two separate portions of our prototype: the iPhone running an iOS application and the Raspberry Pi running a Bluetooth GATT server, driving the GPS, and sending the GPS data over to the iPhone application via BLE. The GPS module is connected to the Raspberry Pi via UART.

Pre-Testing Setup:

Raspberry Pi

1. Flash the Raspberry Pi 3b’s SD card with the Raspberry Pi OS 64-bit image
2. Clone our git repository onto the pi
3. Activate our virtual environment
4. Open the /Senior-Design-Sailboat-Nav-2025/RPI-BLUETOOTH/ folder
5. Run the bluetooth.py script (python3 bluetooth.py)

iPhone/Mac

1. Download XCode
2. Clone git repository
3. Open the /Senior-Design-Sailboat-Nav-2025/Triton/ folder in XCode
4. Connect iPhone to Mac via lightning to USB-C cable
5. Put iPhone in Developer Mode
6. Make sure that the app signature is a trusted developer in the iPhone running the app
7. Press the play button in the top left corner of XCode

GPS

1. Enter the Raspberry Pi configuration
2. Select “Interface Options”
3. Select “I6 Serial Port”
4. Disable the login shell
5. Enable the serial interface

OAK-D

1. Install depthai and the necessary dependencies
2. Plug into Raspberry Pi/Laptop
3. Activate our virtual environment
4. Open the /Senior-Design-Sailboat-Nav-2025/OAK-D/ folder
5. Run the optimized.py script (python3 optimized.py)

Testing Procedure

Circuit Diagram


Hardware Pinout

Raspberry Pi | Peripheral
Pin 1, 3.3V | GPS 3.3V
Pin 9, GND | GPS GND
Pin 8, TX | GPS RX
Pin 10, RX | GPS TX
USB Port | OAK-D

Camera:

1. Run the Python script for object detection (python3 optimized.py)
2. Hold the camera at a fixed position
3. Place someone in front of the camera from a set distance
4. Have them slowly approach the camera
5. The live feed on the monitor will show that the person is getting too close and will display the person’s distance from the camera
6. Have the person slowly walk away from the camera and observe as the warnings on the monitor go away

GPS:

1. Take the GPS outside to get a fix, and wait until the GPS module stops blinking every second
2. The iOS application will auto-connect to the Triton (Raspberry Pi)
3. Observe the data collected as it is displayed in the iOS application

Measurable Criteria

1. The OAK-D camera will show a live view with an ROI (region of interest) grid to showcase if an object is too close on the Raspberry Pi through a monitor
2. The OAK-D camera will print which ROI detects an object that is too close and its distance from the camera on the Raspberry Pi
3. The GPS should receive a signal (fix) outside and record relevant information:
4. The GPS will parse and place desired data in a .txt file on the Raspberry Pi
  a. This includes: UTC Time, Longitude, Longitude Indicator, Latitude, Latitude Indicator, and Altitude
5. The Triton (Raspberry Pi) connects to the ios app via an internal Bluetooth module, discovers the GPS service, and subscribes to notifications on the GPS service’s characteristics
6. The app will receive and present the GPS data

Score Sheet

Task | Completion (Y/N)
OAK-D displays a live feed | Y
OAK-D has a grid showing distances | Y
OAK-D grid changes color as an object approaches | Y
OAK-D prints out a message that an object is too close with its distance | Y
OAK-D updates the color and stops printing when the object is far enough away | Y
GPS is able to get a fix | Y
Phone is able to detect and connect to the pi | Y
Data is uploaded and visible on the app | Y

Conclusions

This lab test aims to showcase a proof of concept demonstrating the workflow of our design. Our product aims to utilize various sensors and send their data to an application on an iPhone. The demonstration with the GPS module showcases a real-time example of what our product will look like in action. It exhibits how fast the app will update the GPS’s data and an early visual of how that data will be presented. The demonstration with the OAK-D camera displays a practical and potential application of its features utilizing its object detection and depth perception capabilities as well as a live-feed view. This is relevant since the OAK-D will be placed on the bow of the boat and is responsible for providing the sailor a clear view from the front of the boat since their vision can be obstructed due to the sails and mast while sailing. Additionally, it can be difficult to safely dock and avoid hitting anything with the bow. The live view will aid the sailor in avoiding obstacles and the live alerts of nearby objects can be turned into auditory signals for if the sailor does not notice something. While the final product will include a more refined system with more sensors, this demonstration establishes a model for the development of our product into its final stages.

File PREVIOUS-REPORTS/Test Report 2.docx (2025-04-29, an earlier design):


Senior Design

ENG EC 463

Boston University Electrical & Computer Engineering

The Triton Test Report 2


Team 25

Required Materials

Hardware:

- Raspberry Pi 3B
- USB-A to Micro cable
- Wall Block supplying 5V and 2.4 Amps DC OR 5V Rechargeable Battery
- OAK-D S2
- iPhone
- Lightning to USB-C cable
- Mac
- StereoPi Slim V2
- ABS/PLA Filament
- Servo Motor

Software:

- Bluetooth Python Script
  - Connect the Triton (Raspberry Pi) to the iOS application
  - Read from the OAK-D and send a photo via Bluetooth to the iOS application
- Camera Distance Recognition and Object Tracking Python Script
  - Determine object distance
  - Alert if an object is within a certain distance relative to the camera
  - Track a given target to give more detailed distance information
- iOS Application
  - Receive OAK-D serialized image over a Bluetooth connection
  - Present an alternative 2-D top-down display of detected objects near the boat
  - Demonstrate an improved UI with partitioned information on different pages
- StereoPi Software
  - Use a depth mapping to determine the distance of an object from the cameras

Setup

There are three primary portions of our prototype: the iPhone running an iOS application, the Raspberry Pi running a Bluetooth GATT server which controls the OAK-D camera and sends an image over to the iPhone application via BLE, and the printed enclosure for the project. There are other portions of the prototype that are still being integrated such as the StereoPi cameras which will use depth sensing, as well as other features of the iOS application.

Pre-Testing Setup:

Raspberry Pi

1. Flash the Raspberry Pi 3b’s SD card with the Raspberry Pi OS 64-bit image
2. Clone our git repository onto the pi
3. Activate our virtual environment
4. Open the /Senior-Design-Sailboat-Nav-2025/RPI-BLUETOOTH/ folder
5. Run the bluetooth.py script (python3 bluetooth.py)

iPhone/Mac

1. Download XCode
2. Clone git repository
3. Open the /Senior-Design-Sailboat-Nav-2025/Triton/ folder in XCode
4. Connect iPhone to Mac via lightning to USB-C cable
5. Put iPhone in Developer Mode
6. Make sure that the app signature is a trusted developer in the iPhone running the app
7. Press the play button in the top left corner of XCode
8. Upload the boat_visualization code to the application and have it on its own dedicated page

OAK-D

1. Install depthai and the necessary dependencies
2. Plug into Raspberry Pi/Laptop
3. Activate our virtual environment
4. Open the /Senior-Design-Sailboat-Nav-2025/OAK-D/ folder
5. Run the script (python distance_tracker.py)

Housing/Prints

1. Create the housing design
2. Print the STL files using ABS or PLA filament

StereoPi

1. Install cameras (model needed) into ports
2. Install Rasbian Debian 32-bit Legacy Edition onto an SD card
3. Move PiCamera open source file folder onto the SD card
4. Boot up PiCamera and install StereoVision and OpenCV via PiP
5. Move the stereopi directory into a local directory in the Pi
6. Run the 4_calibration.py file in order to calibrate cameras for depth mapping.
7. Run the 5_dm_tune file to calibrate the cameras
8. Run the 6_dm_video file

Testing Procedure

Circuit Diagram

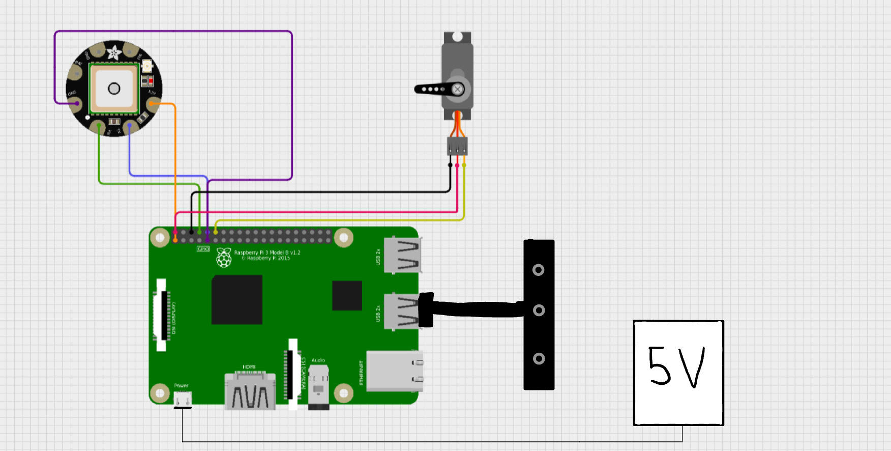
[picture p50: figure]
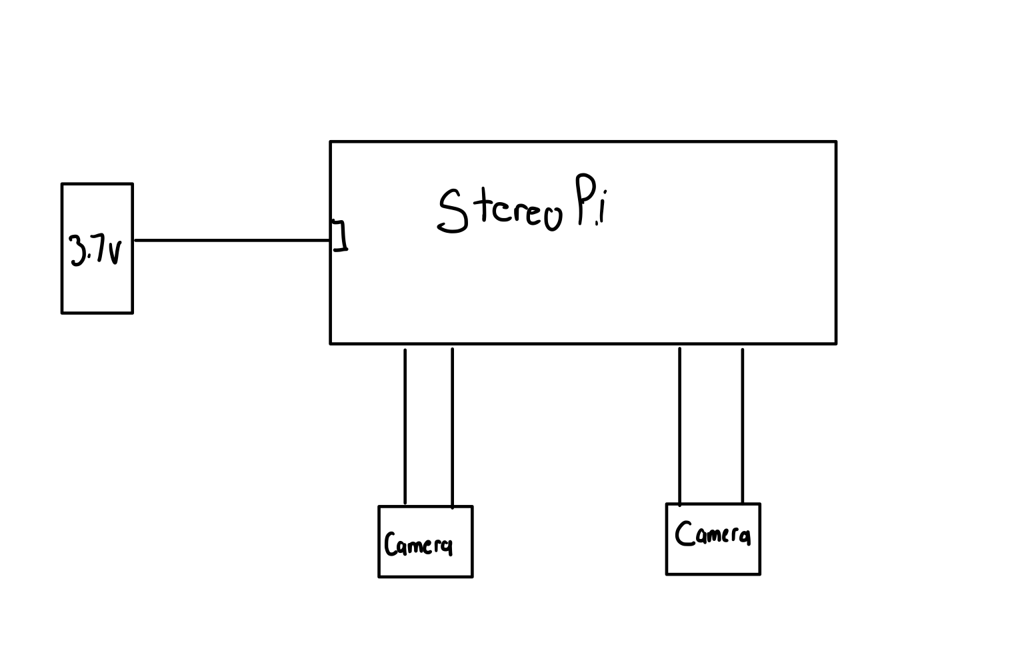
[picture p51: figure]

Hardware Pinout

Raspberry Pi | Peripheral
Pin 1, 3.3V | GPS 3.3V
Pin 9, GND | GPS GND
Pin 8, TX | GPS RX
Pin 10, RX | GPS TX
USB Port | OAK-D
Pin 4 5V | Servo 5V
Pin 6 GND | Servo GND
Pin 12 (GPIO 18) PWM0 | Servo PWM

Camera:

1. Run the Python script for object tracking (python distance_tracker.py)
2. Hold the camera at a fixed position
3. Place someone in front of the camera from a set distance
4. Have them slowly approach the camera
5. Have them step back and then slowly move to the left or right
6. The live feed on the monitor will place an outline around the person and show their distance and angle from the camera
7. Have the person slowly walk away from the camera and observe as the warnings on the monitor go away

iOS Application:

1. Run the python script for taking photos and bluetooth script (both will initiate on boot)
2. Establish the bluetooth connection to the RaspberryPi
3. Showcase the organized tabs of the application
4. Show the images from the OAK-D appearing on the application
5. Open the beta version of the top-down visualization

StereoPi:

1. Run script for depth mapping (6_dm_video)
2. Hold the cameras in such a position where they are pointing at the same direction
3. Place an object at a fixed distance
4. Move the object slowly towards the camera
5. Showcase the adjusting colors of the depth map to indicate an object approaching

Housing/Prints:

1. Showcase the design and print style of the housing
2. Explain the choices made in the printing design
3. Demonstrate the properly sized and fitted holes for the modules that will be placed within our connected to the housing
4. Describe waterproofing techniques used and and considered (printing style, filament type, etc.)
5. Show the OAK-D mount for the servo motor to eventually be used with the object tracking

Measurable Criteria

1. The OAK-D camera will show a live view with an ROI (region of interest) around a detected object to showcase the distance of detected objects on the Raspberry Pi through a monitor
2. The OAK-D camera will print the relevant ROI and object detected, and if the object is too close and location relative to the camera on the Raspberry Pi
3. The iOS app will connect to the Raspberry Pi
4. The iOS app will showcase a beta development visualization of the top-down object detection
5. The application will receive the transmitted image taken from the OAK-D
6. The housing will be printed with properly sized holes for mounting arms, clamps, and OAK-D
7. The StereoPi cameras will be able to detect objects coming close to the camera

Score Sheet

Task | Completion (Y/N)
OAK-D displays a live feed | ✓
OAK-D has a box outline around the tracked object/person | ✓
OAK-D prints out a message that an object is too close with its distance accurate within .05m | ✓
iPhone is able to detect and connect to the pi | ✓
OAK-D image is uploaded and visible on the iOS app | ✓
Top-Down visualization is loaded on the app | ✓
Enclosure is printed with fitted holes | ✓
Clamps fit in the enclosure | ✓
StereoPi showcases a depth mapping | ✓

Conclusions

This second prototype testing aims to show the development of our project from our initial testing last semester. We have built up from the first prototype, creating more complex functions with the OAK-D, an improved user interface on the iOS application, and the GPS module as a whole being completed. We also introduced the development of more modules to create a more complete system with a preliminary implementation of a servo motor, a printed design for the housing with waterproof capabilities in mind, a StereoPi for side view distance detection, and an alternative visualization of detected objects near the boat. These improvements and new modules show our iterative development to create a product that meets our desired design goals. Specifically, the object tracking as opposed to raw distance detection with the OAK-D will give more accurate data for how far objects are from the boat and will more seamlessly be incorporated to the alternative view. Additionally, the housing design shows the beginning of our final phase of development where our individual modules can come together into one package for the user to install. There are more developments to be made and modules to be developed this marks an effective step towards completing our project.

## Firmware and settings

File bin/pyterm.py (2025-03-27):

#!/home/triton/Senior-Design-Sailboat-Nav-2025/bin/python

"""Simple Python serial terminal
"""

# Copyright (c) 2010-2024, Emmanuel Blot <emmanuel.blot@free.fr>
# Copyright (c) 2016, Emmanuel Bouaziz <ebouaziz@free.fr>
# All rights reserved.
#
# SPDX-License-Identifier: BSD-3-Clause

# pylint: disable=broad-except
# pylint: disable=wrong-import-position

from argparse import ArgumentParser, FileType
from atexit import register
from collections import deque
from logging import Formatter, StreamHandler, DEBUG, ERROR
from os import environ, linesep, stat
from re import search
from sys import exit as sys_exit, modules, platform, stderr, stdout
from time import sleep
from threading import Event, Thread
from traceback import format_exc
from _thread import interrupt_main

# pylint: disable=import-error
# pylint: disable=import-outside-toplevel

from pyftdi import FtdiLogger
from pyftdi.ftdi import Ftdi
from pyftdi.misc import to_bps, add_custom_devices
from pyftdi.term import Terminal


class MiniTerm:
    """A mini serial terminal to demonstrate pyserial extensions"""

    DEFAULT_BAUDRATE = 115200

    def __init__(self, device, baudrate=None, parity=None, rtscts=False,
                 debug=False):
        self._terminal = Terminal()
        self._device = device
        self._baudrate = baudrate or self.DEFAULT_BAUDRATE
        self._port = self._open_port(self._device, self._baudrate, parity,
                                     rtscts, debug)
        self._resume = False
        self._silent = False
        self._rxq = deque()
        self._rxe = Event()
        self._debug = debug
        register(self._cleanup)

    def run(self, fullmode=False, loopback=False, silent=False,
            localecho=False, autocr=False):
        """Switch to a pure serial terminal application"""

        self._terminal.init(fullmode)
        print(f'Entering minicom mode @ { self._port.baudrate} bps')
        stdout.flush()
        self._resume = True
        # start the reader (target to host direction) within a dedicated thread
        args = [loopback]
        if self._device.startswith('ftdi://'):
            # with pyftdi/pyusb/libusb stack, there is no kernel buffering
            # which means that a UART source with data burst may overflow the
            # FTDI HW buffer while the SW stack is dealing with formatting
            # and console output. Use an intermediate thread to pop out data
            # out from the HW as soon as it is made available, and use a deque
            # to serve the actual reader thread
            args.append(self._get_from_source)
            sourcer = Thread(target=self._sourcer, daemon=True)
            sourcer.start()
        else:
            # regular kernel buffered device
            args.append(self._get_from_port)
        reader = Thread(target=self._reader, args=tuple(args), daemon=True)
        reader.start()
        # start the writer (host to target direction)
        self._writer(fullmode, silent, localecho, autocr)

    def _sourcer(self):
        try:
            while self._resume:
                data = self._port.read(4096)
                if not data:
                    continue
                self._rxq.append(data)
                self._rxe.set()
        except Exception as ex:
            self._resume = False
            print(str(ex), file=stderr)
            interrupt_main()

    def _get_from_source(self):
        while not self._rxq and self._resume:
            if self._rxe.wait(0.1):
                self._rxe.clear()
                break
        if not self._rxq:
            return bytearray()
        return self._rxq.popleft()

    def _get_from_port(self):
        try:
            return self._port.read(4096)
        except OSError as ex:
            self._resume = False
            print(str(ex), file=stderr)
            interrupt_main()
            return bytearray()
        except Exception as ex:
            print(str(ex), file=stderr)
            return bytearray()

    def _reader(self, loopback, getfunc):
        """Loop forever, processing received serial data in terminal mode"""
        try:
            # Try to read as many bytes as possible at once, and use a short
            # timeout to avoid blocking for more data
            self._port.timeout = 0.050
            while self._resume:
                if self._silent:
                    sleep(0.25)
                    continue
                data = getfunc()
                if data:
                    stdout.write(data.decode('utf8', errors='replace'))
                    stdout.flush()
                if loopback:
                    self._port.write(data)
        except KeyboardInterrupt:
            return
        except Exception as exc:
            print(f'Exception: {exc}')
            if self._debug:
                print(format_exc(chain=False), file=stderr)
            interrupt_main()

    def _writer(self, fullmode, silent, localecho, crlf=0):
        """Loop and copy console->serial until EOF character is found"""
        while self._resume:
            try:
                char = self._terminal.getkey()
                if fullmode and ord(char) == 0x2:    # Ctrl+B
                    self._cleanup(True)
                    return
                if self._terminal.IS_MSWIN:
                    if ord(char) in (0, 224):
                        char = self._terminal.getkey()
                        self._port.write(self._terminal.getch_to_escape(char))
                        continue
                    if ord(char) == 0x3:    # Ctrl+C
                        raise KeyboardInterrupt('Ctrl-C break')
                if silent:
                    if ord(char) == 0x6:    # Ctrl+F
                        self._silent = True
                        print('Silent\n')
                        continue
                    if ord(char) == 0x7:    # Ctrl+G
                        self._silent = False
                        print('Reg\n')
                        continue
                if localecho:
                    stdout.write(char.decode('utf8', errors='replace'))
                    stdout.flush()
                if crlf:
                    if char == b'\n':
                        self._port.write(b'\r')
                        if crlf > 1:
                            continue
                self._port.write(char)
            except KeyError:
                continue
            except KeyboardInterrupt:
                if fullmode:
                    if self._terminal.IS_MSWIN:
                        self._port.write(b'\x03')
                    continue
                self._cleanup(True)

    def _cleanup(self, *args):
        """Cleanup resource before exiting"""
        if args and args[0]:
            print(f'{linesep}Aborting...')
        try:
            self._resume = False
            if self._port:
                # wait till the other thread completes
                sleep(0.5)
                try:
                    rem = self._port.inWaiting()
                except IOError:
                    # maybe a bug in underlying wrapper...
                    rem = 0
                # consumes all the received bytes
                for _ in range(rem):
                    self._port.read()
                self._port.close()
                self._port = None
                print('Bye.')
        except Exception as ex:
            print(str(ex), file=stderr)
        finally:
            if self._terminal:
                self._terminal.reset()
                self._terminal = None

    @staticmethod
    def _open_port(device, baudrate, parity, rtscts, debug=False):
        """Open the serial communication port"""
        try:
            from serial.serialutil import SerialException
            from serial import PARITY_NONE
        except ImportError as exc:
            raise ImportError("Python serial module not installed") from exc
        try:
            from serial import serial_for_url, VERSION as serialver
            # use a simple regex rather than adding a new dependency on the
            # more complete 'packaging' module
            vmo = search(r'^(\d+)\.(\d+)', serialver)
            if not vmo:
                # unable to parse version
                raise ValueError()
            if tuple(int(x) for x in vmo.groups()) < (3, 0):
                # pysrial version is too old
                raise ValueError()
        except (ValueError, IndexError, ImportError) as exc:
            raise ImportError("pyserial 3.0+ is required") from exc
        # the following import enables serial protocol extensions
        if device.startswith('ftdi:'):
            try:
                from pyftdi import serialext
                serialext.touch()
            except ImportError as exc:
                raise ImportError("PyFTDI module not installed") from exc
        try:
            port = serial_for_url(device,
                                  baudrate=baudrate,
                                  parity=parity or PARITY_NONE,
                                  rtscts=rtscts,
                                  timeout=0)
            if not port.is_open:
                port.open()
            if not port.is_open:
                raise IOError(f"Cannot open port '{device}'")
            if debug:
                backend = port.BACKEND if hasattr(port, 'BACKEND') else '?'
                print(f"Using serial backend '{backend}'")
            return port
        except SerialException as exc:
            raise IOError(str(exc)) from exc


def get_default_device() -> str:
    """Return the default comm device, depending on the host/OS."""
    envdev = environ.get('FTDI_DEVICE', '')
    if envdev:
        return envdev
    if platform == 'win32':
        device = 'COM1'
    elif platform == 'darwin':
        device = '/dev/cu.usbserial'
    elif platform == 'linux':
        device = '/dev/ttyS0'
    else:
        device = ''
    try:
        stat(device)
    except OSError:
        device = 'ftdi:///1'
    return device


def main():
    """Main routine"""
    debug = False
    try:
        default_device = get_default_device()
        argparser = ArgumentParser(description=modules[__name__].__doc__)
        argparser.add_argument('-f', '--fullmode', dest='fullmode',
                               action='store_true',
                               help='use full terminal mode, exit with '
                                    '[Ctrl]+B')
        argparser.add_argument('device', nargs='?', default=default_device,
                               help=f'serial port device name '
                                    f'(default: {default_device}')
        argparser.add_argument('-b', '--baudrate',
                               default=str(MiniTerm.DEFAULT_BAUDRATE),
                               help=f'serial port baudrate '
                                    f'(default: {MiniTerm.DEFAULT_BAUDRATE})')
        argparser.add_argument('-w', '--hwflow',
                               action='store_true',
                               help='hardware flow control')
        argparser.add_argument('-e', '--localecho',
                               action='store_true',
                               help='local echo mode (print all typed chars)')
        argparser.add_argument('-r', '--crlf',
                               action='count', default=0,
                               help='prefix LF with CR char, use twice to '
                                    'replace all LF with CR chars')
        argparser.add_argument('-l', '--loopback',
                               action='store_true',
                               help='loopback mode (send back all received '
                                    'chars)')
        argparser.add_argument('-s', '--silent', action='store_true',
                               help='silent mode')
        argparser.add_argument('-P', '--vidpid', action='append',
                               help='specify a custom VID:PID device ID, '
                                    'may be repeated')
        argparser.add_argument('-V', '--virtual', type=FileType('r'),
                               help='use a virtual device, specified as YaML')
        argparser.add_argument('-v', '--verbose', action='count',
                               help='increase verbosity')
        argparser.add_argument('-d', '--debug', action='store_true',
                               help='enable debug mode')
        args = argparser.parse_args()
        debug = args.debug

        if not args.device:
            argparser.error('Serial device not specified')

        loglevel = max(DEBUG, ERROR - (10 * (args.verbose or 0)))
        loglevel = min(ERROR, loglevel)
        if debug:
            formatter = Formatter('%(asctime)s.%(msecs)03d %(name)-20s '
                                  '%(message)s', '%H:%M:%S')
        else:
            formatter = Formatter('%(message)s')
        FtdiLogger.set_formatter(formatter)
        FtdiLogger.set_level(loglevel)
        FtdiLogger.log.addHandler(StreamHandler(stderr))

        if args.virtual:
            from pyftdi.usbtools import UsbTools
            # Force PyUSB to use PyFtdi test framework for USB backends
            UsbTools.BACKENDS = ('pyftdi.tests.backend.usbvirt', )
            # Ensure the virtual backend can be found and is loaded
            backend = UsbTools.find_backend()
            loader = backend.create_loader()()
            loader.load(args.virtual)

        try:
            add_custom_devices(Ftdi, args.vidpid, force_hex=True)
        except ValueError as exc:
            argparser.error(str(exc))

        miniterm = MiniTerm(device=args.device,
                            baudrate=to_bps(args.baudrate),
                            parity='N',
                            rtscts=args.hwflow,
                            debug=args.debug)
        miniterm.run(args.fullmode, args.loopback, args.silent, args.localecho,
                     args.crlf)

    except (IOError, ValueError) as exc:
        print(f'\nError: {exc}', file=stderr)
        if debug:
            print(format_exc(chain=False), file=stderr)
        sys_exit(1)
    except KeyboardInterrupt:
        sys_exit(2)


if __name__ == '__main__':
    main()

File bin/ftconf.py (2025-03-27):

#!/home/triton/Senior-Design-Sailboat-Nav-2025/bin/python

"""Simple FTDI EEPROM configurator.
"""

# Copyright (c) 2019-2024, Emmanuel Blot <emmanuel.blot@free.fr>
# All rights reserved.
#
# SPDX-License-Identifier: BSD-3-Clause

from argparse import ArgumentParser, FileType
from io import StringIO
from logging import Formatter, StreamHandler, DEBUG, ERROR
from sys import exit as sys_exit, modules, stderr, stdout
from textwrap import fill
from traceback import format_exc
from pyftdi import FtdiLogger
from pyftdi.eeprom import FtdiEeprom
from pyftdi.ftdi import Ftdi
from pyftdi.misc import add_custom_devices, hexdump

# pylint: disable=too-many-locals
# pylint: disable=too-many-branches
# pylint: disable=too-many-statements


def main():
    """Main routine"""
    debug = False
    try:
        argparser = ArgumentParser(description=modules[__name__].__doc__)
        argparser.add_argument('device', nargs='?', default='ftdi:///?',
                               help='serial port device name')

        files = argparser.add_argument_group(title='Files')
        files.add_argument('-i', '--input', type=FileType('rt'),
                           help='input ini file to load EEPROM content')
        files.add_argument('-l', '--load', default='all',
                           choices=('all', 'raw', 'values'),
                           help='section(s) to load from input file')
        files.add_argument('-o', '--output',
                           help='output ini file to save EEPROM content')
        files.add_argument('-V', '--virtual', type=FileType('r'),
                           help='use a virtual device, specified as YaML')

        device = argparser.add_argument_group(title='Device')
        device.add_argument('-P', '--vidpid', action='append',
                            help='specify a custom VID:PID device ID '
                                 '(search for FTDI devices)')
        device.add_argument('-M', '--eeprom',
                            help='force an EEPROM model')
        device.add_argument('-S', '--size', type=int,
                            choices=FtdiEeprom.eeprom_sizes,
                            help='force an EEPROM size')

        fmt = argparser.add_argument_group(title='Format')
        fmt.add_argument('-x', '--hexdump', action='store_true',
                         help='dump EEPROM content as ASCII')
        fmt.add_argument('-X', '--hexblock', type=int,
                         help='dump EEPROM as indented hexa blocks')

        config = argparser.add_argument_group(title='Configuration')
        config.add_argument('-s', '--serial-number',
                            help='set serial number')
        config.add_argument('-m', '--manufacturer',
                            help='set manufacturer name')
        config.add_argument('-p', '--product',
                            help='set product name')
        config.add_argument('-c', '--config', action='append',
                            help='change/configure a property as key=value '
                                 'pair')
        config.add_argument('--vid', type=lambda x: int(x, 16),
                            help='shortcut to configure the USB vendor ID')
        config.add_argument('--pid', type=lambda x: int(x, 16),
                            help='shortcut to configure the USB product ID')

        action = argparser.add_argument_group(title='Action')
        action.add_argument('-e', '--erase', action='store_true',
                            help='erase the whole EEPROM content')
        action.add_argument('-E', '--full-erase', action='store_true',
                            default=False,
                            help='erase the whole EEPROM content, including '
                                 'the CRC')
        action.add_argument('-u', '--update', action='store_true',
                            help='perform actual update, use w/ care')

        extra = argparser.add_argument_group(title='Extras')
        extra.add_argument('-v', '--verbose', action='count', default=0,
                           help='increase verbosity')
        extra.add_argument('-d', '--debug', action='store_true',
                           help='enable debug mode')
        args = argparser.parse_args()
        debug = args.debug

        if not args.device:
            argparser.error('Serial device not specified')

        loglevel = max(DEBUG, ERROR - (10 * args.verbose))
        loglevel = min(ERROR, loglevel)
        if debug:
            formatter = Formatter('%(asctime)s.%(msecs)03d %(name)-20s '
                                  '%(message)s', '%H:%M:%S')
        else:
            formatter = Formatter('%(message)s')
        FtdiLogger.set_formatter(formatter)
        FtdiLogger.set_level(loglevel)
        FtdiLogger.log.addHandler(StreamHandler(stderr))

        if args.virtual:
            # pylint: disable=import-outside-toplevel
            from pyftdi.usbtools import UsbTools
            # Force PyUSB to use PyFtdi test framework for USB backends
            UsbTools.BACKENDS = ('pyftdi.tests.backend.usbvirt', )
            # Ensure the virtual backend can be found and is loaded
            backend = UsbTools.find_backend()
            loader = backend.create_loader()()
            loader.load(args.virtual)

        try:
            add_custom_devices(Ftdi, args.vidpid, force_hex=True)
        except ValueError as exc:
            argparser.error(str(exc))
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

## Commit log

2024-11-03 add in print on connection
2024-11-11 testing with scanning for all bluetooth devices
2024-11-12 change the button to a switch, add in stop advertising function
2024-11-14 Skeleton for GPS + Bluetooth of Main Raspberry Pi
    Implementation of Bluetooth and reading GPS for Raspberry pi. Still need to do peripheral but it is not that different.
2024-11-17 update bt test
    [pyvenv.cfg]
2024-11-19 Finish prototype
2025-02-24 OAK-D Distack-Track
    Models and captures fix
2025-02-25 update post prototype
2025-02-27 servo directory and files added
2025-03-12 Updated Visual with client feedback
    adjusted the FOV to be more accurate and added a preliminary heat map capabilities with areas shaded in based on object location and size
2025-03-18 Files needed to operate StereoPi
    6_dm_video is the only file needed to measure depth, however all other files are needed to check, calibrate, and modulate the depth settings of the stereopi camera
2025-03-18 add in sample dbus for GPS
2025-03-18 changes to support stereopi virtual env
    [pyvenv.cfg]
2025-03-24 fix the print statements
2025-03-26 scan and connect to devices
2025-04-01 ley add knots, add dbus for ane
2025-04-02 Create All_Camera_Rendering.swift
    This code now handles input for all 3 cameras with real distance values
2025-04-08 add switch for enabling and disabling live feed
2025-04-08 new version of camera. 7 runs distance tracking
2025-04-17 Create All_camera_10_points.swift
    adds multiple points for all cameras
2025-04-17 final-ish version of stereocameras. Calibration varies.
2025-04-17 comment out some print statements
2025-04-23 fix the connection for mult devices
2025-04-24 update code for mult devices to connect
2025-04-27 add in powerbank specs
2025-04-27 update the power bank documentation
2025-04-28 add in housing photos
    [Parts List Spreadsheet and Budget.xlsx]
2025-04-28 Housing Files
    [AneAttachment1.STL, SizedEnc1.STL, SizedLid2.STL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]
2025-04-28 put housing photos in the housing folder
2025-04-29 Update All_camera_10_points.swift
    made it so that all camera points are shown, comment out the StereoPiZoneView for the side that we don't want to see
